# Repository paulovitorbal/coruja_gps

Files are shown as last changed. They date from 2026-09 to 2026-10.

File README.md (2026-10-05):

# coruja_gps — detector de radares embarcado

Projeto pessoal de estudo em sistemas embarcados: um alertador de radares e semáforos
sobre **Raspberry Pi Pico 2 W**, com firmware em **C++17 / Pico SDK**.

Lê telemetria de um GPS NEO-M8N por UART, confronta a posição com uma base local de
18.294 pontos e sinaliza em quatro zonas por display, LED RGB periférico e buzzer.

## Arquitetura

Subsistemas do Coruja GPS e o caminho do dado

Quatro subsistemas, e o dado atravessa todos eles. Um CSV vira `radares.bin` na
estação de trabalho; o binário é publicado por um servidor mínimo; a configuração vai
para o cartão à mão; e o aparelho, ao clique, lê o cartão, busca a base pela rede e
**a grava de volta no cartão**.

Essa última parte é o RF05: *"baixá-la e salvá-la no cartão"*, com a troca atômica do
RF05.2 — baixa para `radares.tmp`, valida, renomeia a atual para `radares.bak` e só
então promove a nova. Queda de energia no meio de uma atualização não pode deixar o
aparelho sem base, porque a tela voltaria ao velocímetro normalmente e nada indicaria
a perda.

A cópia do `radares.bin` para o cartão à mão é só a **carga inicial**, e é opcional:
sem base o aparelho sobe, avisa, e o primeiro clique busca tudo pela rede.

No boot a base é lida **em fluxo** do cartão, decodificando direto no vetor de pontos.
Não é preferência de estilo: o arquivo tem 214 KB e o vetor ocupa 281 KB, e não existe
instante em que os dois caibam nos 181 KiB livres. Se o `radares.bin` não validar, o
firmware cai para o `radares.bak` — e avisa que está operando pela reserva.

**De onde vem o CSV é problema de quem monta** — o projeto não presume fonte nenhuma,
e por isso ela aparece no diagrama como uma nuvem anônima.

O que ainda não existe está tracejado e em cinza: gravar no cartão o que foi baixado,
o GPS, o display e o buzzer.

### Dentro do firmware

Módulos do firmware e a fronteira do hardware

A divisão que mais importa é a **fronteira do hardware**. Em verde, o que compila e é
testado no host — validação de formato, decodificação de quadratura, verificação de
download, análise de URL. São 180 testes que rodam sem placa nenhuma, e é o que torna
possível trabalhar neste projeto enquanto um módulo não chegou pelo correio.

Em laranja, o que só existe no Pico. Esses módulos são finos de propósito: o
`ClienteHttp` entrega pedaços a quem chamou em vez de acumular, e quem verifica é o
`nucleo`.

### Como regerar os diagramas

As fontes são versionadas em `docs/*.puml`; os SVG são gerados.

```bash
plantuml -tsvg docs/arquitetura.puml docs/firmware.puml
```

## Base de pontos

O firmware carrega `radares.bin`, um binário compacto de 12 bytes por ponto,
ordenado por latitude. Ele é produzido por `converte.py` a partir de um CSV no
**padrão iGO8**:

```
X,Y,TYPE,SPEED,DirType,Direction
-44.021044,-19.799916,1,30,1,257
```

```bash
python3 converte.py base_igo8.txt radares.bin
```

**Outro formato de entrada?** Escreva seu próprio parser — e não reimplemente o
formato binário. `formato_radares.py` expõe as enumerações e o escritor:

```python
from formato_radares import Ponto, TipoPonto, Sentido, escreve

pontos = [Ponto(lat=-19.799916, lon=-44.021044, limite=30, rumo=257,
                tipo=TipoPonto.RADAR_FIXO, sentido=Sentido.UNIDIRECIONAL)]
escreve(pontos, "radares.bin")
```

O `escreve()` cuida de quantização, flags, **ordenação por latitude** e CRC-32 — as
quatro coisas que um parser erraria em silêncio. A ordenação é a pior: a busca
binária do firmware depende dela e erra *sem avisar* se faltar.

Para testar, `formato_radares.le()` relê com as mesmas validações do firmware: se
aceita, o firmware carrega. Use `converte.py` (padrão iGO8) como modelo.

Obter a base é problema de quem monta: o projeto não presume fonte nenhuma.

---

## Alimentação e instalação no veículo

Alimentado pelo **pós-chave**, derivado na caixa de fusíveis. **O que entra no aparelho
é 12 V** — o conversor CC ficou para dentro.

Essa topologia mudou em 2026-09-21, e o motivo foi o buzzer. Ver `docs/adr/0009`.

```
bateria ─ caixa de fusíveis ─ piggyback ─ fusível 2 A ─ 1,5 mm² trançado (12 V)
                                                               │
                                              ┌────────────────▼──────────────┐
                                              │  conector de entrada, 3 vias  │
                                              └────────────────┬──────────────┘
                                                               │  dentro do gabinete
                                     ┌─────────────────────────┼───────────────┐
                                     │                         │               │
                          ┌──────────▼──────────┐   ┌──────────▼─────────┐     │
                          │ TVS 24 V ┬ 470 µF   │   │ conversor 12 V→5 V │     │
                          │ (bidir.) │ 50 V     │   │ NÃO isolado, ≥40 V │     │
                          └──────────┴──────────┘   └──────────┬─────────┘     │
                                                               │ 5 V           │ 12 V
                                                    ┌──────────▼─────────┐  ┌──▼──────────┐
                                                    │ Schottky → VSYS 39 │  │ buzzer, 2 v.│
                                                    └────────────────────┘  └─────────────┘
```

Consumo: **~145 mA em 12 V** (≈1,6 W) em condução normal, com pico de ~200 mA quando a
tensão cai a 9 V durante a partida. No lado de 5 V são ~162 mA normais e ~310 mA no
pior caso sustentado.

### O buzzer é alimentado em 12 V

O **SFM-20B é especificado para 3–24 V**. Em 5 V ele opera perto do mínimo da faixa; em
12 V, perto do meio — e para um piezo ativo a pressão sonora sobe bastante com a
tensão. O **R-32** registra a audibilidade com janelas abertas a 80 km/h como a
incerteza que sobrou do projeto, e nenhuma mudança de firmware a resolve. Esta resolve,
ou pelo menos ataca a causa certa.

O circuito não muda: o `BC337` tem `Vceo` de 45 V, a corrente é a mesma, e o
acionamento pela base continua em 3,3 V através de 1 kΩ. Não há roda-livre a
acrescentar — o buzzer é piezoelétrico, carga capacitiva.

**O `D2` foi removido em 2026-09-25**, justamente por isso: em antiparalelo com carga
capacitiva ele fica reversamente polarizado nos dois estados e nunca conduz. Fecha o
R-16.

O retorno do buzzer não vai ao GND por fio — vai **pelo transistor**. É chaveamento
pelo lado baixo: `+12 V → buzzer → coletor`, `emissor → GND`. Com o `Q1` cortado o
coletor sobe a ~12 V pelo próprio buzzer, que é por que, lendo a netlist parada, as
duas pernas parecem estar no mesmo potencial.

### 🔴 O 12 V agora está dentro do gabinete

Essa é a contrapartida, e é séria.

Antes, com o conversor do lado de fora, nada acima de 5 V entrava na caixa. Agora
entram 12 V, e eles convivem a centímetros de um trilho cujo máximo absoluto é 5,5 V.
**12 V no nó `VSYS` destrói Pico, GPS, display e cartão juntos.**

Três consequências práticas:

* **O conector de entrada tem 3 vias e o do buzzer tem 2**, e isso voltou a ser medida
  de **segurança**, não de robustez. A revisão anterior deste documento dizia que
  trocá-los "deixou de ser destrutivo" — aquilo valia enquanto só havia 5 V; não vale
  mais.
* **O fio de 12 V não é vermelho.** A convenção antiga mandava vermelho para 5 V *e*
  12 V; duas tensões com a mesma cor a três centímetros uma da outra é convite a erro.
  No `.fzz` o 12 V é **amarelo**.
* **O fio do coletor também está em 12 V** sempre que o transistor está cortado, ou
  seja, na maior parte do tempo. Não é só o `+12 V` que precisa de cuidado.

### Proteção da entrada de 12 V

O fusível protege o **fio** contra curto; ele não reage a sobretensão. Daí o **TVS
bidirecional de 24 V** (`P6KE24CA` ou `1.5KE24CA`) e um **eletrolítico de 470 µF /
50 V** em paralelo na entrada. O clamp de 24 V cai numa janela estreita: tem de ficar
acima de 16 V, porque a rede é 13,8 a 14,4 V com o motor ligado, e abaixo de 40 V,
porque é o máximo do conversor. O `24CA` clampa em 33,2 V.

**O que isso não resolve:** um *load dump* real chega a 60–120 V por até 400 ms, o que
contra um clamp de 33 V significa mais de 1 kW sustentado — nenhum TVS axial pequeno
sobrevive. O que ele cobre são os transientes frequentes e de baixa energia, que são os
que matam módulo barato no uso diário. Para o load dump, o projeto se apoia em o
alternador de carro moderno já clampar internamente em ~35 V, e isso é **suposição, não
medição**.

Dois detalhes que estragam tudo se errados: o sufixo **`CA`** significa bidirecional, e
a versão `A` montada ao contrário fica em curto permanente; e o **fusível vai antes** da
proteção no percurso do cabo, porque o modo de falha desejável de um TVS é curto.

### Três decisões que não são óbvias

**Pós-chave em vez de bateria direta com relé.** O pós-chave permanece energizado
durante a partida, então não há reinício na ignição. O relé foi descartado porque a
bobina consome 80–150 mA contra ~180 mA do aparelho inteiro — gastaria quase tanto
quanto liga — e o benefício dele (consumo parasita zero) já vem da chave de ignição.

**Fusível de 2 A, não 10 A.** Fusível protege o fio, não a carga. Com 10 A, uma falta
intermediária de 6 A não abriria o fusível mas aqueceria o condutor. O cabo de 1,5 mm²
suporta ~15 A e está sobredimensionado de propósito — mas o fusível acompanha a carga.

**Conversor não isolado, com entrada ≥ 40 V.** As duas condições importam por motivos
diferentes. A entrada ampla é pelo *load dump*: 60–120 V por dezenas de milissegundos
quando a carga do alternador sai, e módulos comuns de 35 V podem não sobreviver. O
**não isolado** é pelo buzzer: sem continuidade entre o negativo de 12 V e o do
aparelho, a corrente do buzzer não fecha pelo emissor do `Q1` e ele simplesmente não
toca. Um conversor isolado — que parece melhor no anúncio — quebraria o circuito.

E há um mínimo tão importante quanto o máximo: **a entrada tem de aceitar ~9 V**,
porque é onde o trilho cai durante a partida. Módulo com mínimo de 12 V reinicia o
aparelho a cada vez que se dá a chave.

### Ajuste opcional da saída do conversor

O Schottky derruba 0,3–0,45 V, então 5,00 V na saída deixam o `VSYS` em ~4,6 V. Se o
módulo for ajustável, regule para **5,35–5,45 V** e o `VSYS` chega a ~5,0 V. **Nunca
acima de 5,8 V** — o `VSYS` aceita no máximo 5,5 V. Meça antes de conectar.

Com o buzzer em 12 V isso deixou de ser crítico: o que dependia de tensão nominal saiu
do trilho de 5 V.

### Conectores do aparelho

| Conector | Vias | Pino A | Pino B |
| :--- | :---: | :--- | :--- |
| Entrada (único) | **3** (central sem uso) | **+12 V** | GND |

Desde 2026-09-25 o **buzzer é soldado direto**, sem conector: os dois fios saem da
placa e vão ao SFM-27 no painel da caixa. Com isso o aparelho tem **um só conector
externo**, e o risco de trocar um pelo outro — que a contagem de vias apenas
administrava — deixa de existir. O preço é serviço: separar a tampa exige dessoldar.

## Documentos

Leia nesta ordem:

| Documento | O que é |
| :--- | :--- |
| **`requirements.md`** | Requisitos funcionais e não-funcionais, matriz de interação homem-máquina e fluxo de telas. É a especificação. |
| **`bom_schematic.md`** | Lista de materiais e roteamento pino a pino, com as pinagens físicas conferidas nas placas. |
| **`formato_dados.md`** | Formato binário `radares.bin`, estratégia de carga em RAM e busca geográfica em dois estágios. |
| **`revisao_tecnica.md`** | Revisão técnica com rastreabilidade: o que foi achado, decidido e o que segue aberto. |
| **`montagem.md`** | Montagem física na caixa Patola PB-111: chassi, fixação, prateleira do GPS, isolamento e passagem de cabos. |
| **`previa_host.md`** | O produto inteiro rodando no host contra o simulador: o que a primeira integração validou, o defeito que achou e o que ela ainda não exercita. |
| **`roteiro_bancada.html`** | Procedimento de medição para imprimir, com quadro de registro das leituras. |

## Estado

**Decidido:** C++17 com Pico SDK · GPS+GLONASS a 4 Hz (piso 3 Hz) · conector JST-XH ·
GPS alimentado em 5 V · Zona de Semáforo silenciosa · buzzer escalonado em 3 faixas ·
LED RGB exclusivo de estado de via.

**Pendente de bancada** — ver `roteiro_bancada.html`:

| Item | Medida |
| :--- | :--- |
| R-05 | Vf dos LEDs verde e azul, e calibração das razões R:G (amarelo) e R:B (rosa) |
| R-13 | Tensão do trilho 3V3 sob carga, com backlight em 100% |
| R-17 | Consumo do buzzer e pinagem do transistor |
| R-14 | Inspeção: regulador de 3 pinos na placa GPS — **sem ele, 5 V destroem o módulo** |

**Escopo futuro:** desenho de telas e interfaces visuais.

## Esquemático no Fritzing

`coruja_gps.fzz` foi **gerado** e depois **ajustado à mão** no Fritzing:

```bash
python3 gera_fritzing.py    # ⚠️ sobrescreve o .fzz e DESCARTA o ajuste manual
```

> ⚠️ **O `.fzz` versionado contém trabalho manual que o gerador não reproduz:**
> roteamento dos fios com pontos de dobra, orientação de 16 peças e 4 notas rotulando
> os módulos representados por headers genéricos. Regerar descarta tudo isso.
>
> O gerador é a fonte da **netlist**; o `.fzz` é a fonte do **layout**. Ao mudar a
> fiação, o caminho é editar `NETS`, regerar num arquivo temporário, comparar as redes
> e então aplicar a mudança à mão no Fritzing — não sobrescrever.
>
> **Sem divergências conhecidas** (2026-09-21). O `.fzz` foi regerado a partir da
> netlist atual e depois roteado à mão, fechando o **R-29**.
>
> O anterior tinha acumulado cinco atrasos, e o pior era silencioso: ele trazia o LED
> como **cátodo comum**, que se liga de forma oposta ao ânodo comum real (R-33). Quem
> montasse por ele teria um LED que não acende, sem pista do motivo. Os outros quatro
> eram os GPIO de vermelho e azul trocados (R-35), resistores de 68 Ω onde as medições
> pediam 470 e 150 (R-05), leitor SD com 8 pinos em vez de 9 (R-40) e o display como
> ST7789 240×240.
>
> A lição que fica: um `.fzz` editado à mão **não avisa quando envelhece**. A defesa
> aqui foi comparar netlists entre o gerado e o versionado — vale repetir isso antes de
> cada montagem, e não confiar na memória de quantas correções entraram desde a última
> vez. O documento de referência para montagem continua sendo o `bom_schematic.md`.

A netlist vive em `NETS`, dentro de `gera_fritzing.py`, transcrita do
`bom_schematic.md`. Mudou a fiação? Edite ali e regenere.

O `fritzing_geo.py` calcula a posição real de cada pino: lê o SVG de breadboard da
peça, resolve o mapeamento `connector → svgId` do `.fzp` e aplica os transforms de
grupo. Sem isso os fios sairiam desenhados fora dos pinos. A escala da cena
(90 unidades por polegada) foi medida empiricamente contra um sketch existente.

**Dependências do gerador:** Fritzing instalado (a biblioteca de peças é lida de
`/Applications/Fritzing.app`) e um sketch com a peça do Pico, de onde ela é
reaproveitada e embutida no `.fzz`.

Quatro módulos não têm peça na biblioteca — NEO-M8N, ST7789, leitor microSD e
KY-040 — e são representados por headers fêmea rotulados, com a contagem correta de
pinos. A peça de microSD que existe na biblioteca tem **zero conectores**, é
inutilizável.

Na vista protoboard há fios reais, coloridos por rede: **preto** = GND,
**vermelho** = 5 V, **azul** = 3V3, e cores distintas por grupo de sinal. Esquemático
e PCB usam conexões diretas, exibidas como ratsnest.

## Datasheets

| Arquivo | O que é |
| :--- | :--- |
| `NEO-M8_datasheet_UBX-15031086-R14.pdf` | Datasheet u-blox do módulo GPS, **revisão R14**. É a revisão citada em todas as análises deste projeto. |
| `NEO-M8_datasheet_UBX-15031086-R11.pdf` | Mesmo documento, **revisão R11** — anterior. Mantida para comparação; em caso de divergência, vale a R14. |
| `adafruit-microsd-spi-sdio.pdf` | Guia do breakout microSD. Fonte da polaridade do `DET` (cartão presente = ALTO, pull-up de 4,7 kΩ na placa) e da confirmação de que há pull-up em todos os pinos SPI. |

Valores extraídos do datasheet do GPS e usados no projeto: limites elétricos
(`VCC` 2,7–3,6 V, `VIN` 0–`VCC`, `IPIN` 10 mA), correntes (`ICCP` 67 mA, tracking
30 mA, `ICC_RF` até 50 mA), faixa térmica (−40 a +85 °C, **operação e
armazenamento**) e teto de taxa de navegação (**5 Hz** em GPS+GLONASS, 10 Hz em
GNSS único).

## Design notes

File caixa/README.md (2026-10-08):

# Caixa impressa do coruja_gps

Modelo **paramétrico em OpenSCAD**. Caixa com batente interno e tampa que desce
por cima, presa por atrito — sem parafuso.

> **O que está versionado aqui é a fonte `.scad`.** Os STLs são artefato: cada
> render muda o arquivo inteiro e o git guarda cada versão por completo. São
> ~2 MB por corpo — a mesma razão pela qual o `.uf2` do firmware fica em
> *release* e não no repositório.

---

## Gerar os STLs

```sh
./gera_stl.sh                    # gera neste diretório
./gera_stl.sh ~/Downloads        # ou onde você quiser
```

Se o OpenSCAD não estiver no caminho padrão do macOS:

```sh
OPENSCAD=/usr/bin/openscad ./gera_stl.sh
```

Leva alguns minutos por peça — a geometria usa muita operação booleana.

O script **verifica e recusa** o resultado se houver material dentro de um vão
da traseira. Ver *"A verificação, e por que ela existe"* abaixo.

---

## As três peças

| Arquivo gerado | O que é |
| :--- | :--- |
| `caixa.stl` | corpo, **modelo A** — encoder · display · buzzer |
| `caixa_destro.stl` | corpo, **modelo B** — buzzer · display · encoder |
| `tampa.stl` | tampa, **a mesma para os dois**. Imprima uma só |

Externo 130 × 130 × 67 mm, parede e piso de 3 mm.

### Qual dos dois corpos

A geometria é a mesma; muda de que lado fica o encoder. **Não existe modelo
"certo" em abstrato** — depende de onde a caixa é montada no painel e de qual
mão alcança o botão. Simule o gesto antes de imprimir.

O `coruja_caixa_destro.scad` não duplica nada: ele inclui o principal e
sobrepõe um parâmetro.

### Material é decisão térmica, não estética

O painel do carro mediu **92 °C**. Isso elimina quase tudo — ver `montagem.md`
§2 na raiz do repositório.

---

## O conector de alimentação

Furo de **⌀12,5 mm na traseira, centrado**, para um **GX12-2** ("conector
aviação"). É o único conector externo do aparelho e traz os 12 V do pós-chave;
o conversor fica dentro do gabinete.

**Por que GX12 e não jack P4.** O TVS da entrada é bidirecional: ele clampa
transiente mas **não bloqueia inversão de polaridade**, que chega direta ao
conversor. A propriedade que importa é o **chaveamento mecânico** — só entrar
de um jeito. Barril 5,5 × 2,1 falha nisso, porque centro-positivo é convenção e
não garantia, e ainda não retém contra vibração.

**Centrado** porque existem as versões canhota e destra: no meio, a traseira
fica igual nas duas e a aparência não depende do lado de montagem.

**Acima** do rasgo do cartão e da abertura do USB, e não ao lado: o rasgo
atravessa o centro da parede, e naquela altura não havia como centralizar.

**Montagem:** pinos **machos na caixa**, fêmea no cabo. O cabo do carro fica
energizado com a chave ligada; a caixa desligada está morta, e contato exposto
pertence ao lado morto.

### ⚠️ Duas medidas ainda não conferidas

| | valor | o que é |
| :--- | ---: | :--- |
| `GX12_FURO` | 12,5 mm | ⌀12 nominal + 0,5 de folga de impressão |
| `GX12_VAO_PORCA` | 18,0 mm | diâmetro que permanece com 3 mm de parede, para a porca assentar |

Generosos de propósito enquanto não houver paquímetro sobre o conector
comprado: errar para mais custa folga, errar para menos arruína a peça depois
de impressa.

🔴 **E há uma terceira cota, que não tem valor aqui e pode reprovar o
desenho: o comprimento da rosca.** A espessura máxima de painel é ele menos a
altura da porca. Se sobrar pouco, os 3 mm de parede não fecham — e aí as outras
duas medidas não importam.

As três estão registradas como pendência **M-14** no `montagem.md`.

O reforço em volta do furo é um **anel**, e não um disco, por causa do segundo
valor — engrossar a parede sob a porca consome o comprimento útil de rosca.
Quem limita a espessura aqui não é a impressão, é a peça comprada.

---

## A verificação, e por que ela existe

Em **08/10/2026** o furo do conector foi acrescentado e a peça saiu com o rasgo
do cartão **tapado**: o anel de reforço, somado depois do `difference`, descia
por trás do recorte e o preenchia.

O que falhou não foi o render. Ele deu `Simple: yes`. Uma conferência de malha
procurou o furo e **o encontrou**, no lugar certo, com o diâmetro certo. As
duas verificações respondiam *"o furo existe?"* quando a pergunta era **"alguma
coisa sólida está passando por onde devia haver vão?"**. O defeito apareceu
quando alguém abriu o modelo e olhou.

Daí as duas guardas, que cobrem portas diferentes:

| guarda | onde | pega |
| :--- | :--- | :--- |
| `assert()` | no `.scad` | parâmetro que põe o anel em cima de um recorte, ou contra o batente |
| `verifica_caixa.py` | sobre o STL | material dentro de um vão, qualquer que seja a causa |

```sh
python3 verifica_caixa.py caixa.stl
```

O `gera_stl.sh` roda a segunda automaticamente e falha se ela reprovar.

> ⚠️ O verificador repete, em Python, as coordenadas dos recortes que o `.scad`
> calcula. Se elas mudarem lá e não aqui, ele passa a medir outra coisa — é o
> preço de verificar a **malha** em vez do modelo, e vale porque a malha é o
> que vai para a impressora.

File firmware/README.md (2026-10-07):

# Firmware — instalação, build e testes

Regra 6 do `coding_rules.md`. Este documento cobre o firmware; a montagem do
hardware está no `bom_schematic.md` e os requisitos no `requirements.md`.

## Dependências

| Ferramenta | Para quê | Instalação no macOS |
| :--- | :--- | :--- |
| CMake ≥ 3.13 | build dos dois alvos | `brew install cmake` |
| Ninja | gerador | `brew install ninja` |
| GoogleTest | suíte de testes | `brew install googletest` |
| Arm GNU Toolchain | compilar para o RP2350 | ver o aviso abaixo |
| Pico SDK ≥ 2.0 | biblioteca do alvo | `git clone --depth 1 https://github.com/raspberrypi/pico-sdk` |

> ⚠️ **Não use a formula `brew install arm-none-eabi-gcc`.** Ela instala um
> toolchain **só de C**: não vem com a biblioteca padrão de C++, e qualquer
> `#include <cmath>` ou `<cstdio>` falha com *"No such file or directory"*.
> Verificado com a 16.2.0 — não há um único `cmath` no Cellar.

O que serve é o toolchain oficial da Arm. O cask `gcc-arm-embedded` instala via
`.pkg` e **pede senha de administrador**, o que não funciona em terminal não
interativo. Dá para contornar extraindo o `.pkg` sem `sudo` e sem tocar em `/`:

```sh
brew fetch --cask gcc-arm-embedded          # só baixa, não instala
PKG=$(find ~/Library/Caches/Homebrew/downloads -name '*arm-gnu-toolchain*.pkg' | head -1)
pkgutil --expand-full "$PKG" /tmp/armx
mkdir -p ~/arm-gnu-toolchain && cp -R /tmp/armx/Payload/. ~/arm-gnu-toolchain/
export PATH="$HOME/arm-gnu-toolchain/bin:$PATH"
```

Ocupa ~1,0 GB. É o que está em uso aqui: **Arm GNU Toolchain 14.2.Rel1**.

O Pico SDK precisa do submódulo `lib/tinyusb` inicializado:

```sh
git -C "$HOME/pico-sdk" submodule update --init --depth 1 lib/tinyusb
```

### Variáveis de ambiente

Duas variáveis, e vale deixá-las permanentes em vez de exportar a cada sessão.

**fish** — em `~/.config/fish/config.fish`:

```fish
set -gx PICO_SDK_PATH $HOME/pico-sdk
fish_add_path $HOME/arm-gnu-toolchain/bin
```

**bash ou zsh** — em `~/.bashrc` ou `~/.zshrc`:

```sh
export PICO_SDK_PATH="$HOME/pico-sdk"
export PATH="$HOME/arm-gnu-toolchain/bin:$PATH"
```

Só o alvo Pico precisa delas. Os testes no host rodam sem nenhuma.

## Testes no host

Não precisa de ARM nem de placa. Ver `docs/adr/0001`.

```sh
cmake -S firmware -B firmware/build-teste -G Ninja -DCORUJA_TESTES=ON
cmake --build firmware/build-teste
ctest --test-dir firmware/build-teste --output-on-failure
```

### Dados de teste

A suíte roda **completa** num clone limpo. Ela usa uma fixture de 100 pontos
sintéticos versionada em `firmware/test/dados/fixture_igo8.txt`, que o CMake
converte em tempo de build chamando o próprio `converte.py` — então os testes
exercitam a cadeia inteira, conversor em Python e carregador em C++. Por isso
`python3` é dependência de build dos testes.

As coordenadas da fixture são pontos no Atlântico Sul aberto: **nenhuma é um
local real de fiscalização**. Ver `firmware/test/dados/README.md`.

Um teste extra carrega uma base completa e **se pula** por padrão. Para
exercitá-lo:

```sh
python3 converte.py sua_base.txt radares.bin
cmake -S firmware -B firmware/build-teste -G Ninja -DCORUJA_TESTES=ON \
      -DCORUJA_BASE_REAL="$PWD/radares.bin"
```

### Rodar um teste só

```sh
./firmware/build-teste/test/testes --gtest_filter='Decodificador.*'
./firmware/build-teste/test/testes --gtest_filter='*Wraparound*'
./firmware/build-teste/test/testes --gtest_list_tests   # lista tudo
```

### Cobertura

O mínimo do projeto é 80%.

```sh
cmake -S firmware -B firmware/build-cov -G Ninja \
      -DCORUJA_TESTES=ON -DCORUJA_COBERTURA=ON
cmake --build firmware/build-cov && ./firmware/build-cov/test/testes
cd firmware/build-cov && xcrun gcov -b src/CMakeFiles/coruja_nucleo.dir/nucleo/*.gcda
```

## Firmware para o Pico 2 W

```sh
cmake -S firmware -B firmware/build-pico -G Ninja -DPICO_BOARD=pico2_w \
      -DPICO_TOOLCHAIN_PATH="$HOME/arm-gnu-toolchain"
cmake --build firmware/build-pico
```

Com as variáveis já no config do shell. Sem elas, prefixe a linha do `cmake`
com `PICO_SDK_PATH=$HOME/pico-sdk PATH=$HOME/arm-gnu-toolchain/bin:$PATH`, que
funciona igual em fish, bash e zsh.

Sai `firmware/build-pico/coruja_gps.uf2`.

### Conferir o orçamento de memória

```sh
arm-none-eabi-size firmware/build-pico/coruja_gps.elf
```

Medição de 2026-09-17, com núcleo, log, LED e encoder:

| | Uso | De |
| :--- | ---: | ---: |
| Flash | **66,6 KiB** | 4096 KiB |
| SRAM | **284,2 KiB** | 520 KiB |
| Livre | **235,8 KiB** | |

A base é reserva estática de 24.000 pontos, 281,2 KiB. Ver `docs/adr/0006`
para por que isso **não** é o teto de 40.000 do formato. Para gravar: segure `BOOTSEL`, conecte o
USB e copie o `.uf2` para o volume `RP2350` que aparece.

O `stdio` sai pelo **USB-CDC**, não pela UART — a UART0 fica para o GPS. Para
ler o log: `screen /dev/tty.usbmodem* 115200`.

## Configuração

```sh
python3 scripts/gera_config.py --destino /Volumes/NOME_DO_CARTAO
```

Gera o `coruja.cfg` no cartão — **sem comentários**. Eles ficam no
`coruja.cfg.exemplo`, versionado, que é onde se lê o que cada chave faz.

> ⚠️ O firmware carrega o arquivo INTEIRO para a RAM, e os comentários deste
> gerador são quatro quintos dele. O arquivo enxuto tem ~200 bytes; com
> comentários, passava de 5 KB — e o leitor reservava 2 KB. O sintoma foi
> `sem configuração utilizável` no OTA e o aparelho sem nome na tela, com um
> arquivo que lia perfeitamente em qualquer outra ferramenta. Hoje o leitor e
> o gravador usam a **mesma** constante, e há teste que falha se divergirem.

**Só entra nele o que varia por instalação:**

| Chave | |
| :--- | :--- |
| `wifi_ssid_N` / `wifi_senha_N` | até 5 redes, **em ordem de prioridade** |
| `url_versao` | devolve uma linha de texto qualquer, comparada como texto |
| `url_base` | entrega o `radares.bin`, em HTTPS |
| `url_envio` | para onde subir log, viagens e infrações — **vazio desliga** |
| `token_aparelho` | o segredo que identifica esta unidade no servidor |

Brilho, fuso, tolerâncias e calibração do LED ficam **no código**. O critério está no
`docs/adr/0002`: se mudar o valor muda o comportamento de segurança, é especificação e
não configuração.

> ⚠️ O `coruja.cfg` contém a senha do Wi-Fi e o **cartão é removível e legível
> por qualquer um**. Isso não é mitigável por software: use uma rede de
> convidados ou de IoT para o OTA, nunca a rede principal.

#### Enviar dados ao servidor

O item **enviar dados** do menu sobe `coruja.log`, `infracoes.log` e os
registros de viagem, e **apaga do cartão só o que o servidor confirmar ter
guardado** — manda, pergunta o CRC-32, compara, e só então apaga. Confirmar
antes de destruir dispensa manifesto no cartão e nunca perde dado por falha de
rede.

Precisa das **duas** chaves. Só a URL significaria mandar para um servidor que
aceita de qualquer um, e o firmware recusa a configuração pela metade.

O `token_aparelho` vai em **todas** as requisições, não só nos envios: é por
ele que o servidor sabe qual unidade está falando, e é o que faz os registros
de dois carros não se misturarem. Se o servidor tiver lista de aparelhos, ele
recusa até o download da base sem token.

Ele vai no cabeçalho `X-Coruja-Token`, em **todas** as rotas.

Houve uma versão em que ia como `?t=` na URL dos GET, porque o `http_client`
do lwIP montava o pedido internamente e não tinha onde encaixar cabeçalho
próprio. Com TLS o transporte foi reescrito sobre `altcp`, o gancho passou a
existir, e o segredo saiu da URL — onde entrava no log de acesso do servidor
e de qualquer proxy no caminho.

> ✅ **O envio fala TLS** desde 2026-10-06, pelo mesmo `ClienteTls` do
> download. O certificado é verificado contra três raízes embutidas no
> firmware, e `MBEDTLS_SSL_VERIFY_REQUIRED` faz o handshake abortar quando
> não bate — o padrão do lwIP é `OPTIONAL`, que verifica e deixa passar.
>
> ⚠️ Isso exige **o relógio acertado**: sem hora, todo certificado é recusado
> por "ainda não vale". Ver `servidor_ntp`.

Um arquivo que **cresceu durante o envio** fica no cartão, mesmo entregue: o
`coruja.log` e o registro da viagem em curso continuam sendo escritos enquanto
a remessa roda, e apagar depois de confirmar N bytes destruiria os que vieram
depois. Ver `servidor/README.md` para o outro lado.

### Testes do gerador

```sh
python3 -m unittest discover -s scripts/testes
```

Usa `unittest` e não pytest: todo o Python deste projeto é **stdlib-only** por escolha.

Dois testes amarram o gerador ao parser em C++, que estão em linguagens diferentes: o
C++ lê o `coruja.cfg.exemplo` versionado e falha se o formato divergir, e o Python
compara suas constantes de limite com as do `Configuracao.h`.

## Organização

```
firmware/src/
├── placa/           Pinos.h — mapa único de GPIO, com invariantes em static_assert
├── nucleo/          lógica pura — tipos, Geo, base de radares, config
├── log/             Logger (interface) + LoggerConsole
├── led/             Cor, LedRgb (interface), LedRgbAnodoComum (hardware)
├── encoder/         DecodificadorQuadratura e AntiRepique (puros),
│                    Encoder (interface), EncoderKy040 (hardware)
├── app/             ModoTesteEncoder e ModoCalibracao — lógica de bancada
├── buzzer/          a fazer
├── armazenamento/   a fazer — cartão SD
├── display/         a fazer — módulo ainda não chegou
└── gps/             a fazer — módulo ainda não chegou
firmware/test/
├── apoio/           mocks compartilhados
└── <espelha src/>
```

A regra de pertencimento está no `docs/adr/0001`: **se precisa de um cabeçalho
do Pico SDK, vai para `coruja_portes`; caso contrário, fica no alvo portável.**

### Mapa de pinos

`src/placa/Pinos.h` é a **fonte única** dos 18 GPIO que o firmware usa. Nenhuma classe
declara pino próprio: `LedRgbAnodoComum` e `EncoderKy040` consomem as constantes de lá.

Três invariantes são garantidas pelo **compilador**, não por revisão de código:

| Invariante | Mensagem se violada |
| :--- | :--- |
| Nenhum GPIO usado duas vezes | `dois periféricos foram atribuídos ao mesmo GPIO` |
| Todo GPIO existe no cabeçalho e não é do CYW43 (23, 24, 25, 29) | `algum GPIO não existe no cabeçalho do Pico...` |
| A contagem de 18 não mudou sem revisão | `a contagem de GPIO mudou: confira o bom_schematic.md...` |

As três foram **verificadas quebrando o arquivo de propósito** e conferindo que o build
para com a mensagem certa. Os testes de `placa/PinosTest.cpp` acrescentam o que o
`static_assert` não alcança: eles **fixam os valores** contra a fiação documentada, para
que trocar o GPIO 2 pelo 3 falhe dizendo qual periférico mudou de pino.

## Estado

| Componente | Peça em mãos | Interface | Implementação | Testes |
| :--- | :---: | :---: | :---: | :---: |
| `placa` — mapa de pinos | — | — | ✅ | ✅ |
| `nucleo` — tipos, Geo, LimiarInfracao, BaseRadares, LeitorConfig | — | — | ✅ | ✅ |
| `log` — Logger, console, mock | — | ✅ | ✅ | ✅ |
| `led` — LED RGB | ✅ | ✅ | ✅ | ✅ |
| `encoder` — KY-040 | ✅ | ✅ | ✅ | ✅ |
| `app` — modos de teste e de calibração | ✅ | — | ✅ | ✅ |
| `buzzer` — piezo ativo + BC337 | ✅ | ⬜ | ⬜ | ⬜ |
| `armazenamento` — microSD | ✅ | ⬜ | ⬜ | ⬜ |
| `display` — 2,4" 320×240 | ❌ Correios | ⬜ | ⬜ | ⬜ |
| `gps` — NEO-M8N | ❌ Correios | ⬜ | ⬜ | ⬜ |

O parsing de NMEA e a máquina de estados de zona são lógica pura e podem ser
escritos e testados **antes** dos módulos chegarem, contra mocks.

### O que está verificado e o que não está

* **Verificado:** a suíte de **143 casos** no host, com cobertura medida — 97,9%
  de linhas e **100% de ramos** no carregador, e **100% de linhas e ramos** em
  `Geo`, `LimiarInfracao`, `DecodificadorQuadratura`, `AntiRepique` e
  `ModoTesteEncoder`.
* **Verificado:** a compilação para ARM, com o toolchain oficial 14.2.Rel1 e o
  `pico-sdk` 2.3.1. Sai `coruja_gps.uf2` de 126 KB, e o orçamento de memória
  passou a ser medido no linker.
* **Não verificado:** nada rodou numa placa. O `src/main.cpp` compila e liga,
  mas o comportamento do modo de teste — inclusive se esquerda e direita saem
  na ordem certa — só se confirma na bancada.

## Modo de bancada de rede — o que o `main.cpp` roda hoje

Exercita o caminho de atualização OTA de ponta a ponta, com tudo saindo no
console USB.

| Gesto | O que acontece |
|---|---|
| girar à **direita** | agrava o estado de via: segura → âmbar → rosa → perigo |
| girar à **esquerda** | alivia, no sentido inverso |
| **clicar** | conecta no Wi-Fi, consulta a versão, baixa se mudou, verifica, desconecta |

As quatro cores são as medidas no R-05, não valores nominais. O ciclo **satura
nas pontas** em vez de dar a volta: numa tela de diagnóstico, voltar sozinho ao
verde depois do vermelho esconde justamente que se chegou ao fim.

### A configuração vem do cartão, lida no clique

Nada de credencial embutida no firmware — o RNF03 é explícito, e ler no clique
tem uma consequência prática boa: **trocar o cartão passa a valer sem
reiniciar** o aparelho, e a configuração nunca fica velha em RAM.

Ponha na raiz do cartão o `coruja.cfg` gerado por:

```bash
python3 scripts/gera_config.py --permitir-http --destino /Volumes/NOME_DO_CARTAO
```

No boot o cartão é só **inspecionado** pelo pino `DET` (GPIO 14), e o estado
sai no console — presente ou ausente. Era o que faltava: sem essa linha, os
dois casos davam exatamente o mesmo console, e a diferença só aparecia depois,
disfarçada de outro erro.

#### Qual partição

A que **contém o arquivo**, não a primeira que for FAT. Num cartão de duas
partições com a configuração na segunda, o padrão do FatFs diria "sem
configuração" com o arquivo no cartão. Ver ADR 0007 e R-38.

Partição lógica dentro de estendida continua fora do alcance, e o log diz
quantas partições FAT foram montadas — é essa a pista quando o arquivo está no
lugar errado.

### O que sai no console

Na varredura, cada rede vista com canal e RSSI, e quais são da lista. Depois o
IP obtido, o `GET`, e — no download — os seis campos do cabeçalho do
`radares.bin` ao lado do que de fato chegou:

```
[base] ---- cabecalho do radares.bin recebido ----
[base]   magic        : 'RDR1' (0x31524452)
[base]   versao       : 1
[base]   exp_escala   : 5  (coordenadas x10^5)
[base]   tam_registro : 12 B
[base]   n_pontos     : 18294  (declarados)
[base]   crc32        : 0xD290D536  (do cabecalho)
[base] ---- e o que de fato chegou ----
[base]   bytes        : 219544  (219528 de dados)
[base]   pontos       : 18294  (confere)
[base]   crc32        : 0xD290D536  (confere)
```

### O que ainda não acontece

**Nada é gravado.** O destino do `radares.bin` é o cartão, e o leitor não
existe — o arquivo é verificado *em fluxo* e descartado. A versão confirmada
vive em RAM, então reiniciar faz o próximo clique baixar de novo.

A verificação em fluxo é obrigatória, não uma escolha: o arquivo tem 214 KB e
a base já reserva 281 KB dos 520 KB da placa. Guardar o download inteiro para
só então validá-lo não cabe — e não vai caber nem com o cartão, porque aí o
destino é o cartão.

O `VerificadorDownload` confere cabeçalho, contagem e CRC-32, **na mesma ordem**
do `carrega_base`. Ordenação por latitude e domínio de cada registro exigem os
bytes na mão e continuam com a carga. Um arquivo aprovado no download ainda
pode ser recusado na carga, e isso é correto: são perguntas diferentes.

### Limites conhecidos

- **Sem TLS.** Uma URL `https` é recusada com mensagem própria, não baixada em
  claro: baixar em claro o que diz `https` seria mentir sobre o RF05.2 no ponto
  exato em que ele importa. Ver o README do `servidor/`.
- **Sem IPv6.** `http://[::1]:8080/x` é recusado com motivo próprio, em vez de
  ir falhar no DNS com uma mensagem que não explica nada.
- **Conexão episódica.** O rádio sobe no clique e cai ao fim, sempre — inclusive
  nos caminhos de erro.

## Modo de calibração

O firmware atual roda o **modo de calibração**, que fecha a metade pendente do
**R-05**: as razões de PWM do âmbar e do rosa. Não precisa de GPS, cartão nem
display.

| Ação | Efeito |
| :--- | :--- |
| **Girar** | ajusta o canal variável do item atual, 5 de duty por detente |
| **Clicar** | avança: vermelho → verde → azul → âmbar → rosa → volta |

Nas compostas o **vermelho fica fixo em 100%** e o encoder move o outro canal.
Não é simplificação: é a forma como `led/Calibracao.h` guarda as cores, com o
canal vermelho em 255 e só o secundário variando.

Ao dar a volta, o log imprime o bloco pronto para transcrever:

```
[INFO ] calib: ---- calibracao do R-05, para o gera_config.py ----
[INFO ] calib:   duty do verde no ambar : 0.45
[INFO ] calib:   duty do azul no rosa   : 0.60
[INFO ] calib:   (o vermelho das duas fica em 1,00 por construcao)
[INFO ] calib:   canais isolados: R=1.00  G=1.00  B=1.00
```

> ⚠️ **Julgue o rosa ao lado do vermelho, e sob sol direto.** É o item crítico:
> se os dois se confundirem, a faixa de margem parece Zona de Perigo ao
> motorista, que é o oposto da intenção do RF03.4.

De passagem ele valida a fiação inteira: os três canais acendem isolados —
inclusive o **verde**, que o modo de teste anterior nunca acendia — e o giro e
o clique exercitam o encoder. Se o giro à direita **diminuir** o brilho em vez
de aumentar, `CLK` e `DT` estão invertidos: construa com
`EncoderKy040(true, /*invertido=*/true)` em vez de mexer na fiação.

### O modo de teste anterior continua disponível

Esquerda vermelho, direita azul, clique apaga. Troque `ModoCalibracao` por
`ModoTesteEncoder` no `src/main.cpp` — a classe continua no projeto e testada.

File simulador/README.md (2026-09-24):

# Simulador de GPS

Faz o papel do NEO-M8N numa porta serial, para que o firmware possa ser
exercitado sem o módulo — e sem sair de casa.

```bash
python3 simula_gps.py
```

Ele cria um terminal virtual e imprime o caminho do dispositivo. Qualquer
programa abre esse caminho como abriria `/dev/cu.usbserial…`:

```
  rota  : rota_eixao.csv, 16.53 km por sentido
  volta : 33.05 km (ida e volta)
  serial: /dev/ttys012
  taxa  : 4 Hz
  teclas: a acelera · d desacelera · 0 para · q sai

  volta   1 |  12.4% | 60.0 km/h | norte | -15.82931,-47.92104
```

## A rota não foi inventada

Ela é a linha de centro do **Eixão (DF-002)**, derivada de 450 nós do
OpenStreetMap — `ref=DF-002` na caixa do Plano Piloto. O `gera_rota.py`
consulta a Overpass API e escreve o `rota_eixao.csv`, que é versionado para o
simulador rodar sem rede.

Coordenadas inventadas passariam por reais e ninguém saberia. Um simulador que
anda por uma via imaginária valida o firmware contra ficção — e o pior é que
ele *pareceria* funcionar.

**Por que isso importa na prática:** ao longo de uma volta o veículo passa a
menos de 300 m de **50 radares reais** da base, sendo 35 a menos de 100 m. A
maioria é de 60 km/h, com alguns de 80 — e há um de limite `0`, que é o caso
que o R-19 levantou. Dá para exercitar as quatro zonas só variando a
velocidade.

## Duas decisões que o simulador copia do módulo real

**Rumo em branco com o veículo parado.** O NEO-M8N não informa direção sem
deslocamento. Reproduzir isso é metade do valor do simulador: é o caso que
quebra parser desatento, que trataria o campo vazio como zero e apontaria o
veículo para o norte.

**4 Hz**, que é a taxa do RF01.4. Emitir mais rápido esconderia problemas de
acompanhamento que o aparelho teria no carro.

## Limitações honestas

**A linha de centro é média das duas pistas.** Elas ficam a ~40 m uma da
outra, e a suavização deixa uma irregularidade residual de ~5° por trecho. Para
alertas com raio de 300 m isso é ruído; para julgar filtro de rumo por sentido,
não confie.

**Não há ruído, nem perda de fix, nem cold start.** Todo fix é válido. Testar
o RF07 e o comportamento sem sinal exige acrescentar isso — hoje não está.

**A hora é a do computador**, em UTC, não a do relógio do satélite.

## Regerar a rota

```bash
python3 gera_rota.py                      # consulta a Overpass
python3 gera_rota.py --de-arquivo x.json  # de uma resposta ja baixada
```

O gerador tenta três espelhos: o principal devolve `504` sob carga com alguma
frequência, e isso não é motivo para desistir da rota.

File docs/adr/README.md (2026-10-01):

# Registros de Decisão Arquitetural

Formato Nygard: contexto, decisão, consequências. Um arquivo por decisão,
numerado e imutável — decisão revista ganha um ADR novo que **supera** o
anterior, e o antigo fica marcado como superado em vez de ser editado.

| # | Decisão | Data | Estado |
| :--- | :--- | :--- | :--- |
| [0001](0001-alvo-duplo-host-e-pico.md) | Um CMake com alvo duplo: testes no host, firmware no RP2350 | 2026-09-17 | aceita |
| [0002](0002-onde-vive-a-configuracao.md) | Credenciais no cartão, calibração compilada | 2026-09-17 | aceita |
| [0003](0003-idioma-dos-identificadores.md) | Domínio em português, infraestrutura em inglês | 2026-09-17 | aceita |
| [0004](0004-testes-contra-a-base-real.md) | Fixture sintética versionada, em vez de pular testes | 2026-09-17 | aceita |
| [0005](0005-taxa-de-amostragem-do-encoder.md) | Encoder amostrado a 1 ms, não no laço de 4 Hz | 2026-09-17 | aceita |
| [0006](0006-orcamento-de-memoria-verificado-pelo-compilador.md) | `Ponto` em 12 B e capacidade separada do teto de formato, com `static_assert` | 2026-09-17 | aceita |
| [0007](0007-fatfs-adotado-em-vez-de-escrito.md) | FAT32 por biblioteca adotada, e a partição escolhida pelo arquivo | 2026-09-20 | aceita |
| [0008](0008-formato-do-cartao.md) | Cartão em FAT32 com MBR, pela compatibilidade entre os três sistemas | 2026-09-20 | aceita |
| [0009](0009-doze-volts-dentro-do-gabinete.md) | 12 V entra no gabinete, e o buzzer é alimentado nele | 2026-09-21 | aceita |
| [0010](0010-sem-card-detect.md) | Sem card detect: cartão ausente e ilegível são o mesmo caso | 2026-09-22 | aceita |
| [0011](0011-medir-antes-de-mitigar.md) | Montar com o que está em mãos; mitigações térmicas contingentes à medição | 2026-10-01 | aceita |

## Decisões anteriores a este diretório

Três decisões de peso foram tomadas e justificadas antes de existir código, e
estão registradas nos documentos de especificação em vez de aqui. Não foram
duplicadas de propósito — o registro canônico é o documento:

| Decisão | Onde está | Achado |
| :--- | :--- | :--- |
| Carga integral em RAM, sem particionamento | `formato_dados.md` §1 | R-02 |
| Distância equirretangular em vez de Haversine | `formato_dados.md` §4.1 | R-03 |
| C++17 com Pico SDK em vez de MicroPython | `formato_dados.md` §9 | L-08 |

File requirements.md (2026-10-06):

# 📑 Documentação de Requisitos e Interações Homem-Máquina (IHM)

**Projeto:** Detector de Radares GPS Inteligente
**Plataforma:** Raspberry Pi Pico 2 W (RP2350) — **C++17 com Pico SDK**
**Revisão:** 2 — 2026-09-15
**Base de dados:** 18.294 pontos (`base_igo8.txt` → `radares.bin`)

> **Revisão 2:** incorpora as correções de `revisao_tecnica.md` e as decisões de
> `formato_dados.md`. Rastreabilidade ao final do documento. Itens marcados
> **[SUPOSIÇÃO]** são recomendações aplicadas na ausência de decisão explícita —
> revisar e confirmar ou reverter.

## 🎯 1. Escopo e Objetivos do Sistema

O objetivo do sistema é atuar como um assistente de condução inteligente embarcado. Ele
deve calcular a telemetria do veículo via satélite (coordenadas, velocidade e rumo) e
confrontar esses dados em tempo real com uma base local de radares e semáforos para
prever a aproximação dos pontos de interesse e emitir alertas visuais, periféricos e
sonoros de forma contextualizada.

A base de origem é distribuída no padrão iGO8 (`base_igo8.txt`) e é convertida em um
formato binário compacto (`radares.bin`) **fora do dispositivo**, conforme RF06.

---

## 📋 2. Requisitos Funcionais (RF)

### [RF01] Telemetria em Tempo Real

O sistema deve ler os dados brutos NMEA do módulo GPS NEO-M8N a uma taxa de amostragem
**nominal de 4 Hz, com piso aceitável de 3 Hz** *(ver RF01.4)*, extraindo:

* Latitude e Longitude em graus decimais.
* Velocidade atual convertida para km/h.
* Rumo (azimute) do veículo em graus (0,0° a 359,9°).

#### [RF01.1] Sentença e validação

* O parser deve aceitar **`$GNRMC` e `$GPRMC`**. O talker `GN` só aparece com
  multi-GNSS ativo; em modo GPS-only a sentença vira `GP` e um parser fixado em `GN`
  não casaria nada — falha silenciosa total.
* Toda sentença deve ter o **checksum NMEA validado** antes do uso. Sentença com
  checksum inválido é descartada silenciosamente e não atualiza a telemetria.
* O campo de status da RMC (`A` = válido / `V` = alerta) deve ser verificado; sem fix
  válido, aplica-se o RF07.

#### [RF01.2] Configuração obrigatória do módulo

Configuração de fábrica, conforme datasheet UBX-15031086 (Tabela 15): **UART a 9600 bps,
8 bits, sem paridade, 1 stop bit, autobauding desabilitado**, com **sete** sentenças NMEA
ativas — `GGA, GLL, GSA, GSV, RMC, VTG, TXT`. A GSV sozinha gera múltiplas sentenças
quando há muitos satélites visíveis, e o total por época passa facilmente de 500 bytes.
A 9600 bps (960 B/s), **nem 1 Hz cabe com folga** e 4 Hz é impossível.

O firmware deve enviar, e reenviar a cada boot:

| Comando UBX | Ação |
| :--- | :--- |
| `CFG-RATE` | período de medição = **250 ms (4 Hz)** — ver RF01.4 |
| `CFG-PRT` | baud rate da UART = **115200 bps** |
| `CFG-MSG` | desabilitar todas as sentenças **exceto RMC** |
| `CFG-CFG` | persistir configuração (BBR e EEPROM da placa, se presente) |

#### [RF01.4] Modo GNSS e taxa de navegação

O datasheet do NEO-M8N (UBX-15031086, Tabela 1) limita a taxa máxima de navegação
conforme o modo de GNSS:

| Modo GNSS | Taxa máx. | Precisão horiz. | Cold start | Talker NMEA |
| :--- | :---: | :--- | :---: | :---: |
| **GPS + GLONASS** *(padrão de fábrica)* | **5 Hz** | 2,5 m · 2,0 m c/ SBAS | 26 s | `$GNRMC` |
| GPS apenas | 10 Hz | 2,5 m · 2,0 m c/ SBAS | 29 s | `$GPRMC` |

Os 5 Hz da especificação original eram **exatamente o teto** do módulo no modo padrão,
sem nenhuma folga: qualquer degradação por temperatura ou sinal fraco derrubaria a taxa
efetiva abaixo do requisito, sem aviso.

##### ✅ Configuração adotada (confirmada em 2026-09-15)

| Parâmetro | Valor |
| :--- | :--- |
| Modo GNSS | **GPS + GLONASS concorrente** (mantém o padrão de fábrica) |
| Taxa nominal | **4 Hz** (`CFG-RATE` = 250 ms) — 20% de folga sob o teto |
| **Piso aceitável** | **3 Hz** — abaixo disso é falha (RF01.5) |

##### Justificativa geométrica da banda

Deslocamento do veículo por amostra, contra o raio de alerta de 300 m:

| Velocidade | 4 Hz | 3 Hz | Pior caso como % do raio |
| :--- | ---: | ---: | ---: |
| 100 km/h (27,8 m/s) | 6,9 m | 9,3 m | 3,1% |
| **120 km/h** (33,3 m/s — maior limite da base) | 8,3 m | **11,1 m** | **3,7%** |

O custo do piso de 3 Hz é **no máximo um período de amostragem de antecedência**, ou
seja 333 ms — que a 120 km/h são 11 m dos 300 m de raio. O alerta efetivo cairia de
300 m para ~289 m no pior caso, contra uma janela de aviso de 9,0 s a essa velocidade.
Irrelevante para a função.

Manter a recepção concorrente preserva a disponibilidade de satélites em cânion urbano,
que é onde está a maior parte dos pontos da base.

> *Alternativa registrada:* se em uso real houver perda de fix recorrente em cidade,
> GPS-apenas tem **precisão horizontal idêntica** (2,5 m) e teto de 10 Hz, ao custo de
> 3 s de cold start e 1 dBm de sensibilidade. Como o RF01.1 aceita os dois talkers, a
> troca não exige alteração no parser.

#### [RF01.5] Monitoramento da taxa de atualização

Definir um piso de 3 Hz só tem valor se o sistema souber quando o cruzou. O firmware
deve medir a taxa efetiva de fixes válidos em janela deslizante de 3 s e classificar:

| Faixa medida | Estado | Ação |
| :--- | :--- | :--- |
| ≥ 3,5 Hz | **nominal** | operação normal |
| 3,0 a 3,5 Hz | **degradado** | opera normalmente; registra o evento |
| **< 3,0 Hz** sustentado por 5 s | **falha** | ver RF07 e a tentativa de recuperação abaixo |

##### Por que este requisito existe

Taxa abaixo do nominal **quase nunca** significa que o receptor está com dificuldade — o
NEO-M8N entrega a taxa configurada enquanto tiver fix, ou perde o fix. As causas reais,
em ordem de probabilidade:

1. **`CFG-RATE` não foi aplicado** e o módulo continua no padrão de 1 Hz.
2. **UART saturada** — sentenças demais habilitadas ou baud rate baixo, com frames
   truncados (ver RF01.2).
3. Parser descartando sentenças por checksum inválido (ruído elétrico na linha).
4. Dificuldade genuína do receptor, em condições extremas.

Ou seja: **este monitor é primariamente uma verificação de que a configuração do RF01.2
pegou**, e só secundariamente um indicador de saúde. É a diferença entre descobrir um
erro de configuração na bancada e descobri-lo depois de meses rodando a 1 Hz sem notar.

##### Diagnóstico e recuperação

* Contar **separadamente** as sentenças recebidas com checksum inválido. Isso distingue
  "o GPS não está enviando" (causas 1, 2, 4) de "estamos falhando em interpretar"
  (causa 3) — dois problemas com correções opostas.
* Ao detectar estado de **falha**, reenviar a sequência de configuração UBX do RF01.2
  uma vez antes de escalar para o RF07. Cobre o caso de configuração perdida.
* A taxa medida e a contagem de checksums inválidos devem estar visíveis em algum ponto
  da interface (tela de diagnóstico ou tela de boot), não apenas em log.

#### [RF01.3] Conversão de velocidade

A sentença RMC entrega velocidade em **nós**. Conversão obrigatória:
`km/h = nós × 1,852`.

A velocidade usada na decisão de zona (RF03) deve passar por **média móvel de 3
amostras** para suprimir jitter. A latência resultante **varia com a taxa efetiva**:
750 ms a 4 Hz e 1000 ms no piso de 3 Hz.

Essa latência afeta apenas a comparação contra o limite da via (RF03). O **cálculo de
distância usa sempre o fix instantâneo**, nunca a média — a posição não deve ser
suavizada, ou o alerta atrasaria junto.

> *Referência de datasheet (Tabela 1):* precisão de velocidade de **0,05 m/s**
> (0,18 km/h) e de rumo de **0,3°**. A precisão de velocidade é excelente para a
> comparação contra o limite da via no RF03. A de rumo **não é qualificada por
> velocidade mínima** no datasheet, então o limiar de 5 km/h do RF02.3 permanece
> julgamento de engenharia, não especificação.

---

### [RF02] Processamento Geográfico Inteligente

O sistema deve calcular continuamente a distância entre o veículo e os pontos da base,
identificando o alvo válido mais próximo.

#### [RF02.1] Busca em dois estágios

Calcular a distância para todos os 18.294 pontos a cada ciclo não cabe no orçamento de CPU.
A base é mantida em RAM **ordenada por latitude crescente** (RF06) e a busca opera em
dois estágios:

1. **Busca binária** pela faixa de latitude `[lat − 300 m, lat + 300 m]` — a constante
   é 269 unidades de 10⁻⁵ grau. Custo: ~15 comparações de inteiros.
2. **Varredura da faixa** com descarte por longitude em **aritmética inteira**, sem
   trigonometria. O limiar de longitude depende de `cos(lat)` e deve ser calculado
   **uma vez por fix**, nunca por ponto.
3. **Cálculo de distância apenas nos sobreviventes.**

Custo medido sobre a base real, pior caso: 96 candidatos na faixa de latitude, dos quais
**24 chegam ao cálculo de distância**. Ver `formato_dados.md` §4.

> A ordenação por **latitude** e não longitude é deliberada: o grau de latitude mede
> 111,32 km em qualquer ponto do globo, então o limiar da busca binária é constante. Em
> longitude ele dependeria de cos(lat) e o índice ficaria distorcido de norte a sul.

#### [RF02.2] Cálculo de distância e precisão numérica

A FPU do RP2350 é de **precisão simples**. Um `float` tem ~7,2 dígitos significativos,
enquanto uma coordenada como `-23.537216` precisa de 8 — e a fórmula de Haversine
subtrai números próximos entre si, ampliando o erro justamente em distâncias curtas.

* **Obrigatório:** o cálculo deve operar sobre **diferenças** de coordenadas, não sobre
  valores absolutos em precisão simples.
* **Fórmula adotada — equirretangular:** erro inferior a 0,01% na faixa de 300 m, e
  custo de um `sqrtf` contra 2 sin + 2 cos + 1 asin + 1 sqrt da Haversine.

```
dy = Δlat × 111320
dx = Δlon × 111320 × cos(lat)
d  = √(dx² + dy²)
```

* Se a fórmula de Haversine for usada, deve ser em **`double`** (emulado em software,
  mas cabe no orçamento). Haversine em `float` sobre coordenadas absolutas é proibida.

#### [RF02.3] Filtro de Sentido (Rumo)

O sistema deve comparar o rumo do veículo com o rumo de captura do ponto, respeitando o
campo `DirType` da base (ver RF06):

| `DirType` | n na base | Regra |
| :---: | ---: | :--- |
| **0** — omnidirecional | 1.419 (7,8%) | **Nunca descartar** por rumo |
| **1** — unidirecional | 15.218 (83,2%) | Válido se a diferença circular ≤ **30°** |
| **2** — bidirecional | 1.657 (9,1%) | Válido no rumo indicado **e no oposto** |

* **Diferença circular obrigatória:** `min(|a−b|, 360−|a−b|)`. A diferença aritmética
  simples falha no wraparound — entre rumo 355° e ponto 5° ela dá 350° e descartaria um
  ponto válido.
* **Bidirecional** resolve-se dobrando a diferença para a faixa 0–90° em vez de 0–180°,
  sem caso especial no laço crítico.
* **Porta de velocidade:** abaixo de **5 km/h** o azimute do NEO-M8N é ruído aleatório.
  Nesse regime o filtro deve **abrir**, não fechar — descartar por um rumo que é ruído
  perderia pontos reais.

---

### [RF03] Alertas Contextuais (Zonamento)

O sistema deve alternar entre **4 zonas** de operação, com base no ponto alvo válido:

| Zona | Condição |
| :--- | :--- |
| **1. Zona Segura** | Nenhum ponto válido a ≤ 300 m |
| **2. Zona de Aproximação** | `limite > 0` **e** distância ≤ 300 m **e** `velocidade ≤ V_infra` — com dois sub-estados (RF03.9) |
| **3. Zona de Perigo** | `limite > 0` **e** distância ≤ 300 m **e** `velocidade > V_infra` |
| **4. Zona de Semáforo** | `limite == 0` **e** distância ≤ 300 m |

Onde **`V_infra`** é o limiar de infração definido no RF03.6 — **não** o limite da via.
A fronteira entre Aproximação e Perigo é o ponto em que a multa passa a existir, não o
ponto em que o limite é excedido.

#### [RF03.1] Condição de aproximação

Distância ≤ 300 m **não basta**. Após passar pelo ponto, a distância volta a crescer mas
permanece abaixo de 300 m por vários segundos — o alerta continuaria ativo e, na Zona de
Perigo, o buzzer seguiria tocando depois do radar. O alerta só é emitido se o ponto
estiver **à frente**:

* Comparar o azimute veículo→ponto com o rumo do veículo (diferença circular ≤ 90°), ou
* Exigir distância **decrescente** entre amostras consecutivas.
#### [RF03.2] Histerese

A troca de zona deve ter histerese para evitar disparos repetidos na fronteira:

* Entrada em zona de alerta: distância ≤ **300 m**.
* Saída para Zona Segura: distância > **340 m** ou ponto já ultrapassado.

Sem histerese, a zona alternaria em laço com a distância oscilando em torno do limiar.

Há uma **segunda histerese, independente desta**, nas fronteiras de velocidade: entre
Aproximação e Perigo, e entre as faixas sonoras do RF03.7. Ver RF03.7.
#### [RF03.3] Zona de Semáforo — `limite == 0`

**1.430 pontos da base (7,8%) têm limite 0** — são semáforos, que não têm limite de
velocidade aferível. A condição da Zona de Perigo (`velocidade > limite`) seria
satisfeita por **qualquer** velocidade acima de zero, fazendo cada semáforo disparar
fundo vermelho e buzzer em "metralhadora" até o carro parar.

Regras da Zona de Semáforo:

* O gatilho é **`limite == 0`**, e **não** `tipo == semáforo`. Os pontos de
  **Semáforo c/ Câmera** (`TYPE=3`) não aferem velocidade e portanto não têm limite —
  são estes os 1.430. Os 22 casos de `TYPE=3` com limite 50/60 são inconsistências da
  base e seguem pelo caminho normal de radar de velocidade.

> ⚠️ **Lacuna conhecida — `TYPE=2` é semáforo e não entra aqui.** Os **2.994 pontos
> de Semáforo c/ Radar** (`TYPE=2`) fiscalizam avanço de sinal **e** velocidade. Como
> têm limite, o gatilho por `limite == 0` não os pega, e o motorista não recebe
> nenhuma indicação de fiscalização de sinal em 2.994 cruzamentos urbanos. O
> zonamento pela velocidade está correto; o que falta é indicação visual combinada,
> usando o campo `TYPE` já preservado no registro. Ver **R-26** — decisão de forma
> deferida para a sessão de telas.
* **Nunca** entra em Zona de Perigo, em qualquer velocidade.
* **Buzzer permanentemente silencioso** nesta zona.
* Visor não exibe placa de limite — não há limite a exibir.
#### [RF03.4] Prioridade entre alertas simultâneos

Em área urbana densa, semáforo e radar de velocidade coexistem nos 300 m com frequência:
**29,2% dos semáforos da base têm radar de velocidade a menos de 300 m** (417 de 1.430).
A regra é exercitada com frequência, não é caso de borda.

##### Ordem de precedência (decisão do autor, 2026-09-15)

A precedência é **por categoria**, e só dentro de cada nível decide a distância:

| Nível | Estado | Ação do motorista | Por que nesta posição |
| :---: | :--- | :--- | :--- |
| **1** | 🔴 **Zona de Perigo** | **Frear, agora** | Única com ação certa e consequência financeira em curso. |
| **2** | 🩷 **Aproximação em margem** | **Não acelerar** | Há ação, e o aparelho sabe que ela é necessária. |
| **3** | 🟡🔴 **Zona de Semáforo** | Depende do sinal ao chegar | Há risco, mas o aparelho não vê o semáforo. |
| **4** | 🟡 **Aproximação conforme** | **Nenhuma** | Único estado sem ação associada. Cede a vez. |

##### Por que a margem fica acima do semáforo

A justificativa original da precedência por categoria era que *"a Aproximação é o único
estado em que a informação não tem ação associada"*. Com o RF03.9, isso passou a valer
**apenas para o sub-estado conforme**. O sub-estado de margem tem ação clara — não
acelerar — e o aparelho tem certeza de que ela se aplica, porque comparou a velocidade
medida com `V_infra`.

Sem esta distinção, um semáforo em qualquer ponto da janela de 300 m suprimiria o aviso
de rosa piscante, e o motorista a 1 km/h da multa não saberia. Como a coexistência
ocorre em 29% das aproximações de semáforo, o aviso de margem seria perdido justamente
nas vias urbanas onde ele mais importa.

##### Implementação

A varredura do RF02.1 deve rastrear **quatro candidatos**, o mais próximo de cada
categoria, em vez de um único alvo:

```
mais_proximo_perigo     — vel > V_infra
mais_proximo_margem     — limite < vel <= V_infra
mais_proximo_semaforo   — limite == 0
mais_proximo_conforme   — vel <= limite
```

O estado exibido é o de menor nível não vazio. Custo: quatro ponteiros em vez de um, sem
impacto de desempenho.

> ⚠️ **O estado é por ponto, não global.** Dois radares na janela podem ter limites
> diferentes: um de 60 km/h a 250 m e um de 80 km/h a 100 m, com o veículo a 70 km/h,
> produzem simultaneamente um candidato de Perigo (o de 60, mais distante) e um de
> conforme (o de 80, mais próximo). Avaliar o estado **do radar mais próximo** e usá-lo
> como estado do sistema seria errado — daí os quatro ponteiros.
#### [RF03.5] Radar Móvel

2.065 pontos da base (11,3%) são **Radar Móvel** (`TYPE=5`): locais onde a
fiscalização móvel é sabidamente operada, com limites de 60 a 120 km/h — faixa
rodoviária, sem nenhum valor urbano.

##### Tratamento

Zonamento **idêntico a radar de velocidade fixo**: `V_infra`, sub-estados, faixas
sonoras e LED conforme RF03.6 a RF03.9. Radar móvel afere velocidade instantânea como
qualquer radar pontual, então não há diferença de lógica.

##### Consideração para a sessão de telas

Um ponto de radar móvel é **probabilístico**: marca onde a fiscalização *costuma*
ocorrer, não onde ela está agora. Um radar fixo sempre está lá; um móvel pode não
estar. Isso é diferença de confiança, não de zonamento, e sugere distinguir os dois na
tela — o alerta é o mesmo, a certeza não.

> 🎨 Decisão de forma visual deferida para a sessão dedicada a telas e interfaces.

> ⚠️ **Histórico:** este requisito descrevia "trecho controlado" com aferição de
> velocidade média. A hipótese veio de inferência sobre o perfil de velocidade e foi
> **descartada** em 2026-09-16, quando o significado real dos códigos `TYPE`
> identificou `TYPE=5` como Radar Móvel. Ver `formato_dados.md` §0.2 e §7.2.

#### [RF03.6] Limiar de infração e margem de segurança

O sistema não alerta com base no limite da via, mas no **limiar em que a multa passa a
existir** — descontado de uma **margem de segurança deliberada**.

##### Valores legais (confirmados pelo autor na Resolução CONTRAN)

A velocidade considerada para fins de punição é a medida **menos** o desconto:

| Limite da via | Desconto legal |
| :--- | :--- |
| ≤ 100 km/h | **7 km/h** absolutos |
| > 100 km/h | **7%** do limite |

*Exemplo:* um veículo a 87 km/h numa via de 80 km/h tem velocidade considerada de
80 km/h — não é punido.

##### Valores de projeto (com margem)

O firmware usa valores **mais conservadores** que os legais, por decisão de projeto:

| Limite da via | Desconto adotado | `V_infra` |
| :--- | :--- | :--- |
| ≤ 100 km/h | **6 km/h** *(1 km/h de margem)* | `limite + 6` |
| > 100 km/h | **5%** *(2 pontos percentuais de margem)* | `limite × 1,05` |

> ⚠️ **Estes valores são intencionalmente diferentes dos legais. Não "corrigir".**
> A diferença é margem de segurança contra erro de medição do próprio GPS (precisão de
> velocidade de 0,05 m/s pelo datasheet, mas sem garantia sob multipath urbano) e contra
> variação de aferição do radar. Os quatro números — 7, 7%, 6 e 5% — devem ser constantes
> de configuração nomeadas, com o par legal e o par de projeto separados, para que a
> margem seja ajustável sem tocar na regra legal.

Limiares resultantes para os dez limites da base:

| Limite | `V_legal` | **`V_infra` (projeto)** | Margem |
| :--- | ---: | ---: | ---: |
| 30 | 37,0 | **36,0** | 1,0 |
| 40 | 47,0 | **46,0** | 1,0 |
| 50 | 57,0 | **56,0** | 1,0 |
| 60 | 67,0 | **66,0** | 1,0 |
| 70 | 77,0 | **76,0** | 1,0 |
| 80 | 87,0 | **86,0** | 1,0 |
| 90 | 97,0 | **96,0** | 1,0 |
| 100 | 107,0 | **106,0** | 1,0 |
| 110 | 117,7 | **115,5** | 2,2 |
| 120 | 128,4 | **126,0** | 2,4 |

##### Fronteira em 100 km/h

Com os valores **legais** a função é contínua em 100 km/h (7 km/h = 7% de 100). Com os
valores **de projeto** há uma pequena descontinuidade — 6 km/h em 100, contra 5,05 km/h
em 101 — sempre no sentido conservador. Não requer tratamento especial: a regra é
`limite ≤ 100 → +6`, senão `× 1,05`.
#### [RF03.7] Escalonamento sonoro da Zona de Perigo

A Zona de Perigo é a **única zona com sinalização sonora** (ver RF03.8). A frequência
dos bipes deve escalonar com a gravidade do excesso, em três faixas.

##### ⚠️ Ancoragem das faixas: `V_infra`, não o limite

A especificação original pedia faixas de "10% e 20% acima da velocidade da via". Medidas
a partir do **limite**, elas colidem com a tolerância do RF03.6, porque 7 km/h é um
percentual grande em via lenta: a 30 km/h equivale a 23%, já acima da própria faixa de
20%.

Resultado da ancoragem literal no limite:

| Limite | `V_infra` | `limite × 1,10` | Faixa 1 (lenta) |
| :--- | ---: | ---: | :--- |
| 30 | 36,0 | 33,0 | ❌ **vazia** |
| 40 | 46,0 | 44,0 | ❌ **vazia** |
| 50 | 56,0 | 55,0 | ❌ **vazia** |
| 60 | 66,0 | 66,0 | ❌ **vazia** |
| 70 | 76,0 | 77,0 | +1,0 km/h |
| 80 | 86,0 | 88,0 | +2,0 km/h |
| 120 | 126,0 | 132,0 | +6,0 km/h |

Em **~80% dos radares de velocidade da base** (13.429 de 16.864, os de limite
≤ 60 km/h), a faixa de bipes lentos seria vazia — e a 30 km/h até a faixa intermediária
seria vazia, fazendo o aparelho saltar direto para a faixa mais alta no instante em que
cruzasse o limiar. Exatamente o oposto do escalonamento pretendido, e nas vias onde o
aparelho mais será usado.

**Ancoragem adotada: os percentuais contam a partir de `V_infra`.**

| Faixa | Condição | Padrão sonoro |
| :---: | :--- | :--- |
| **1** | `V_infra` a `V_infra × 1,10` | bipe de 100 ms a cada **1000 ms** |
| **2** | `V_infra × 1,10` a `V_infra × 1,20` | bipe de 100 ms a cada **350 ms** |
| **3** | acima de `V_infra × 1,20` | bipe de 50 ms a cada **100 ms** — pulso rápido, **não contínuo** |

Faixas resultantes, em km/h (com os valores de projeto do RF03.6):

| Limite | Faixa 1 — lento | Faixa 2 — rápido | Faixa 3 — pulso rápido |
| :--- | :--- | :--- | :--- |
| 30 | 36,0 – 39,6 | 39,6 – 43,2 | > 43,2 |
| 40 | 46,0 – 50,6 | 50,6 – 55,2 | > 55,2 |
| 50 | 56,0 – 61,6 | 61,6 – 67,2 | > 67,2 |
| 60 | 66,0 – 72,6 | 72,6 – 79,2 | > 79,2 |
| 70 | 76,0 – 83,6 | 83,6 – 91,2 | > 91,2 |
| 80 | 86,0 – 94,6 | 94,6 – 103,2 | > 103,2 |
| 90 | 96,0 – 105,6 | 105,6 – 115,2 | > 115,2 |
| 100 | 106,0 – 116,6 | 116,6 – 127,2 | > 127,2 |
| 110 | 115,5 – 127,1 | 127,1 – 138,6 | > 138,6 |
| 120 | 126,0 – 138,6 | 138,6 – 151,2 | > 151,2 |

Todas as faixas são não vazias e monotônicas em todos os limites da base, e o
escalonamento **1 Hz → ~2,9 Hz → 10 Hz** é perceptivelmente distinguível.

##### ⚠️ Por que a faixa 3 não é contínua

A especificação anterior usava **bipe contínuo** na faixa 3. Alterado em 2026-09-18:
**tom contínuo é o padrão menos detectável contra ruído estável.** O sistema auditivo se
adapta a um tom constante em segundos, e ruído de vento faz exatamente isso com ele — o
alerta mais urgente teria a forma mais fácil de mascarar.

Um pulso rápido a 10 Hz mantém a mensagem de escalonamento pela cadência, resiste ao
mascaramento por ser transiente repetido, e ainda é inconfundível em relação aos ~2,9 Hz
da faixa 2. Ver **R-32** para a análise de audibilidade que motivou a mudança.

O buzzer é **piezo ativo** nos dois modelos aceitos (item 7 do BOM), então as três faixas
são geradas apenas ligando e desligando a alimentação — o tom é interno ao componente.
A 10 Hz o ciclo é de 100 ms, folgado para um timer de hardware.

##### Histerese de faixa

A troca de faixa exige **histerese de 2 km/h na descida**: sem ela, velocidade oscilando
sobre uma fronteira faria o padrão sonoro tremular. A faixa sobe imediatamente ao cruzar
o limiar e só desce 2 km/h abaixo dele.

##### Implementação

O padrão de bipes deve ser gerado por **timer de hardware**, conforme RNF04, nunca por
laço de espera — o laço crítico do GPS não pode ser bloqueado pelo buzzer.
#### [RF03.8] Sinalização sonora exclusiva da Zona de Perigo

**A Zona de Aproximação é silenciosa.** Os "2 bipes curtos na entrada da zona" da
especificação original foram removidos.

Consequência de projeto, e o principal ganho desta revisão: **o buzzer passa a ter um
único significado** — "você está sendo multado se não reduzir" — e sua frequência
codifica a gravidade. Nenhum outro estado do sistema emite som. Aproximação, Semáforo,
OTA, falha de dados e perda de fix são todos silenciosos.

Isso torna o alerta treinável: o motorista aprende **um** som e não precisa interpretar
qual dos estados o produziu. Um buzzer que também toca quando nada precisa ser feito
perde autoridade e passa a ser ruído.
#### [RF03.9] Sub-estados da Zona de Aproximação

A Zona de Aproximação cobre toda a faixa até `V_infra`, o que inclui velocidades **acima
do limite da via** mas ainda sem multa. Sem distinção interna, o motorista receberia
"tudo bem" a 1 km/h do limiar e a transição para o bipe seria um degrau sem aviso.

A zona é dividida em dois sub-estados, **ambos silenciosos**:

| Sub-estado | Condição | LED RGB | Significado |
| :--- | :--- | :--- | :--- |
| **Conforme** | `velocidade ≤ limite` | 🟡 **Amarelo fixo** | Dentro do limite. Nada a fazer. |
| **Margem** | `limite < velocidade ≤ V_infra` | 🩷 **Rosa piscante (1 Hz)** | Acima do limite, ainda sem multa. **Não acelere.** |

Largura da faixa de margem: **6,0 km/h** em todos os limites até 100 km/h, e 5,5 km/h em
110 (ver RF03.6).

##### Progressão de estados do LED

| Estado | Cor | Mistura RGB | Piscada |
| :--- | :--- | :--- | :--- |
| Zona Segura | 🟢 verde | G 100% | fixo |
| Aproximação conforme | 🟡 amarelo | R 100% + G ~70% | fixo |
| **Aproximação em margem** | 🩷 **rosa** | **R 100% + B ~40%** | **1 Hz** |
| Zona de Perigo | 🔴 vermelho | R 100% | 4 Hz |
| *(Zona de Semáforo)* | 🟡🔴 *alternado* | *amarelo ↔ vermelho* | *2 Hz* |
| **Sem proteção ativa** | 🔵 **azul** | **B 100%** | **fixo** |

> **Azul acrescentado em 2026-09-28, e o apagado saiu de cena.** O desenho original
> deixava o LED **apagado** sem fix, durante o OTA e sem base — e apagado significava
> duas coisas ao mesmo tempo: *"não estou protegendo"* e *"o aparelho morreu"*. O
> motorista não distingue as duas sem tirar os olhos da estrada.
>
> A regra passa a ser: **azul = vivo e sem proteção ativa; escuro = sem energia.** Um
> significado cada. Cobre os três casos de uma vez — sem fix, sem base e durante a
> atualização — porque para o motorista eles são o mesmo fato: não há alerta agora.
>
> Azul é **fixo e não pulsante**: sem fix não há ação a tomar, e piscar pediria uma
> atenção que não se deve pedir. O canal pulsante fica reservado ao que é urgente.
>
> Matiz 240°, a **96°** do vizinho mais próximo — o dobro largo dos 40° que esta mesma
> seção exige como mínimo discriminável. O canal azul do LED já tem o menor resistor
> da placa (150 Ω, item 11) justamente por ser o mais fraco, então está calibrado.

##### Por que rosa é mais robusto que laranja aqui

A escolha do rosa não é estética — é de **separação de canal**. Os estados adjacentes na
escala de gravidade são amarelo (R+G) e vermelho (R). Uma cor de aviso intermediária
precisa ser distinguível de ambos mesmo com o LED descalibrado:

| Candidata | Mistura | Falha se o canal secundário estiver fraco | Falha se estiver forte |
| :--- | :--- | :--- | :--- |
| Laranja | R + G ~40% | vira **vermelho** → confunde com Perigo | vira **amarelo** → confunde com conforme |
| **Rosa** | R + B ~40% | vira **vermelho** → confunde com Perigo | vira **magenta** → não colide com nada |

Laranja fica **no mesmo eixo de canal do amarelo**, diferindo apenas pela razão R:G — o
que a torna sensível nas duas direções. Rosa usa o canal **azul**, que nenhum estado de
condução utiliza, então difere do amarelo e do vermelho por *qual canal está aceso*, não
por uma proporção. Sobra apenas um modo de falha em vez de dois.

O canal azul é usado somente nos estados de boot, sem sinal e OTA — todos temporalmente
separados da condução, e o rosa é dominado pelo vermelho, sem risco de confusão com azul.

##### Contrapartida: o rosa não tem convenção de "atenção"

A rampa verde → amarelo → **laranja** → vermelho é convenção aprendida (trânsito, sinais
de risco). Verde → amarelo → **rosa** → vermelho não é. Para um aparelho de usuário único
isso se aprende em um dia de uso, e a robustez de leitura periférica vale mais que a
convenção. Registrado como escolha deliberada, não omissão.

> ⚠️ **Dependência do R-05.** Rosa exige o canal **azul** funcionando e calibrado. Com os
> 330 Ω da revisão 1 o azul fica abaixo de 1 mA e não acende, e o estado apareceria como
> **vermelho fixo piscando** — indistinguível do Perigo, o oposto da intenção. Os 68 Ω
> especificados no BOM cobrem verde e azul; a razão R:B deve ser calibrada por PWM com o
> LED real e as três cores verificadas lado a lado, em luz ambiente e sob sol direto.

##### Histerese

Mesma regra do RF03.7: **2 km/h na descida**. O sub-estado sobe imediatamente ao cruzar
o limite da via e só retorna a "conforme" 2 km/h abaixo dele.

##### O LED RGB sinaliza exclusivamente estado de via

Decisão do autor em 2026-09-15: os estados **de boot, sem sinal de GPS, OTA e falha de
dados** são exibidos **somente na tela**. O LED RGB fica apagado neles.

Isso reduz a paleta de nove estados para **cinco**, todos da mesma categoria semântica —
"qual é a sua situação em relação à via":

| Estado | LED RGB |
| :--- | :--- |
| Zona Segura | 🟢 verde fixo |
| Aproximação conforme | 🟡 amarelo fixo |
| Aproximação em margem | 🩷 rosa piscante (1 Hz) |
| Zona de Perigo | 🔴 vermelho piscante (4 Hz) |
| Zona de Semáforo | 🟡🔴 amarelo/vermelho alternados (2 Hz) |
| *(todos os demais)* | **apagado** |

**O LED apagado passa a ter significado próprio: nenhuma proteção ativa.** É
inequivocamente distinguível do verde fixo, então o motorista que olhe de relance sabe
que o sistema não está avaliando a via — durante o boot, sem fix, em OTA ou com a base
indisponível. Um LED colorido nesses estados diria "estou trabalhando" sem estar.

Consequência prática: o canal **azul** deixa de ser usado isoladamente e passa a servir
apenas à mistura do rosa (R+B).

> ✅ **O LED verde de status de Wi-Fi saiu do projeto** (decisão do autor, 2026-09-15).
> Com boot, sem sinal, OTA e falha de dados exibidos somente na tela, o indicador
> dedicado tornou-se redundante. Consequências:
>
> * O **LED RGB é o único indicador luminoso do projeto** e sinaliza exclusivamente
>   estado de via — cinco estados, uma categoria semântica, nenhuma exceção.
> * O **GPIO 14** fica livre, e a matriz IHM perdeu uma coluna inteira.
> * Todo estado de aparelho (por oposição a estado de via) vive na tela.

##### Histerese

Mesma regra do RF03.7: **2 km/h na descida**. O sub-estado sobe imediatamente ao cruzar
o limite da via e só retorna a "conforme" 2 km/h abaixo dele.

##### Nota de capacidade da paleta

O LED RGB acumula agora **nove estados** distintos (segura, conforme, margem, perigo,
semáforo, boot, sem sinal, OTA, falha de dados), distinguidos por hue e taxa de piscada.
Está próximo do limite do que um único LED difuso comunica de forma confiável na visão
periférica. Novos estados devem preferir a tela, não mais cores.
#### [RF03.10] Controle de velocidade média — ❌ **ANULADO**

> ❌ **Requisito anulado em 2026-09-16.** Não há dados sobre os quais operar.
>
> O requisito pressupunha que `TYPE=5` fosse trecho controlado, com pórticos de início
> e fim aferindo velocidade média. O significado real dos códigos `TYPE`
> (`formato_dados.md` §0.2) identificou `TYPE=5` como **Radar Móvel** — fiscalização
> pontual. **A base não contém nenhum trecho controlado**, e portanto não há par de
> pórticos a cronometrar.
>
> O desenho anterior (abrir o trecho no primeiro pórtico, fechar no seguinte; integrar
> a velocidade em vez das posições) fica registrado no histórico do arquivo, não aqui —
> não há razão para manter especificação de mecanismo que não tem entrada de dados.
>
> O número RF03.10 fica **retirado**, não reservado.

---

### [RF04] Ajuste de Luminosidade Dinâmico

O sistema deve ler o encoder rotativo KY-040 para ajustar o ciclo de trabalho
(*duty cycle*) do PWM do backlight em passos de aproximadamente **5% por clique**,
permitindo escurecer o visor para condução noturna.

* **A escala exposta vai de 0% a 100%, em 21 posições** *(revisado em 2026-09-29)*.
  **O 0% não apaga a tela:** ele é o mínimo que o painel consegue mostrar. Com o visor
  totalmente escuro o usuário perderia a referência visual para recuperá-lo.
* **O piso físico é 10% de luminância** *(era 5%; ver R-05)*. A bancada mostrou que
  "apagado na prática" começa **antes** do duty zero: a 5% a barra da faixa inferior
  não se enxerga no painel real, com a geometria de 28 px da `TelaPrincipal`.
* **Não é a cor que falha, é a área.** As três matizes continuam distinguíveis entre
  si a 5%; o que some é a barra inteira contra o fundo. Por isso subir o piso resolve,
  e mexer na paleta não resolveria.
* **O piso físico não aparece na interface, e isso é requisito.** Ele é propriedade do
  painel — já mudou uma vez e pode mudar com outro componente. Expondo-o, uma
  remedição obrigaria a reescrever o arquivo de configuração, o menu e a tela; contido
  na tabela da curva, não obriga nada.

#### ✅ Debounce: máquina de estados em software, filtro RC como contingência

*Revisado em 2026-09-19, sobre medição na placa. Ver **R-36**.*

A revisão 2 exigia **as duas coisas**: filtro RC de 100 nF em `CLK` e `DT` **mais**
decodificação por máquina de estados. Medido, o filtro de 100 nF **impedia qualquer
decodificação** — ele achatava fases de 45 a 128 ms em pulsos de 1 ms e apagava o estado
`(0,0)`, que é onde a quadratura codifica direção.

**O que o requisito exige agora:**

* **Decodificação por máquina de estados de quadratura, obrigatória.** Ela é o debounce.
  Repique de contato é oscilação entre dois estados adjacentes, e na tabela de transição
  isso soma `+1, −1, +1, −1` — **zero líquido**. Um passo só sai com **quatro transições
  válidas consecutivas na mesma direção**, o que ruído simétrico não produz.
* **Filtro RC: contingência, não requisito.** Se o brilho oscilar sozinho no veículo,
  solde **1 a 10 nF** em `CLK` e `DT`. Nunca 100 nF.

**Por que o filtro saiu do caminho crítico.** O filtro em software é **independente de
frequência**; o RC não é, e essa dependência foi exatamente o que quebrou. Medições que
sustentam a decisão:

| Evidência | Valor |
| :--- | :--- |
| Mudanças espúrias, parado, sem capacitor | **0 em 12 s** |
| Passos falsos na sessão de calibração | nenhum |
| Folga do `(0,0)` sobre a amostragem | **5,8×** |

**O que não foi testado:** o ambiente do veículo, com alternador e ignição. Dois fatos
reduzem o risco — o encoder é **interno ao gabinete**, com fios curtos, ao contrário do
buzzer, que é remoto; e o modo de falha é **benigno e óbvio**, o brilho saltando sozinho,
não uma falha silenciosa. **Manter o lugar dos capacitores na placa** é o que torna a
contingência barata.

#### Leitura por polling, não por interrupção

*Revisado em 2026-09-19. A revisão 2 exigia interrupção de hardware.*

A implementação usa **polling a 1 ms**, e a medição justifica: o estado `(0,0)` dura
**5,75 ms no pior caso**, já incluindo giro rápido — **5,8× de folga**. Nenhum detente se
perde.

A interrupção de borda continua sendo a saída caso o laço principal passe a bloquear por
mais de ~5 ms, e o desenho está pronto para ela: o `DecodificadorQuadratura` é função
pura que não sabe de onde vem a amostra. Ver `docs/adr/0005`.

---

### [RF05] Atualização Sem Fio (Over-The-Air)

Ao detectar o clique no eixo do encoder, o sistema deve ativar a interface de rede do
Pico 2 W, **varrer as redes disponíveis**, conectar à primeira rede configurada que
estiver visível, consultar se há versão nova e, havendo, baixá-la e salvá-la no cartão.

#### 🆕 [RF05.0] Origem e redes vêm da configuração

*Acrescentado em 2026-09-20. Ver **R-37** e `docs/adr/0002`.*

Até esta revisão o requisito mandava "baixar a versão atualizada" e **não dizia de
onde**. Não havia URL em nenhum arquivo do projeto — e num repositório público não
poderia haver: a origem dos dados é de quem monta o aparelho.

**No `coruja.cfg`, na raiz do cartão:**

| Chave | Papel |
| :--- | :--- |
| `wifi_ssid_N` / `wifi_senha_N` | até **5** redes, `N` de 1 a 5 |
| `url_versao` | devolve **uma linha de texto qualquer** — data, número, hash |
| `url_base` | entrega o `radares.bin`; HTTPS obrigatório (RF05.2) |
| `url_envio` | para onde subir log, viagens e infrações. **Vazia desliga o recurso** |
| `token_aparelho` | identifica a unidade no servidor, em **todas** as requisições |
| `servidor_ntp` | de onde vem a hora que julga o prazo do certificado. Vazio: `pool.ntp.br` |
| `log_to_sd` | grava o log em `coruja.log` no cartão. `true`/`false` ou `1`/`0`. **Padrão: desligado** |
| `log_level` | `debug`, `info`, `warning` (ou `warn`), `error`. **Padrão: `info`** |

`url_envio` e `token_aparelho` são **opcionais e desligadas por padrão**: o
aparelho não manda nada para lugar nenhum enquanto alguém não disser para onde,
e exigir as duas impede configurar por descuido um envio para um servidor que
aceita de qualquer um. O `token_aparelho` acompanha também as rotas da base,
porque é por ele que o servidor sabe qual unidade está falando — e um servidor
com lista de aparelhos recusa até o download sem ele.

As duas últimas são **diagnóstico**, não operação, e entram na configuração
pelo mesmo critério das demais: variam por situação e não alteram
comportamento de segurança. `log_to_sd` fica desligado por padrão porque
escrita de cartão consome ciclos finitos — liga-se para caçar um defeito e
desliga-se depois. Valor não reconhecido **mantém o padrão** e é contabilizado
no diagnóstico do leitor; um `log_level` digitado errado não impede o aparelho
de operar.

**Escolha da rede:** varrer, e conectar na primeira da lista **em ordem do arquivo** que
estiver visível. A ordem é a prioridade — não o sinal mais forte. Explícita, previsível,
e o log consegue dizer por que escolheu.

**Decisão de baixar ou não:** o aparelho guarda no cartão a linha devolvida pelo
`url_versao` da última atualização bem-sucedida e **compara como texto**. Diferente,
baixa; igual, não. O firmware não interpreta o conteúdo, o que deixa o formato inteiramente
a cargo de quem serve os dados.

**Sem rede configurada, sem URL, ou cartão ilegível:** o aparelho **opera normalmente** e
apenas não atualiza. O ADR 0002 é explícito, e o RF07 trata o estado de base ausente.

> ⚠️ **A senha fica no cartão, que é removível e legível.** Não é mitigável por software.
> Use uma rede de convidados ou de IoT, nunca a principal.

#### [RF05.1] Pré-condição de segurança

O eixo do encoder é fácil de pressionar sem intenção. Como o modo OTA suspende a leitura
do GPS, entrar nele em movimento deixaria o motorista sem alerta sem saber por quanto
tempo.

* O modo OTA só pode ser iniciado com o veículo **parado**: velocidade < 3 km/h por
  **3 segundos consecutivos**.
* Clique recebido fora dessa condição exibe aviso e é ignorado.
* **Timeout global de 120 s** para o modo OTA, com retorno automático ao velocímetro.

#### [RF05.2] Escrita atômica e validação

Queda de energia (motorista desliga o carro), timeout ou arquivo remoto corrompido não
podem deixar o dispositivo sem base — falha perigosa, porque a tela volta ao velocímetro
normalmente e nada indica a perda.

1. Baixar para `radares.tmp`.
2. **Validar** conforme RF06.3.
3. Renomear a base atual para `radares.bak`.
4. Renomear `radares.tmp` para `radares.bin`.
5. Em caso de falha em qualquer etapa: descartar o `.tmp` e manter a base vigente.
6. Se a base vigente falhar na validação no boot, carregar `radares.bak`.

* **Tentativas:** 3, com intervalo de 5 s.
* Resposta HTTP diferente de 200, `Content-Length` ausente ou arquivo vazio abortam a
  operação sem tocar na base vigente.

#### [RF05.3] Credenciais e integridade

* As credenciais de Wi-Fi **não podem estar embutidas no firmware**. Devem ser lidas em
  tempo de execução de arquivo de configuração no cartão SD (`wifi.cfg`).
* O cartão SD circula fora do ambiente de desenvolvimento — não usar rede corporativa
  nem credenciais reutilizadas para o AP de atualização.
* O download deve usar **HTTPS** ou verificação de assinatura na origem.

---

### [RF06] Base de Dados de Radares

#### [RF06.1] Conversão fora do dispositivo

A base de pontos é um CSV no **padrão iGO8**, com cabeçalho explícito:

```
X,Y,TYPE,SPEED,DirType,Direction
```

> ⚠️ **A ordem `X,Y` tem longitude primeiro.** Trocar as duas não gera erro algum: as
> coordenadas caem no oceano Índico e o sistema simplesmente nunca detecta nada. É a
> armadilha clássica deste formato.

A conversão para o formato binário é feita por **`converte.py`, fora do dispositivo**.
Parsear 612 KB de texto e ordenar 18 mil registros no RP2350 levaria minutos e
desgastaria o cartão, sem ganho algum — o arquivo é idêntico para todos os
dispositivos.

**Entrada em outro formato?** Escreva seu próprio parser. O requisito é apenas produzir
`radares.bin` conforme RF06.2 e RF06.3. Obter a base está fora do escopo deste
documento: o projeto não presume fonte nenhuma.

A base de referência usada no desenvolvimento tem **18.294 pontos** — radares fixos,
radares móveis e semáforos com e sem aferição de velocidade. Ver `formato_dados.md`
§0.2 para o significado de cada `TYPE`.

#### [RF06.2] Formato e carga

* Arquivo `radares.bin`: cabeçalho de 16 B + `n` registros de 12 B, **ordenados por
  latitude crescente**. Tamanho atual: 214,4 KB.
* A base é carregada **integralmente em RAM no boot** e não há acesso ao cartão SD
  durante a condução.
* Registro: `lat` e `lon` em `int32` (graus × 10⁵), `limite` em km/h (`uint8`, 0 = sem
  limite aferível), `rumo` em passos de 2° (`uint8`), e `flags` com `DirType` e tipo.
* Especificação completa em `formato_dados.md` §2 e §3.

#### [RF06.3] Validação obrigatória na carga

Nesta ordem, abortando na primeira falha:

1. Magic `"RDR1"`, versão e escala esperadas.
2. `tam_registro == 12`.
3. `n_pontos` entre 1 e **40.000** (teto de RAM — acima disso a carga integral estoura a
   memória e o arquivo deve ser recusado).
4. `16 + n_pontos × 12 == tamanho do arquivo`.
5. **CRC-32** do bloco de dados.
6. **Invariante de ordenação por latitude.**

> O item 6 não é opcional. A busca binária do RF02.1 retorna resultados silenciosamente
> errados se a base vier desordenada — falha sem sintoma.

---

### [RF07] Degradação Segura

Comportamento obrigatório nas condições de falha:

| Condição | Comportamento |
| :--- | :--- |
| **Sem fix de GPS** (túnel, garagem, cold start) | Visor indica "sem sinal" com contagem do tempo decorrido. Alertas suspensos. Último alvo é descartado após **10 s** sem fix — nunca manter alerta com posição obsoleta. |
| **Cartão SD ausente** (`DET` indica soquete vazio) | Visor indica **"insira o cartão"** — falha acionável pelo motorista. Opera como velocímetro simples. |
| **Cartão presente mas ilegível** | Visor indica **"cartão ilegível"** — falha que o motorista não resolve dirigindo. Opera como velocímetro simples. Não travar nem reiniciar em laço. |
| **`radares.bin` inválido** | Tentar `radares.bak`. Se ambos falharem, tratar como cartão ilegível. |
| **Travamento do firmware** | **Watchdog de hardware** com janela de 2 s. O motorista não pode reiniciar o dispositivo dirigindo. |
| **Cold start do GPS** | TTFF de **26 s** em GPS+GLONASS (datasheet, Tabela 1); hot start 1 s, aided 2 s. A tela de boot deve deixar explícito que ainda não há proteção ativa. |
| **Taxa abaixo de 3 Hz** sustentada (RF01.5) | Reenviar a configuração UBX uma vez. Se persistir, exibir aviso de degradação e **manter os alertas ativos** — 1 Hz ainda protege melhor que nada, mas o motorista precisa saber que a precisão caiu. |

---

## ⚙️ 3. Requisitos Não-Funcionais (RNF)

* **[RNF01] Robustez Elétrica:** a entrada de 5 V, proveniente do **conversor CC
  12 V → 5 V externo ao gabinete**, deve ser aplicada em **`VSYS` (pino 39)** através de
  **diodo Schottky em série**, e **não** em
  `VBUS` (pino 40). `VBUS` é ligado diretamente ao conector USB do Pico, e injetar 5 V
  externo nesse nó cria conflito de fontes quando o USB é usado para gravação ou debug.
  O circuito deve possuir filtragem capacitiva dupla (eletrolítico de 470 µF a 1000 µF
  **de 105 °C** + cerâmico de 100 nF) acoplada nesse nó, o mais próximo fisicamente
  possível dos pinos 39 e 38, tolerando transientes de ignição e ruído do alternador.

* **[RNF02] Isolamento de Portas:** o pino GPIO de sinal do buzzer não deve fornecer
  corrente direta ao componente; o acionamento deve ser feito através de um transistor
  NPN **atuando** como chave, com margem de corrente de pelo menos 5× o consumo do
  buzzer.

* **[RNF03] Armazenamento:** o sistema deve suportar cartões formatados estritamente em
  **FAT32**, e a comunicação SPI com o leitor deve operar em lógica nativa de **3,3 V**.
  Cartão com formatação diferente, ausente ou ilegível cai no RF07.

  **Sem detecção de presença.** O pino `DET` foi removido em 2026-09-22 (ADR 0010):
  cartão ausente e cartão ilegível são tratados como **o mesmo caso**, porque a reação
  do aparelho é a mesma. A presença é inferida da montagem — se monta, existe.

  | Estado | Nível em GPIO 14 |
  | :--- | :--- |
  | Cartão inserido | **ALTO** (pull-up de 4,7 kΩ da própria placa) |
  | Sem cartão | **BAIXO** (ligado ao GND internamente) |

  * **Configurar o GPIO 14 como entrada sem pull.** A placa já fornece o pull-up de
    4,7 kΩ; o interno do Pico seria redundante e mais fraco.
  * O `DET` é **indício, não autoridade**. A tentativa de leitura continua sendo o
    veredito: se `DET` diz "presente" e a leitura falha, o estado é "ilegível". O `DET`
    só melhora a mensagem, nunca substitui a verificação.

* **[RNF04] Concorrência de Software:** a leitura do encoder (giro e clique) e o piscar
  dos LEDs devem ser tratados via **interrupções (IRQs)** e **timers de hardware**,
  garantindo que processos de interface não atrasem o laço crítico do GPS.

  Divisão obrigatória entre os núcleos do RP2350:

  | Núcleo | Responsabilidade |
  | :--- | :--- |
  | **Core 0** | UART do GPS, parsing NMEA, busca geográfica, máquina de estados de zona |
  | **Core 1** | Renderização e transferência SPI do display, LEDs, encoder |

  O barramento SPI0 é compartilhado entre display e cartão SD e exige **mutex**: nenhum
  acesso pode se intercalar com o outro. O cartão exige clock ≤ 400 kHz **na
  inicialização**, enquanto o display opera em dezenas de MHz — a velocidade deve ser
  reconfigurada por dispositivo antes de cada transação.

* **[RNF05] Modularidade Mecânica:** o buzzer deve ser montado **externamente ao
  gabinete**, conectando-se a ele por **JST-XH de 2 vias** — polarizado, de liberação
  rápida e sem contato deslizante. Conectores de áudio do tipo P2 estão **proibidos**
  neste circuito: a inserção faz o sleeve varrer o tip, curto-circuitando 5 V ao coletor
  do transistor sem o buzzer limitando a corrente. *(Decisão confirmada em 2026-09-15.)*

  ⚠️ **A posição não é detalhe de acabamento — é requisito acústico (R-32).** O caso de
  projeto é **janela aberta a 80 km/h**, com ruído interno da ordem de 87 dB(A), e nessa
  condição reposicionar e reorientar o buzzer valem **mais decibel do que trocar de
  modelo**. Portanto: **apontado para o motorista**, não para dentro do painel, e o mais
  próximo possível dele — coluna de direção ou base do para-brisa, não enterrado no
  console. "Escondido sob o painel", como dizia a revisão 2, era o oposto do que a
  acústica pede.

  O JST-XH torna o buzzer **trocável com o projeto fechado**, então o modelo é decisão
  reversível; a posição, uma vez fixada, não é.

* **[RNF06] Plataforma de Software:** o firmware deve ser implementado em **C++17 com o
  Raspberry Pi Pico SDK**. A escolha é condicionada por dois fatores:
  1. **Paralelismo real entre núcleos.** O RNF04 exige divisão de trabalho entre core 0
     e core 1; `multicore_launch_core1()` do SDK entrega isso. O `_thread` do
     MicroPython no port RP2 tem GIL e não executaria bytecode em paralelo.
  2. **Orçamento de memória.** A base de 214 KB mais o framebuffer de 150 KB não
     conviveriam com o interpretador e a heap do MicroPython em 520 KB de SRAM.

  Comparação completa em `formato_dados.md` §9.

* **[RNF07] Orçamento de Memória:** consumo alvo em 520 KB de SRAM:

  | Consumidor | Limite |
  | :--- | ---: |
  | Base de radares (estática em `.bss`) | 214 KB — teto de 40.000 registros |
  | Framebuffer 320×240 RGB565 | 150,0 KB |
  | Pilha lwIP + driver CYW43 | ~48 KB *(medir)* |
  | Stacks dos dois núcleos | ~8 KB |
  | Buffers de SD e UART | ~4 KB |
  | `.data` / `.bss` restante | ~20 KB |
  | **Reserva livre mínima** | **≥ 60 KB** |

  Alavanca de alívio prevista, se o limite for excedido: **renderização em bandas** de
  40 linhas (25,0 KB em vez de 150,0 KB), liberando **125 KB**. Com o display de 2,4" a
  reserva livre sem bandas cai a ~76 KB, abaixo do mínimo de 60 KB apenas por margem de
  estimativa — **as bandas deixaram de ser alavanca opcional e passaram a ser o desenho
  esperado**. O consumo real deve ser medido com `arm-none-eabi-size` e marca d'água de
  stack, não estimado.

* **[RNF08] Precisão Numérica:** a FPU do RP2350 é de **precisão simples**. Os cálculos
  geográficos devem seguir o RF02.2 — operar sobre diferenças de coordenadas, nunca
  sobre valores absolutos em `float`.

* **[RNF09] Faixa Térmica:** a superfície do painel de um veículo exposto ao sol
  atinge **92 °C** — medição com termômetro infravermelho em São Paulo, após 5 h, pelo
  canal Manual do Mundo. A revisão anterior dizia "ultrapassa 60 °C", o que subestimava
  em mais de 30 °C. Todos os componentes devem ser especificados para operação até
  **85 °C**, e o capacitor eletrolítico para **105 °C**.

  ⚠️ **O módulo GPS é o componente térmico limitante do projeto.** O datasheet
  UBX-15031086 (Tabelas 9 e 10) especifica para o NEO-M8N temperatura de operação de
  −40 a **+85 °C** e de **armazenamento igualmente limitada a +85 °C** — diferente do
  NEO-M8M, que vai a 105 °C de armazenamento. **A 92 °C o módulo está 7 °C FORA da
  faixa de armazenamento**, e não há margem nem com o aparelho desligado. Registrado
  como **R-65**.

  📐 **A assimetria que decide o projeto da montagem:** o aparelho **opera** com o
  veículo ligado — ar-condicionado funcionando, cabine refrigerada — e **armazena**
  desligado, parado ao sol. O limite que aperta é portanto o de **armazenamento**, não
  o de operação. Isso inverte a prioridade: proteger o módulo do sol **parado** importa
  mais que dissipar calor em funcionamento.

  ⚠️ **A remoção do aparelho ao estacionar NÃO é mitigação admissível.** Contraria a
  premissa do produto — estar sempre pronto para uso. Exigir conexão ao entrar no
  veículo elimina a razão de o aparelho existir, porque o celular com Waze já cumpre o
  papel sem esse atrito. Decisão do autor em 2026-10-01.

  📋 **O requisito é aceito em aberto, não pendente — ver
  [ADR 0011](docs/adr/0011-medir-antes-de-mitigar.md).** A montagem a executar usa a caixa e o
  módulo já comprados, e as mitigações são **contingentes a medição**: o gatilho é
  observar problema, não concluir que seriam boa ideia. O aparelho opera fora da
  especificação do módulo durante o teste, e esse é o custo aceito.

  Mitigações, em ordem de grandeza — e a primeira é de outra ordem que as demais:

  1. **Antena de cabo longo com bulkhead SMA** (`montagem.md` §4.8). Com os **8 cm** do
     rabicho U.FL em mãos, a exigência de vista de céu prega a caixa no ponto mais
     ensolarado do veículo. Soltar essa amarra vale dezenas de graus.
  2. Montagem: prateleira no chassi e não na tampa, folga de ar contra o painel, face
     solar clara, ventilação por convecção (`montagem.md` §4). Vale graus.

  As campanhas que fecham o requisito são **M-08** (temperatura interna real) e **M-06**
  (C/N0 por posição).

* **[RNF10] Verificação:** antes de considerar uma funcionalidade concluída:
  * **Testes unitários** do parser NMEA (incluindo checksum inválido, campos vazios,
    sentença sem fix, talker `GN` e `GP`).
  * **Testes unitários** do cálculo de distância e do filtro de rumo com vetores
    conhecidos — **obrigatoriamente incluindo o caso de wraparound 355°/5°** e os três
    valores de `DirType`.
  * **Replay de logs NMEA** gravados em estrada, validando as transições de zona sem
    necessidade de dirigir.
  * **Teste de interrupção de energia** durante o OTA, validando o RF05.2.
  * O `radares.bin` gerado serve de *fixture* para os testes de busca.

---

## 👤 4. Matriz de Interação Homem-Máquina (IHM)

Esta tabela define como as ações do usuário (motorista) ou do ambiente geram respostas
nos atuadores visuais e sonoros do dispositivo.

| Evento / Ação do Usuário | Estado do Sistema | Visor IPS 2,4" 320×240 (ver §4.1) | LED RGB Periférico | Buzzer SFM-27 (Painel) |
| :--- | :--- | :--- | :--- | :--- |
| **Girar chave do carro (Boot)** | Inicialização | Exibe logo e contagem de pontos carregados. Indica que a proteção ainda não está ativa. | **Azul fixo** | Silencioso |
| **Aguardando primeiro fix** | Sem Sinal | "Buscando satélites" com tempo decorrido. | **Azul fixo** | Silencioso |
| **Dirigindo sem pontos próximos** | Zona Segura | Velocidade em branco, **sem denominador** — fora do raio de um ponto o aparelho não sabe o limite da via. Sem ícone e sem barra: a faixa inferior fica vazia. | **Verde Fixo** | Silencioso |
| **Entrou no raio de 300m, dentro do limite** (`vel ≤ limite`) | Aproximação — conforme | `velocidade/limite` em branco; ícone do tipo de ponto e barra de proximidade em **âmbar**. | **Amarelo Fixo** | **Silencioso** |
| **Acima do limite, ainda sem multa** (`limite < vel ≤ V_infra`) | Aproximação — **margem** | Idem, com a barra de proximidade em **rosa**. | 🩷 **Rosa Piscante (1 Hz)** | **Silencioso** |
| **Acima do limiar de infração** — faixa 1 (`V_infra` a +10%) | Zona de Perigo | Barra de proximidade em **vermelho**. Layout inalterado, **nada pisca na tela** (§4.1). | **Vermelho Piscante (4 Hz)** | Bipe de 100 ms a cada **1000 ms** |
| **Acima do limiar de infração** — faixa 2 (+10% a +20%) | Zona de Perigo | Idem. | **Vermelho Piscante (4 Hz)** | Bipe de 100 ms a cada **350 ms** |
| **Acima do limiar de infração** — faixa 3 (acima de +20%) | Zona de Perigo | Idem. | **Vermelho Piscante (4 Hz)** | Bipe de 50 ms a cada **100 ms** — pulso rápido, não contínuo (R-32) |
| **Entrou no raio de 300m de semáforo** | Zona de Semáforo | Ícone 🚦 e barra em **âmbar**. **Sem denominador** — não há limite a comparar. Para `TYPE=2` (semáforo *com* radar) o ícone é 🚦+🏎 e **há** denominador: resolve o **R-26**. | **Amarelo/Vermelho alternados (2 Hz)** | **Silencioso — sem exceção.** |
| **Entrou no raio de 300m de radar móvel** | Idêntico a radar fixo | Ícone 🏎 **vazado** em vez de preenchido: confiança expressa como preenchimento, não como símbolo novo — a fiscalização pode não estar ativa. Zonamento e LED idênticos a radar fixo. | conforme o estado da via | conforme o estado da via |
| **Perda de sinal em movimento** | Sem Sinal | Numerador vira **`- -`** — o GPS é a única fonte de velocidade. Faixa inferior: `SEM SINAL — alertas suspensos` com tempo decorrido, em **cinza**. Layout preservado. | **Azul fixo** | Silencioso |
| **Girar o botão do Encoder** | Ajuste de Brilho | Barra de brilho por ~1,5 s **na faixa superior**, deslocando o relógio. Curva perceptual, não linear (§4.1). | Mantém estado atual | Silencioso |
| **Clique do Encoder com carro em movimento** | Recusa | `PARE O VEÍCULO PARA ATUALIZAR` por 2 s **na faixa inferior**, não em tela cheia — os alertas continuam visíveis. | Mantém estado atual | Silencioso |
| **Clique do Encoder com carro parado** | Sincronismo OTA | Altera tela para "Atualizando base de dados...". | **Azul fixo** | Silencioso |
| **Wi-Fi autenticado e baixando arquivo** | Transferência | Barra de progresso ou animação de download. | **Azul fixo** | Silencioso |
| **Fim do download / Falha no Timeout** | Conclusão | Exibe "Sucesso!" ou "Falha na conexão — base anterior mantida". Retorna ao velocímetro após 2s. | Restaura estado da via | Silencioso |
| **Taxa de GPS abaixo de 3 Hz** | Degradação | Indicador discreto de taxa reduzida, sem ocultar o velocímetro. Alertas seguem ativos. | Mantém estado da via | Silencioso |
| **Cartão SD ausente ou base inválida** | Falha de Dados | `⚠ BASE INDISPONÍVEL — sem alertas` **permanente** na faixa inferior, em **cinza**, não 3 s. Sem base não há ponto, logo a barra de proximidade nunca teria o que mostrar: a faixa fica livre. Corrige o **R-30**. | **Azul fixo** | Silencioso |

---

### 4.1 Desenho de tela — geometria, canais e paleta

> Definido em 2026-09-17, na sessão dedicada a telas. Fecha o **R-26** e a distinção
> visual do radar móvel (RF03.5), ambos deferidos, e origina o **R-30**.

#### Módulo e geometria

| Grandeza | Valor |
| :--- | :--- |
| Painel | 2,4", **320×240**, paisagem, montado à esquerda do painel do veículo |
| Área ativa | 48,8 × 36,6 mm → **6,56 px/mm** |
| Dígito no pior caso (`120/110`) | 79 px = **12,0 mm** = 59 arcmin a 70 cm |

Referência de legibilidade: ~25 arcmin é o mínimo de placa de trânsito, 45+ é
confortável. O painel de 2,4" tem **pixels maiores** que um 1,3" de 240×240 (6,56 contra
10,28 px/mm), e é isso que torna o formato `velocidade/limite` legível de viés.

#### Divisão vertical (240 px)

| Região | Altura | Conteúdo |
| :--- | ---: | :--- |
| Fio de moldura | 2 px | decorativo, cor fixa |
| **Faixa superior** | 26 px | status do aparelho (ver inquilinato) |
| **Área do número** | 166 px | `velocidade/limite` |
| **Faixa inferior** | 44 px | ícone + barra, ou a razão de não haver alerta |
| Fio de moldura | 2 px | |

#### Quatro canais ortogonais

A informação se divide em quatro canais que **não se duplicam**. Cada um responde uma
pergunta diferente, e é isso que permite quatro estados de via, quatro tipos de ponto e
três estados degradados sem ambiguidade:

| Canal | Responde | Valores |
| :--- | :--- | :--- |
| **Número** | a que velocidade eu vou | `75` · `75/110` · `- -` |
| **Denominador** | há limite a comparar | presente / ausente |
| **Ícone** | que tipo de ponto vem | 🏎 · 🚦 · 🚦+🏎 |
| **Barra** | quão perto, e quão grave | preenchimento + cor |

A **moldura não é canal**: cor fixa, decorativa. O LED RGB periférico continua sendo o
canal de estado de via, e **nada na tela pisca** — a tela é o canal estável, o LED é o
canal pulsante. Trocar o layout no instante de maior estresse obrigaria o motorista a
reaprender a tela com 9 segundos de aviso a 120 km/h.

#### Número e denominador

Fora do raio de um ponto, **o aparelho não conhece o limite da via**: a base é um
conjunto de pontos, não uma malha viária, e `limite` é o limite *daquele radar*. O
denominador portanto só existe perto de um ponto que afira velocidade:

| Situação | Número | Ícone | Barra |
| :--- | :--- | :--- | :--- |
| Zona Segura | `75` | — | — |
| Radar fixo (`TYPE=1`) | `75/110` | 🏎 cheio | ✓ |
| Radar móvel (`TYPE=5`) | `75/110` | 🏎 | ✓ |
| Semáforo c/ radar (`TYPE=2`) | `75/60` | 🚦 **+** 🏎 | ✓ |
| Semáforo c/ câmera (`TYPE=3`) | `75` | 🚦 | ✓ |
| Sem sinal de GPS | `- -` | — | — |

A presença do ícone e da barra **é** o aviso de ponto à frente: o motorista percebe que
algo apareceu na faixa inferior antes de ler qualquer dígito. Em Zona Segura a faixa
fica vazia de propósito — o vazio é a mensagem, e é ele que dá contraste ao alerta.

#### Inquilinato das faixas — um ocupante por vez

**Faixa inferior (44 px)** — "há alerta, ou por que não há":

| Prioridade | Ocupante | Duração |
| :---: | :--- | :--- |
| 1 | `PARE O VEÍCULO PARA ATUALIZAR` | transitório, 2 s |
| 2 | `⚠ BASE INDISPONÍVEL — sem alertas` | **persistente** |
| 3 | `⚠ SEM SINAL — alertas suspensos 0:14` | **persistente** |
| 4 | Ícone(s) + barra de proximidade | enquanto houver ponto em alcance |
| 5 | Vazia | Zona Segura |

**Faixa superior (26 px)** — status do aparelho:

| Prioridade | Ocupante | Duração |
| :---: | :--- | :--- |
| 1 | Taxa de GPS reduzida (RF07) | persistente |
| 2 | Barra de ajuste de brilho | transitório, ~1,5 s |
| 3 | Relógio `dd/mm/aa hh:mm` | padrão |

O relógio vem do GPS. **Não há RTC com bateria no BOM**, então ele mostra
`--/--/-- --:--` até o primeiro fix — até **26 s** em cold start (RNF datasheet). Fuso
fixo em **UTC−3**, sem lógica de horário de verão: o Brasil o extinguiu em 2019.

O tempo decorrido em "sem sinal" não é enfeite: `0:14` é um viaduto e `3:20` é problema
real, e a ação do motorista difere nos dois casos.

#### Paleta

Três regras, todas consequência do **brilho ser controlado por PWM do backlight**, que
multiplica a luminância de tudo na tela pelo mesmo fator:

1. **Distinguir por matiz, nunca por luminância.** Diferenças de valor são justamente o
   que o PWM destrói: a 5% de brilho, um vermelho escuro desaparece e um vermelho claro
   sobrevive. Todas as cores de estado ficam em valor alto e diferem em *hue*.
2. **Nunca por saturação apenas.** Um "rosa claro" `#FF8080` tem **matiz 0 — o mesmo do
   vermelho**, diferindo só em saturação, que é a primeira coisa a colapsar no escuro.
   O rosa precisa de azul de verdade.
3. **O número fica sempre branco.** Ele é o que precisa ser lido; branco dá 21:1 de
   contraste sobre preto, contra 5,3:1 do vermelho — quatro vezes mais. A cor do risco
   vai para a barra, que não é texto e não perde nada ao ser colorida.

| Uso | Hex | RGB565 | Matiz |
| :--- | :--- | :--- | ---: |
| Fundo | `#000000` | `0x0000` | — |
| **Número, denominador, texto** | `#FFFFFF` | `0xFFFF` | — |
| Estado degradado (sem base, sem sinal, `- -`) | `#C0C0C0` | `0xC618` | neutro |
| Fio de moldura e trilho vazio da barra | `#404040` | `0x4208` | neutro |
| **Barra — aproximação conforme e semáforo** | `#FFB000` | `0xFD80` | 42° |
| **Barra — margem** | `#FF40C0` | `0xFA18` | 318° |
| **Barra — perigo** | `#FF0000` | `0xF800` | 0° |

Separação de matiz entre as cores de barra: âmbar↔vermelho 42°, vermelho↔rosa 40°,
âmbar↔rosa 84°. O mínimo de 40° é discriminável em área grande.

**Âmbar `#FFB000` em vez de amarelo puro `#FFFF00`:** o amarelo puro dessatura na direção
do branco a baixo brilho e passa a competir com o número. O âmbar mantém identidade.

**Verde não aparece na tela.** Zona Segura não tem barra, e barra só existe perto de
ponto — então as cores necessárias são três, não quatro. O verde vive no LED.

✅ **Medido na bancada em 2026-09-29 (R-05): o piso sobe para 10%.**

A contingência prevista aqui se concretizou, mas por uma razão diferente da esperada.
O texto previa que as três matizes se confundissem entre si; **não é o que acontece**.
Elas continuam distinguíveis a 5% — o que desaparece é a barra inteira contra o fundo,
porque a área acesa fica pequena demais para o olho registrar de relance.

A consequência prática é a mesma (piso de 10%), mas a causa importa: fosse confusão de
matiz, a correção seria na paleta; sendo área, a correção é no brilho, e a paleta
permanece válida como está.

✅ **Reverificado no painel depois da correção** (2026-09-29): no 0% da escala nova —
que é o piso físico de 10% — o texto continua legível no escuro e a barra é fácil de
ver. O layout do §4.1 foi dado por fechado na mesma sessão.

#### Controle de brilho pelo encoder

* **Faixa de 0% a 100%**, 21 posições, com o 0% mapeado no piso físico do painel.
* **Curva perceptual, não linear.** A percepção humana de brilho é aproximadamente
  logarítmica: passos lineares de *duty cycle* fazem toda a mudança acontecer no fundo
  da escala. Use `duty = (passo / N) ^ 2,2` ou uma tabela logarítmica.
* **PWM em ≥ 20 kHz.** Abaixo de ~1 kHz o painel cintila de forma perceptível na visão
  periférica e pode produzir efeito estroboscópico com feições da estrada; entre 1 e
  20 kHz alguns módulos assobiam.
* Fundo preto permanente não é estética: com o brilho ajustado a 5% à noite, quanto menor
  a área acesa, menor o ofuscamento. Não há sensor de luz ambiente — o ajuste é manual, e
  o desenho precisa cooperar com isso.

#### Assets

Tudo em **flash** (4 MB), zero impacto no orçamento de RAM da §1 do `formato_dados.md`:

| Asset | Custo |
| :--- | ---: |
| Fonte numérica 56×94, **1 bpp** (11 glifos: `0-9` e `/`) | 7,1 KiB |
| Fonte de texto 12×20, 1 bpp, ASCII | 2,9 KiB |
| 2 sprites 40×40 RGB565 (🏎, 🚦) | 6,3 KiB |
| **Total** | **~16 KiB** |

**1 bpp com a cor aplicada no blit** é o que faz uma única fonte servir todos os estados;
em RGB565 gastaria 16× mais e exigiria uma cópia por cor. Os sprites são **dois** porque
o `TYPE=2` **compõe** 🚦 com 🏎 em vez de ser um desenho próprio.

> **Revisão de 2026-09-28 — o radar móvel deixou de ter ícone próprio.** O desenho
> original usava um carro **vazado** para dizer "este ponto pode não estar aqui hoje".
> A distinção foi removida: o RF03.5 já manda zonear o móvel exatamente como o fixo, a
> ação do motorista é a mesma nos dois casos, e **distinção que não muda decisão é
> ruído** no instante em que menos se pode gastar atenção. O `TYPE` continua distinto
> no dado e na base; o que se decidiu foi não gastar um canal visual com ele. Custo
> economizado: um sprite, 3,1 KiB de flash.

Os "emoji" são **sprites próprios, não caracteres**: não há sistema operacional nem pilha
de fontes no Pico, e o emoji colorido do desktop vem de uma fonte de vários megabytes.
O caminho reproduzível é um script que renderize o desenho de origem uma vez e converta
para array C, versionado junto ao código.

#### Custo de redesenho por região (SPI a 32 MHz)

| Região | Bytes | Tempo |
| :--- | ---: | ---: |
| Tela inteira | 150,0 KiB | 38,4 ms |
| Faixa inferior 320×44 | 27,5 KiB | 7,0 ms |
| Barra ~240×28 | 13,1 KiB | 3,4 ms |
| Fio de moldura 2 px | 4,3 KiB | 1,1 ms |

O ciclo nominal é de 4 Hz, ou 250 ms. Como **o layout não muda entre estados** e nada
pisca, o redesenho típico é parcial: número, barra e faixas, não a tela toda.

---

## 🔄 5. Fluxo Lógico de Navegação de Telas

```text
       [ TELA DE BOOT ]
       (Lê o SD, valida radares.bin, carrega 214 KB na RAM)
              │
              ├── Falha de SD / base inválida ──> [ TELA DE FALHA DE DADOS ]
              │                                    (modo velocímetro simples)
              ▼
       [ TELA SEM SINAL ] (aguardando primeiro fix)
              │
              ▼
    ┌───> [ TELA VELOCÍMETRO (Pista Livre) ] <────────────────────────┐
    │     (Vel. atual, fundo preto, LED RGB verde fixo)               │
    │         │                                                       │
    │         │ Ponto válido ≤ 300m e à frente                        │ Afastou-se
    │         │                                                       │ (histerese 340m)
    │         ├── limite == 0 ──> [ TELA DE SEMÁFORO ]────────────────┤
    │         │                   (Amarelo/Vermelho 2Hz, SILENCIOSO) │
    │         │                                                       │
    │         └── limite > 0 ───> [ TELA DE APROXIMAÇÃO ]             │
    │                              (Distância + placa de limite)      │
    │                                  │                              │
    │                                  ├─ Vel. ≤ limite ──> LED amarelo fixo   │
    │                                  │                    (conforme)         │
    │                                  │                                       │
    │                                  ├─ Vel. ≤ V_infra ─> LED ROSA 1Hz       │
    │                                  │                    (margem, silente)  │
    │                                  │                                       │
    │                                  └─ Vel. > V_infra ─> [ TELA DE PERIGO ]─┤
    │                                                       (Fundo vermelho,   │
    │                                                        LED 4Hz, buzzer   │
    │                                                        em 3 faixas)      │
    │                                                                          │
    │   PRECEDÊNCIA (RF03.4):  Perigo > Margem > Semáforo > Conforme           │
    │                                                                 │
    │  Perda de fix > 10s ──> [ TELA SEM SINAL ] ─────────────────────┤
    │                                                                 │
    └─ Fim do Download <─── [ TELA ATUALIZAÇÃO WI-FI ] <─── Clique SW ─┘
                                                           (só se parado)
```

---

## 🔗 6. Rastreabilidade da Revisão 2

| Item de `revisao_tecnica.md` | Onde foi aplicado |
| :--- | :--- |
| R-01 — `VBUS` é o pino 40, usar `VSYS` | RNF01 |
| R-03 — Cálculo de distância sobre a base inteira | RF02.1 |
| R-04 — Wraparound e `DirType` | RF02.3 |
| R-06 — Conector P2 do buzzer | RNF05 — ✅ **confirmado: JST-XH** |
| R-07 — Configuração UBX | RF01.2 |
| R-08 — `$GNRMC` / `$GPRMC` + checksum | RF01.1 |
| R-09 — Condição de aproximação e histerese | RF03.1, RF03.2 |
| R-10 — OTA atômico e validação | RF05.2, RF06.3 |
| R-11 — Credenciais fora do firmware | RF05.3 |
| R-12 — OTA com veículo parado | RF05.1 |
| R-15 — Mutex SPI0 e divisão entre núcleos | RNF04 |
| R-16 / R-17 — Buzzer: diodo e transistor | RNF02 e `bom_schematic.md` |
| R-19 — `limite == 0` e Zona de Semáforo | RF03, RF03.3 |
| R-20 — Significado de `TYPE=5` | RF03.5 — reescrito de trecho controlado para **Radar Móvel** |
| L-01 — Perda de fix | RF07 |
| L-02 — Orçamento de memória | RNF07 |
| L-03 — Falha de cartão SD | RF07, RNF03 — refinado com `DET` em 2026-09-17 |
| L-04 — Watchdog | RF07 |
| L-05 — Faixa térmica | RNF09 |
| L-06 — Conversão de velocidade | RF01.3 |
| L-07 — Estratégia de testes | RNF10 |
| L-08 — Linguagem e runtime | RNF06 |
| L-09 — Precisão numérica | RF02.2, RNF08 |
| R-21 — 5 Hz é o teto do módulo em GPS+GLONASS | RF01, RF01.2, RF01.4 — ✅ **4 Hz nominal / 3 Hz de piso, confirmado**; monitoramento no RF01.5 |
| R-22 — GPIO de 3,3 V excede `VIN` do GPS | `bom_schematic.md` §3 — resistor de 1 kΩ em série |
| R-23 — Faixas de 10%/20% vazias na maioria dos radares | RF03.7 — faixas reancoradas em `V_infra` |
| R-24 — Margem suprimida pelo semáforo na precedência por categoria | RF03.4 — margem elevada acima do semáforo |
| R-20 — `TYPE=5` afere velocidade média | **Hipótese descartada.** RF03.5 reescrito para Radar Móvel; RF03.10 anulado |
| R-26 — `TYPE=2` é semáforo e não recebe aviso | RF03.3 — lacuna registrada; forma deferida para a sessão de telas |
| E-02 / E-03 / E-04 — Correções de texto | RNF05, RNF02, matriz IHM |

**Confirmado pelo autor (2026-09-15):** RNF05 (conector JST-XH), RF01.4 (GPS+GLONASS a
4 Hz nominal, piso de 3 Hz), RF03.4 (precedência por categoria), RF03.6 (margem de
segurança de 6 km/h e 5%), RF03.7 (buzzer em 3 faixas), RF03.8 (Aproximação silenciosa)
e RF03.9 (rosa piscante na margem).

**Removido do projeto (2026-09-15):** LED verde de status de Wi-Fi. O LED RGB é o único
indicador luminoso.

Nenhuma suposição pendente neste documento.

❌ **Anulado:** RF03.10 (velocidade média) — sem dados sobre os quais operar.
🎨 **Sessão dedicada:** desenho de telas e interfaces visuais — inclui **R-26**
(indicação combinada de semáforo + radar) e a distinção visual de Radar Móvel (RF03.5).

Itens em aberto que não afetam este documento: R-05, R-13, R-14 (ver `bom_schematic.md`).

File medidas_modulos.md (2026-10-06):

# 📏 Medidas dos módulos — para os footprints próprios

**Instrumento:** paquímetro.
**Objetivo:** substituir a barra de pinos genérica por footprint com o
**contorno** de cada módulo, para que o posicionamento na placa acuse
sobreposição. Ver `pcb.md` §7.

> 📦 **Os números não moram mais aqui.** Desde 2026-10-05 as medidas vivem num
> arquivo legível por programa, junto da cadeia de geração, que não é
> distribuída com este repositório. O que ficou aqui é o que tem valor
> independente da ferramenta: **o protocolo de medição e as lições**.
>
> As tabelas da seção 4 continuam como formulário — servem para medir um módulo
> novo antes de os números irem para lá.

> 📌 Enquanto uma linha estiver vazia, ela é **desconhecida** — não presumida.
> Nada aqui deve ser preenchido por datasheet ou por foto. O que não foi medido
> fica em branco, e o footprint correspondente não é gerado.

---

## 1. Como medir

### Origem: o centro do pino 1

Todas as distâncias saem do **centro do pino 1**. É o único ponto que a placa e
o módulo têm em comum. Medir cada borda de forma independente faz os erros
somarem, e o furo sai fora.

### Passo: medir o vão inteiro, nunca entre vizinhos

Entre dois pinos adjacentes, ±0,1 mm de leitura vira ±4 % de erro. Meça do
**centro do pino 1 ao centro do último** e divida pelo número de intervalos:

```
8 pinos  →  7 intervalos  →  17,78 mm / 7 = 2,54 mm   ✅ confirmado
```

Isso divide o erro de leitura pelo número de intervalos.
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

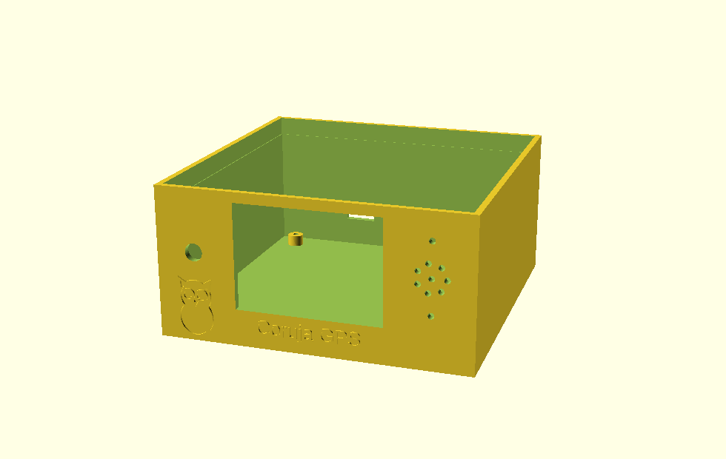
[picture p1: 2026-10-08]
caixa/previa_frente.png

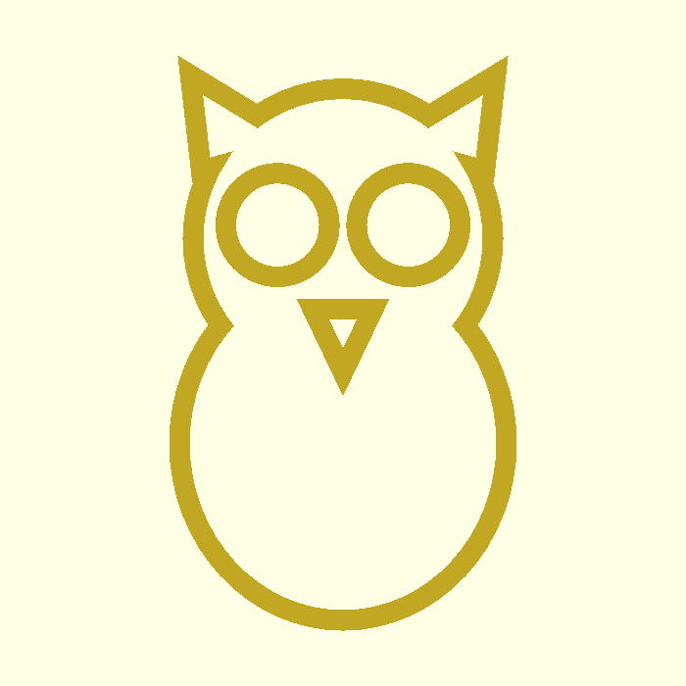
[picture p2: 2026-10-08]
caixa/previa_coruja.png

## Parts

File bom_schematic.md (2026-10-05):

# 🗺️ Projeto: Detector de Radares GPS Inteligente (Pico 2 W)

**Plataforma:** Raspberry Pi Pico 2 W (RP2350) — firmware em **C++17 / Pico SDK**
**Revisão:** 2 — 2026-09-15

> **Revisão 2:** incorpora as correções de `revisao_tecnica.md`. Alterações em relação à
> revisão 1 destacadas com ⚠️ e rastreadas ao final. Não há suposições pendentes neste
> documento; restam **3 medições de bancada** e **1 inspeção** (regulador da placa GPS),
> listadas ao final.

---

## 📦 Bill of Materials (BOM) — Lista Completa de Componentes

| Item | Componente | Especificação Técnica / Detalhes | Função no Projeto | Status |
| :---: | :--- | :--- | :--- | :---: |
| 1 | **Raspberry Pi Pico 2 W** | Microcontrolador Dual-Core RP2350 com Wi-Fi (pinos macho pré-soldados) | Cérebro do sistema, processamento NMEA e conectividade sem fio. | 🟢 entregue |
| 2 | **Módulo GPS u-blox NEO-M8N** em placa **GY-GPS6MV2** — ℹ️ **não é erro:** essa placa é vendida com vários chips u-blox (do 6M ao M8N) e a versão **M8N** foi a escolhida na compra. O nome da placa é da família, não do chip; não "corrigir" para NEO-6M. | ⚠️ **CORRIGIDO 2026-10-01:** UART, e antena ativa em **patch cerâmico com rabicho de 8 cm e conector U.FL / IPEX MHF1** — a fêmea da placa mede ~2 mm a paquímetro. **Não é SMA**, e não há cabo roteável: 8 cm não saem de dentro do gabinete. **30 ciclos de encaixe** (datasheet Hirose) — conector de montagem, não de manutenção. Ver `montagem.md` §4.8 | Rastrear velocidade, coordenadas e rumo em tempo real. | 🔵 comprado |
| 3 | **Leitor Micro SD Adafruit 4682** | Breakout board nativo para nível lógico de 3,3 V (*3V ONLY!*) | Interface física para o cartão de memória. | 🟢 entregue |
| 4 | **Cartão Micro SD** | 8 GB ou 16 GB, formatado em **FAT32** | Armazenar `radares.bin` (214 KB) e `wifi.cfg`. | 🟢 entregue |
| 5 | **Display IPS TFT 2,4"** | `GMT024-08-SPI8P ver. 1.3`, controlador **ST7789V**, **240×320** nativo (usado deitado, 320×240), SPI de **8 pinos — sem MISO** | Exibir velocidade, limites e alertas visuais. | 🟢 recebido, controlador confirmado |
| 6 | **Encoder Rotativo KY-040** | Módulo incremental com chave/botão de pressão no eixo | Girar: ajuste PWM do brilho.<br>Clicar: comando de atualização Wi-Fi. | 🟢 entregue |
| 7 | **Buzzer Piezo Ativo** | **SFM-20B** (95 dB, 10 mA, 3,9 kHz, 3–24 V, 22 mm) **ou SFM-27** (até 105 dB, ~50 mA). **Ativo** é obrigatório — ver nota | Bipes audíveis no painel. **Soldado direto** desde 2026-09-25 — trocá-lo exige dessoldar. | 🔵 comprado |
| 8 | ⚠️ **LED RGB 10 mm Difuso** | **Ânodo comum** (terminal mais longo vai ao **3V3**) — **lógica invertida**, ver nota | **Único indicador luminoso do projeto.** Estado de via: verde / amarelo / rosa / vermelho. | ⚪ disponível |
| 9 | ⚠️ **Transistor NPN BC337** | TO-92 — ou **2N2222**. **Não usar BC547** | Chave eletrônica para acionar o buzzer de **12 V** com margem de corrente. `Vceo` de 45 V no BC337 e 30 V no 2N2222 — ambos com folga. | ⚪ disponível |
| 10 | **Resistor de 330 Ω** | ✅ **Medido na bancada** (2026-09-19) — canal **vermelho** do LED | Limita a corrente do canal vermelho. | ⚪ disponível |
| 11 | ✅ **Resistores de 150 Ω e 470 Ω** | **Medidos na bancada** (2026-09-19): **150 Ω no azul**, **470 Ω no verde**, um de cada. Os 68 Ω especificados antes **não são usados** | Limitam a corrente dos canais azul e verde. | ⚪ disponível |
| 12 | ⚠️ **Resistores de 1 kΩ** | **2 unidades** — filme de carbono ou metálico | Base do transistor do buzzer **+ série no `GPIO 0 → GPS RX`** (R-22). | ⚪ disponível |
| 13 | ⚠️ **Diodo Schottky** | Ou SS34 / 1N5817 — queda direta ≤ 0,45 V | **Novo na rev. 2.** Proteção da entrada de 5 V em `VSYS`. | ⚪ disponível |
| 14 | ~~**Diodo 1N4148**~~ | **Removido do projeto** (2026-09-25) | Era roda-livre para carga indutiva; o buzzer é piezo, capacitivo. Nunca conduziria. Ver nota. | ⛔ dispensado |
| 15 | ⚠️ **Capacitor Eletrolítico** | ✅ **470 µF / 16 V / 105 °C** confirmado em mãos. Em `VSYS` (~4,7 V) opera a **29% do nominal** — atenção à polaridade | Filtrar quedas de tensão e ruído de baixa frequência do alternador. | ⚪ disponível |
| 16 | **Capacitor Cerâmico** | **100 nF (0,1 µF)** — código impresso: 104 | Suprimir ruído de alta frequência da ignição. | ⚪ disponível |
| 17 | **Capacitores Cerâmicos 1 a 10 nF** | 2 unidades. **OPCIONAL** — contingência, não requisito. **Nunca 100 nF** | Filtro RC do encoder, só se o brilho oscilar no veículo. | ⚪ dispensável |
| 18 | ~~**Conector do buzzer**~~ | **Não é mais usado** (2026-09-25) | Os dois fios do buzzer saem da placa **soldados direto**. Ver seção 5. | ⛔ dispensado |
| 19 | ⚠️ **Conector de entrada, 3 vias** | Par macho + fêmea. **Pino central sem uso**. Família a confirmar — ver nota | 🔌 **ÚNICO conector externo do aparelho.** Traz os **12 V do pós-chave** (não 5 V: o conversor está dentro do gabinete desde o ADR 0009). | ⚪ disponível |
| 20 | **Placa Perfurada (Perfboard)** | Fenolite ou fibra com furos metalizados (pitch 2,54 mm) | Base de montagem do circuito. | ⚪ disponível |
| 21 | **Barras de Pinos Fêmea 1x20** | Duas fileiras, espaçamento 2,54 mm | Soquete para encaixar e remover o Pico 2 W sem soldá-lo direto. | 🔵 comprado |
| 22 | 🆕 **Conversor CC 12 V → 5 V** | Buck. **Entrada ≥ 40 V** (*load dump*). Saída ≥ 1 A, preferir **ajustável** | Alimenta o aparelho. Montado **dentro** do gabinete desde o ADR 0009. Proteger com termorretrátil. | 🔵 comprado |
| 23 | 🆕 **Adaptador de fusível piggyback** | *"add-a-circuit"*, do tipo de fusível da caixa do seu carro (mini, padrão ou micro2) | Deriva um circuito pós-chave na caixa de fusíveis **sem emenda no chicote**. Reversível. | ⚪ disponível |
| 24 | 🆕 **Fusível de 2 A** | Do mesmo tipo do adaptador. **Fica dentro do gabinete** (2026-09-28) | Protege o **aparelho**; o cabo até ele é protegido pelo fusível do carro, já que a derivação é no pós-chave. **Não use 10 A** — ver nota de dimensionamento. | 🔵 comprado |
| 25 | **Cabo 1,5 mm²** | ✅ Em mãos: **1 via, flexível**. Usar **dois trechos trançados** entre si — ver nota | Do pós-chave ao conversor (trecho de 12 V). Sobredimensionado para a carga (~180 mA), o que é seguro. | ⚪ disponível |
| 26 | 🆕 **Fio 22 AWG, cobre estanhado** | 0,35 mm². Cores variadas — ver convenção abaixo | Fiação **interna** do gabinete, cabo do **conversor ao gabinete** (5 V) e cabo até o buzzer. | ⚪ disponível |
| 27 | 🆕 ⚠️ **Diodo TVS bidirecional 24 V** | **P6KE24CA** (600 W) ou **1.5KE24CA** (1500 W). Axial, **bidirecional** — sufixo `CA` | **Na entrada de 12 V do conversor.** Clampa transientes da rede do carro. Ver nota de dimensionamento. | 🔵 comprado |
| 28 | 🆕 ⚠️ **Capacitor Eletrolítico 470 µF / 50 V** | **50 V é exigência, não preferência** — ver nota. 105 °C, atenção à polaridade | **Na entrada de 12 V**, em paralelo com o TVS. Segura o que o TVS não pega e amortece a queda na partida. | 🔵 comprado |### Situação em 2026-09-19

Levantado item a item com o autor. Os 7 itens que faltavam foram comprados em 18/09 e
devem chegar na semana de 22/09, junto com o GPS e o display.

| | Qtd | Itens |
| :--- | ---: | :--- |
| 🟢 **entregue** | 4 | 1, 3, 4, 6 |
| 🔵 **comprado** | 8 | 2, 5, 7, 21, 22, 24, 27, 28 |
| ⚪ **disponível** | 15 | 8, 9, 10, 11, 12, 13, 14, 15, 16, 18, 19, 20, 23, 25, 26 |
| ⚪ **dispensável** | 1 | **17** — capacitores de debounce, ver abaixo |
| 🔴 **faltante** | **0** | — |

#### Nada faltante: o item 17 saiu do caminho crítico

O item 17 eram **100 nF**, e com eles **o encoder não decodifica giro nenhum** (R-36).
Em vez de trocar por 1 a 10 nF, o RF04 foi revisado: a **máquina de estados de
quadratura passou a ser o debounce**, e o filtro RC virou contingência documentada.

A montagem vai **sem capacitor** em `CLK` e `DT`. O lugar deles fica na placa — se o
brilho oscilar sozinho no veículo, soldar 1 a 10 nF resolve. Os 100 nF comprados ficam
de sobra e servem de filtro em outros pontos.

#### O que já foi validado na placa em 19/09

| Item | Resultado |
| :--- | :--- |
| **R-05 — LED RGB** | ✅ **concluído**: 330/470/150 Ω e PWM âmbar 19,6%, rosa 15,7%. Os quatro estados de via são distinguíveis |
| Encoder — clique | ✅ 18 cliques sem evento duplicado |
| Encoder — giro | ✅ 160 eventos, quadratura íntegra nos dois sentidos, **sem** os 100 nF |
| Mapa de pinos do LED | ✅ corrigido: vermelho no GPIO 8, azul no 6 (R-35) |
| Inversão de PWM do ânodo comum | ✅ correta |

#### O que ainda espera entrega

| Seção da bancada | Aguarda |
| :--- | :--- |
| §02 — R-17, buzzer e pinagem do 2N2222 | buzzer (item 7) |
| §03 — R-13, trilho de 3V3 | display (item 5) |
| Inspeção do display e serigrafia do GPS | itens 5 e 2 |
| R-32 — audibilidade a 80 km/h | buzzer + instalação |

### Legenda de status

| Status | Significa |
| :--- | :--- |
| 🟢 **entregue** | comprado e já em mãos |
| 🔵 **comprado** | pago, em trânsito |
| ⚪ **disponível** | já tinha em casa; não foi comprado para este projeto |
| 🔴 **faltante** | ainda não comprado |
| ⚪ **dispensável** | previsto, mas a montagem decidiu não usar |
| ❓ | a confirmar |

### ⚠️ Nota — fiação interna em 22 AWG (item 26)

O 22 AWG (0,35 mm²) suporta ~3 A contínuo, contra um máximo de **310 mA** em qualquer
ramo interno — margem de 10× no pior caso. A queda de tensão é desprezível em todos:

| Ramo | Corrente | Compr. | Queda (ida e volta) |
| :--- | ---: | ---: | ---: |
| 12 V da entrada ao conversor | 200 mA | 15 cm | 3,2 mV |
| 5 V do conversor ao `VSYS` | 310 mA | 10 cm | 3,3 mV |
| GND geral | 310 mA | 15 cm | 4,9 mV |
| 3V3 ao display e cartão | 220 mA | 12 cm | 2,8 mV |
| **Conversor ao gabinete (5 V)** | **310 mA** | **1,5 m** | **49 mV** |
| Buzzer, cabo até o painel | 50 mA | 2 m | 10,6 mV |

**Cobre estanhado é a escolha certa aqui**, e não só pela solda: o estanho protege
contra oxidação, o que importa num ambiente com variação térmica e umidade como o
interior de um painel.

> 💡 **Convenção de cor**, espelhando as cores dos fios no Fritzing: preto para GND,
> vermelho para 5 V, **amarelo para 12 V**, azul para 3V3 — e **verde para todo
> sinal**, sem distinguir grupos.
>
> **As cinco cores são exatamente as da caixa de fios do autor** — 10 m de cada.
> Isso não é detalhe: uma convenção que exige comprar fio avulso é abandonada no
> meio da montagem, e uma que sai da caixa que já está na bancada é a que de fato
> se segue. A restrição veio do estoque e melhorou o esquema.
>
> O esquema anterior dava cor própria a cada grupo de sinal (SPI0, SPI1, display,
> GPS, encoder, LED, buzzer): onze cores — seis a mais do que existem à mão. Foi trocado por quatro tensões mais
> verde em 2026-09-29, porque na perfboard o erro que custa caro é de **tensão**,
> não de sinal — trocar um fio de sinal dá um periférico que não responde, trocar
> 12 V por 3,3 V destrói Pico, GPS, display e cartão juntos. O que se perde é
> rastrear grupo de sinal pela cor; com tudo verde, distinguir o `SCL` do cartão
> do `SCL` do display exige seguir o fio ou consultar a netlist.
>
> ⚠️ A revisão anterior mandava vermelho para 5 V **e** 12 V. Não serve mais: desde que
> o conversor veio para dentro do gabinete, as duas tensões convivem a centímetros uma
> da outra, e 12 V no trilho de 5 V destrói Pico, GPS, display e cartão juntos. Cor
> igual para tensões incompatíveis é um erro esperando acontecer.
>
> Nos sinais, qualquer cor — mas manter a
> mesma do esquemático poupa conferência durante a montagem.

### ✅ Nota — o conector externo do aparelho

Desde 2026-09-25 o gabinete tem **um único conector externo**, e ele é de **12 V**:

| Conector | Vias | Pino A | Pino B |
| :--- | :---: | :--- | :--- |
| **Entrada** (item 19) | **3** (central sem uso) | **+12 V** do pós-chave | GND |

O buzzer saía por um segundo conector e agora é **soldado direto** (seção 5). Isso
**apaga** um risco em vez de administrá-lo — não existe par para trocar.

#### Como se chegou aqui, e por que os passos anteriores não bastavam

| Quando | Saída do buzzer | O que o passo resolvia |
| :--- | :--- | :--- |
| rev. 1 | Jack P2 3,5 mm | — |
| 2026-09-15 (R-06) | JST-XH 2 vias | tira o curto do sleeve varrendo o tip na inserção |
| ADR 0009 | header genérico 2 vias | padronização visual; **perdeu a polarização** |
| 2026-09-25 (R-49) | **soldado, sem conector** | remove o risco em vez de administrá-lo |

Cada passo intermediário administrou melhor a **mesma** falha — plugar a coisa errada
no soquete errado — e o header genérico até piorou, por não ser polarizado. A
contagem diferente de vias (3 contra 2) era a última proteção que restava, e era
fraca: protege contra encaixe, não contra teimosia.

#### O que passou a importar

Sem um segundo conector, a troca entre conectores deixou de ser um modo de falha. O
que sobra na entrada é a **inversão de polaridade**: com o TVS bidirecional, uma
inversão chega direta ao conversor, e não há proteção nesse trecho — ver
*"Polaridade reversa"* na análise de falhas. A propriedade que importa no conector de
entrada, portanto, **deixou de ser a contagem de vias e passou a ser o chaveamento
mecânico** (o encaixe só entrar de um jeito).

As 3 vias com o pino central sem uso são **herança**: existiam para não encaixar no
conector de 2 vias do buzzer. Sem o buzzer, não fazem mal e não fazem falta — mantê-las
ou passar a 2 vias é indiferente do ponto de vista elétrico.

> 🔴 **O dano real continua sendo qualquer caminho que leve os 12 V ao trilho de 5 V**,
> cujo máximo absoluto é 5,5 V. Daí a cor distinta do fio: amarelo, não vermelho.

### ✅ Nota — resistores do LED RGB, **medidos** (itens 10 e 11)

**Valores finais, escolhidos na bancada em 2026-09-19** com fonte de 3,3 V, julgados
**sob luz solar direta**, que é o pior caso de visibilidade:

| Canal | Resistor | GPIO |
| :--- | ---: | :--- |
| Vermelho | **330 Ω** | 6 |
| Verde | **470 Ω** | 7 |
| Azul | **150 Ω** | 8 |

#### A previsão anterior deste documento estava errada

A revisão 2 afirmava que **330 Ω deixaria verde e azul praticamente invisíveis**, e
mandava trocá-los por 68 Ω. O raciocínio olhava só o lado **elétrico**: `Vf` de 3,0 a
3,2 V contra um trilho de 3,3 V deixaria ~0,1 V no resistor, logo menos de 1 mA.

A medição mostrou o contrário. O verde precisou do **maior** resistor dos três, não do
menor. O que faltava no raciocínio era o lado **fotométrico**:

| Canal | Resistor medido | Sensibilidade do olho |
| :--- | ---: | ---: |
| Verde ~555 nm | **470 Ω** | **1,00** — pico da visão |
| Vermelho ~630 nm | 330 Ω | 0,27 |
| Azul ~470 nm | **150 Ω** | **0,09** |

A ordem dos resistores é **exatamente o inverso** da ordem de sensibilidade, o que é
coerente: a 1 mA o verde parece cerca de 11× mais brilhante que o azul de mesma
corrente. Dimensionar canal de LED colorido só pela corrente ignora que o olho não é
plano em frequência.

#### O que isso fecha

* **Nenhum componente novo.** A saída de contingência — trocar o LED, ou acionar verde
  e azul pelos 5 V com um transistor por canal — **não é necessária**. O BOM não cresce.
* **R-19 e RF03.9 destravados.** Havia dúvida se existiria verde suficiente para compor
  o amarelo da Zona de Semáforo, e azul para o rosa da faixa de margem. Existe.
* **Os 68 Ω do item 11 não serão usados.** Foram comprados antes da medição; ficam de
  sobra. Os 150 Ω e 470 Ω saem do estoque em casa.
* **Alívio para o R-13.** Somando os três canais no pior caso, o LED contribui com
  poucos miliampères para o trilho de 3V3 — desprezível perto do display e do cartão.

#### Duas ressalvas

1. **O teste foi com fonte de bancada ligada direto ao LED**, a 3,30 V. No circuito
   final o ânodo comum fica no `3V3_OUT` e o **GPIO drena**, com `Vol` de ~0,2 V:
   sobram ~3,10 V, cerca de **7% menos corrente**. Diferença imperceptível, mas os
   valores não são idênticos.
2. **`Vf` não foi anotado**, então a corrente de cada canal é estimativa e não medida.
   Para o R-13 isso basta; se um dia o orçamento do trilho apertar, vale medir.

### ⚠️ Nota — transistor do buzzer (item 10)

O BC547 tem corrente de coletor máxima de 100 mA. Um piezo de 95–105 dB pode consumir
30–50 mA, mais a capacitância do cabo até o painel — margem insuficiente. O BC337
(500 mA) e o 2N2222 (800 mA) têm o mesmo custo e encapsulamento. Medir o consumo real
do buzzer adquirido.

#### 🆕 🔴 "2N2222" não define uma pinagem só

A peça em mãos é um **2N2222** (item 9). Não basta dizer "confirmar no datasheet": o
**mesmo nome** é vendido em variantes com pinagens **espelhadas entre si**.

| Marcação | Encapsulamento | |
| :--- | :--- | :--- |
| `P2N2222A` | TO-92 plástico | uma ordem |
| `PN2222A` | TO-92 plástico | **ordem espelhada** da anterior |
| `2N2222A` | TO-18 metálico | terceira disposição, com aba de referência |

**Leia a marcação impressa no corpo** e puxe o datasheet daquela variante. Não vale
analogia com o BC337 nem com o que "costuma ser".

**O que é seguro em qualquer caso:** em TO-92, a **base é o pino central** nas duas
famílias. O resistor de 1 kΩ vai no meio sem precisar medir. O que pode estar trocado
são **coletor e emissor**, nos dois pinos das pontas.

**Inverter C e E não queima nada** — o transistor opera em modo reverso, com ganho de 2
a 5 em vez de ~200:

```
base:  (3,3 − 0,7) / 1 kΩ   ≈  2,6 mA
modo reverso, ganho ~3      ≈  7,8 mA de coletor
SFM-20B precisa de          ≈  10 mA
```

> ✅ **O sintoma real a 12 V, OBSERVADO em 2026-10-03: o buzzer fica LIGADO DIRETO,
> ignorando o firmware.** Não é "mais fraco", que era a previsão anterior desta nota.
>
> A previsão de som fraco vale a **5 V**, onde C e E trocados colocam o transistor em
> modo reverso com ganho de 2 a 5 — ele quase dá conta dos 10 mA do SFM-20B. A **12 V**
> o que domina é outra coisa: a junção **base-emissor entra em ruptura** (medida em
> 9,13 V nesta peça) e abre um caminho de corrente que **o GPIO não interrompe**. O
> buzzer toca desde que o aparelho liga, e nada no software o cala.
>
> 🟢 **Isso é uma boa notícia de diagnóstico.** Os 12 V transformaram uma falha sutil
> numa falha óbvia: a 5 V o erro passaria despercebido como "buzzer meio fraco", e a
> 12 V é impossível não notar. O que torna o erro perigoso para a peça é o que o torna
> visível.
>
> 🔴 Mesmo assim, **não** tente as duas orientações no circuito do buzzer para
> descobrir qual é — determine a pinagem **antes** de montar, pela ruptura reversa
> descrita adiante. A orientação errada degrada o hFE permanentemente (R-67).

#### 🔴 Inverter C e E DESTRÓI a peça — o buzzer está em 12 V

> ⚠️ **Corrigido em 2026-10-03 (R-67).** A redação anterior dizia que não havia risco em
> tentar as duas orientações, e que o trilho era de 5 V. **O trilho é de 12 V desde o
> ADR 0009** — é a razão de os 12 V entrarem no gabinete.

Em modo reverso quem bloqueia a alimentação é a junção **base-emissor**, e ela é frágil:

| Peça | `V_EBO` | Aplicado a 12 V | |
| :--- | ---: | ---: | :--- |
| 2N2222 | 6 V | ~12 V | **2× o limite** |
| BC337 | 5 V | ~12 V | **2,4× o limite** |

E nos **dois** estados do GPIO: com o pino baixo o emissor fica em ~12 V contra base em
0 V; com o pino alto, ~12 V contra 3,3 V. Não há estado seguro.

A corrente fica limitada pelo buzzer, então **degrada em vez de destruir** — ruptura
reversa de base-emissor derruba o hFE permanentemente. O que é pior para diagnosticar:
um transistor com hFE degradado ainda satura numa chave, então **o dano também não
aparece**. Soma-se ao sintoma sutil descrito acima.

#### ✅ Pinagem MEDIDA desta peça — 2026-10-03

A peça em mãos traz `2N2222` na primeira linha e `A331` na segunda — **sem prefixo de
fabricante**, logo é o número JEDEC genérico e **o método "leia a marcação e puxe o
datasheet daquela variante" NÃO funcionou**: `2N2222A` puro não identifica a disposição.

Determinada por medição:

| | Resultado |
| :--- | :--- |
| Tipo | **NPN** — conduz com a ponta vermelha no central para os dois outros |
| Base | **pino central**, ~0,44 V nas duas junções |
| Ponta a ponta | aberto nos dois sentidos — sem curto |
| **Face chata para o observador, pernas para baixo** | **E – B – C** (esquerda → direita) |

#### Como determinar na bancada — teste de ruptura reversa

**Substitui o teste funcional**, que não depende mais de ganho, saturação nem modo
reverso. As duas junções da base rompem em tensões muito diferentes: **base-emissor em
~6 V, base-coletor em 60 a 75 V.**

1. **Ache a base.** Teste de diodo: o pino que dá ~0,7 V para os **dois** outros com a
   ponta **vermelha** nele. Deve ser o central. (Se conduzir com a **preta** no central,
   a peça é **PNP** e não é o que está escrito nela.)
2. **12 V através de ≥ 47 kΩ** num pino de ponta, **base no GND**, o outro pino de
   ponta **solto**. Meça o pino sob teste contra o GND.

| Leitura | Pino |
| ---: | :--- |
| ~6 a 9 V | **EMISSOR** — grampeou |
| ~12 V | **COLETOR** — não rompe |

3. Repita no outro pino. Os dois têm de dar resultados **opostos**.

> ⚠️ **O resistor é a proteção, não o limite de corrente da fonte.** Com 47 kΩ a
> corrente na ruptura fica em ~130 µA, a ordem em que o datasheet especifica o
> parâmetro — não destrutiva. Com 1 kΩ seriam 6 mA e a junção degrada. Conferir com os
> olhos que o resistor está em série antes de energizar.

**Medição real desta peça (2026-10-03):** esquerda 9,13 V, direita 11,47 V. Diferença de
2,3 V, inequívoca. Os 11,47 V em vez de 12 V se explicam pela impedância de entrada do
multímetro (~1 MΩ carregando os 47 kΩ), não por condução da junção.

> 📋 **O teste de saturação foi tentado antes e NÃO discriminou:** as duas orientações
> deram ~35 mA. A causa não foi apurada — provavelmente a base não estava sendo
> acionada, ou duas pernas caíram no mesmo trilho da protoboard. Fica o registro de que
> o teste de ruptura é mais robusto justamente por não depender de ganho.

### ⛔ Nota — o diodo do buzzer foi REMOVIDO (item 14)

**Removido em 2026-09-25.** Fecha o **R-16**, aberto desde a revisão 1.

A revisão 1 justificava o diodo como *"roda livre para absorver o pico de retorno
magnético do buzzer"*. A justificativa estava incorreta: o SFM-27 é **piezo ativo**,
carga capacitiva com oscilador interno, sem indutância significativa. Não há pico
magnético a absorver. O R-16 registrou isso, mas o componente ficou como "opcional" e
sobreviveu no esquema por mais de uma revisão.

**Por que ele não fazia nada.** Em antiparalelo com o buzzer, ficava reversamente
polarizado nos dois estados estáticos:

| Estado | Coletor | Sobre o diodo | Conduz? |
| :--- | :--- | :--- | :---: |
| `Q1` cortado | ≈ +12 V (sobe pelo buzzer) | ≈ 0 V | não |
| `Q1` saturado | ≈ 0,2 V | 12 V reverso | não |

Só conduziria no **transitório de desligamento de uma bobina**, quando a indutância
empurra o coletor acima do +12 V; aí ele grampearia em ~12,7 V em vez de deixar o pico
passar dos 45 V de `Vceo` do `BC337`. Carga capacitiva não produz esse transitório.

**O que derrubou o último argumento.** Mantê-lo se justificava como seguro contra uma
troca futura por buzzer eletromagnético. Com o buzzer **soldado** (R-49), essa troca
passou a exigir dessoldar — e nesse momento se solda o diodo junto. O seguro deixou de
ter quando ser útil.

> **Se um dia entrar um buzzer eletromagnético:** `1N4148` em antiparalelo com ele,
> **catodo no +12 V protegido**, anodo no coletor. Não no 5 V — a roda-livre
> referencia a alimentação do buzzer, e ela é 12 V desde o ADR 0009.

---

### 🆕 Nota — cabo de 12 V com dois trechos de 1 via (item 25)

O cabo em mãos é de **1,5 mm², 1 via, flexível**. Serve: use **dois trechos**, um para
`+12 V` e outro para `GND`, e **trance-os entre si** ao longo do percurso.

Eletricamente é idêntico a um cabo de 2 vias. O trançado não é estética: ele reduz a
**área de laço** do par, e com isso a captação e a irradiação de ruído — o que importa
porque esse cabo corre sob o painel perto da antena do GPS, e o conversor chaveia a
150 kHz.

> ⚠️ **Flexível é requisito, não preferência.** Cobre maciço encrua com vibração e
> fratura por fadiga, tipicamente junto ao ponto de fixação. A falha é intermitente e
> difícil de localizar. O cabo em mãos é flexível — confirmado.

### 🆕 ⚠️ Nota — proteção da entrada de 12 V (itens 27 e 28)

**O que estava desprotegido.** O fusível de 2 A protege o **fio** contra curto, não o
conversor contra sobretensão: fusível não reage a um transiente de dezenas de volts por
milissegundos. E o `C1`/`C2` da seção 1 ficam em `VSYS`, ou seja **depois** do
conversor — protegem o Pico, não a fonte dele. O conversor era o único componente
exposto à rede do carro, e o desenho contava com ele aguentar sozinho. Registrado como
**R-31**.

**Por que 24 V de standoff.** O clamp precisa ficar numa janela estreita:

| Limite | Valor | Por quê |
| :--- | ---: | :--- |
| Piso | **> 16 V** | a rede é 13,8 a 14,4 V com o motor ligado; clampar abaixo disso conduziria em operação normal e queimaria o diodo |
| Teto | **< 40 V** | máximo absoluto do LM2596 é 45 V; o clamp tem de proteger antes disso |

O **24CA** clampa em **33,2 V** — no meio da janela. Para comparação, um `1.5KE30CA`
clampa em 41,4 V, colado no limite do chip, e um `47CA` clampa em 65 V, que não protege
nada. **O sufixo `CA` é obrigatório**: significa bidirecional. A versão `A` é
unidirecional e, montada ao contrário, fica em curto permanente.

**Honestidade sobre o que isso resolve.** Um *load dump* real — bateria se desconectando
com o alternador carregando — chega a 60 a 120 V com impedância de fonte de ordem de
ohms, por até 400 ms. Contra um clamp de 33 V isso dá dezenas de ampères e **mais de
1 kW sustentado**; nem 600 W nem 1500 W de rating de pulso (10/1000 µs) sobrevivem a
isso. Alternador de carro moderno já clampa o load dump internamente em ~35 V, e é nisso
que o projeto se apoia.

O que o TVS **de fato** resolve são os transientes frequentes e de baixa energia:
chaveamento de cargas indutivas, ruído de ignição, os pulsos da ISO 7637-2. São esses
que matam módulo barato no uso diário, e para esses 600 W bastam. É proteção bem
investida, não blindagem contra tudo.

**Por que 50 V na entrada é exigência, e não folga por precaução.** O motivo não é a
tensão normal da rede — é **o próprio TVS**. Durante um transiente o TVS segura o nó em
até **33,2 V**, e o capacitor está **em paralelo com ele**: vê os mesmos 33,2 V. Um
eletrolítico de 25 V nessa condição é sobretensão direta, e eletrolítico sobretensionado
não degrada devagar, ele **abre a válvula**.

Só pela tensão da rede um 25 V passaria — a 14,4 V ele opera a 57,6%, dentro da regra de
≤ 80%. É a interação com o clamp que o desqualifica, e é o tipo de coisa que se perde ao
dimensionar cada componente isoladamente.

| Nominal | A 14,4 V (rede) | A 33,2 V (clamp do TVS) |
| ---: | ---: | :--- |
| 16 V | 90% — **inadequado** | destruído |
| 25 V | 58% — ok | **sobretensão** |
| **50 V** | 29% — ok | **66% — ok** |

**E o da saída, em `VSYS`?** Papel diferente: a ~4,7 V, um **16 V** opera a 29% do
nominal, o que é confortável, e é exatamente o que o BOM sempre pediu para o item 15. Ali
o que importa não é tensão, é capacitância e o rating de **105 °C** — o painel passa de
60 °C e a vida de um eletrolítico cai pela metade a cada 10 °C.

---

## 🔌 Esquema de Conexões e Roteamento (Fritzing)

Mapeamento de nós para interligar os componentes na aba "Esquemático" ou "Protoboard".

### 🆕 0. Instalação no veículo

A alimentação vem do **pós-chave**, derivada na caixa de fusíveis. Desde 2026-09-21 o
conversor CC fica **dentro do gabinete**, e o que entra é **12 V** — o buzzer passou a
ser alimentado em 12 V e isso exige o 12 V lá dentro de qualquer forma. Ver ADR 0009.

```
bateria ─ caixa de fusíveis ─┬─ [circuito original do carro]
                             └─ piggyback ─ fusível 2 A
                                    │
                                    │  1,5 mm², 12 V
                                    ▼
                          conector de entrada, 3 vias      ← ÚNICO conector
                                    │                          externo (item 19)
          ═══════════════ fronteira do gabinete ═══════════════
                                    │
                          ┌─── proteção da entrada ───┐
                          │  TVS P6KE24CA   ┬  470 µF │  itens 27 e 28
                          │  (bidirecional) │   50 V  │  em paralelo, junto
                          └────────┬────────┴─────────┘  ao conversor
                                    │
                                    ├───────────────► buzzer, 12 V
                                    │                 (soldado, sem conector)
                                    ▼
                          ┌──────────────────────┐
                          │ conversor 12 V → 5 V │   DENTRO do gabinete
                          │  (ajustável)         │   (ADR 0009)
                          └──────────┬───────────┘
                                     │  5 V
                                     ▼
                          Schottky ─ VSYS (pino 39)      ← seção 1
```

> ✅ **O fusível de 2 A fica DENTRO do gabinete** — decidido pelo autor em 2026-09-28,
> e é o que a netlist já dizia. A derivação é no **pós-chave**, que sai da caixa de
> fusíveis **já protegido**: o fusível do carro cuida do cabo, e o de 2 A cuida do
> aparelho. Dois fusíveis em série no mesmo ramo seriam redundância sem função.
>
> A consequência a ter em mente: o cabo entre a caixa de fusíveis e o gabinete fica
> protegido pelo fusível **do carro**, na amperagem dele, e não em 2 A. Com 1,5 mm² e
> uma via de acessórios típica isso é folgado — a bitola aguenta bem mais do que o
> fusível do circuito deixa passar.
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

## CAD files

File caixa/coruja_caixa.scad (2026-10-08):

// =============================================================================
//  coruja_gps — caixa impressa em 3D
//
//  Caixa com batente interno e tampa que desce por cima, presa por atrito.
//  Sem parafuso, por decisão do autor em 2026-10-05.
//
//  Exportar:
//    OpenSCAD -o caixa.scad.stl -D 'PECA="caixa"' coruja_caixa.scad
//    OpenSCAD -o tampa.scad.stl -D 'PECA="tampa"' coruja_caixa.scad
//
//  ## O que é MEDIDO e o que é SUPOSTO
//
//  O bloco de parâmetros está dividido em dois. O primeiro saiu da peça
//  física, a paquímetro, e está no `medidas.py` do projeto. O segundo são
//  escolhas e estimativas minhas — cada uma marcada, porque caixa impressa
//  com cota suposta errada é peça para o lixo.
//
//  ## ⚠️ A tampa fica virada para o CÉU
//
//  Não é detalhe estético: a antena GPS é um patch colado na placa e enxerga o
//  céu através dela. Por isso a tampa é lisa e fina, sem reforço sobre a área
//  da antena, e o plástico precisa ser transparente a 1,5 GHz — qualquer
//  filamento com carga de fibra de carbono está fora.
//
//  Efeito colateral bom: a gravidade ajuda a tampa a ficar no lugar, então o
//  encaixe pode ser folgado em vez de apertado. Num encaixe que ninguém pode
//  testar antes de imprimir, folgado é o erro mais barato.
// =============================================================================

PECA = "ambas";      // "caixa", "tampa", "ambas", "teste" ou "cupom"

// =============================================================================
//  DE QUE LADO FICA O ENCODER
// =============================================================================
//
// "esquerda"  →  encoder | display | buzzer     (modelo A)
// "direita"   →  buzzer  | display | encoder    (modelo B)
//
// ⚠️ **Não há escolha certa em abstrato.** Depende de onde a caixa é montada no
// painel e de qual mão alcança o botão — e as duas coisas mudam por pessoa e
// por veículo.
//
// O achado que criou este parâmetro, em 2026-10-06: com o protótipo montado no
// carro e o encoder à esquerda, a mão do autor — destro — **cobria o display
// inteiro** ao girar o botão. Não apareceu em desenho nenhum; apareceu dirigindo.
//
// Quem for montar: **simule o gesto antes de imprimir.** Ponha a mão na posição
// onde o botão vai ficar, no lugar onde a caixa vai ficar, e veja o que o braço
// esconde. Cinco segundos de mímica contra horas de impressão.
LADO_ENCODER = "esquerda";

// Altura da fatia de teste: os N mm superiores da caixa, com o batente
// inteiro. Serve para validar encaixe, parede e material sem imprimir a peça
// cheia — e, no tamanho real de 130 mm, revela empenamento, que uma amostra
// pequena esconderia.
ALTURA_TESTE   =  20.0;

// Cupom de encaixe: só uma quina da caixa e a quina correspondente da tampa,
// lado a lado. Perde o teste de empenamento — que precisa do tamanho real —
// mas responde a pergunta mais cara, que é a folga do encaixe, por uma fração
// do material.
CUPOM_LADO     =  45.0;
$fn = 64;

// ----------------------------------------------------------------- MEDIDO --
// Tudo abaixo saiu da peça, a paquímetro. Ver `medidas.py`.

PCB_X          = 120.0;   // placa, largura
PCB_Y          = 120.0;   // placa, profundidade
PCB_ESP        =   1.6;   // espessura da placa

DISPLAY_X      =  70.0;   // módulo do display, placa inteira
DISPLAY_Y      =  46.7;
DISPLAY_VIS_X  =  60.8;   // área visível (vidro + moldura preta) — é o recorte
DISPLAY_VIS_Y  =  44.0;

ENCODER_X      =  19.3;   // corpo do encoder
ENCODER_Y      =  26.5;
ENCODER_EIXO   =  20.0;   // comprimento livre do eixo

BUZZER_D       =  22.4;   // corpo do buzzer
BUZZER_FUROS   =  29.6;   // entre centros das orelhas
BUZZER_FURO_D  =   2.6;

// Furos de fixação da placa, em coordenada da planta (origem na quina
// frontal esquerda, y crescendo para a traseira).
FUROS_PCB      = [[8, 112], [112, 112], [8, 8], [112, 8]];
FURO_PCB_D     =   3.2;

// ---------------------------------------------------------------- SUPOSTO --
// ⚠️ Cada um destes é escolha ou estimativa. Os marcados com (MEDIR) mudam a
// peça se estiverem errados.

PAREDE         =   3.0;   // espessura de parede e de piso
FOLGA_PCB      =   2.0;   // entre a placa e a parede, por lado
ESPACADOR      =   5.0;   // altura do pilar que levanta a placa do piso
BORDA_DISPLAY  =  14.0;   // material abaixo do display, na face frontal
                          // (era 10; subiu para 14 para dar folga sobre a PCB)

// ✅ MEDIDO em 2026-10-06: diâmetro externo do canhão roscado, com garras
// externas. 6,7 mm — compatível com rosca M7x0,75, cujo diâmetro menor fica
// perto de 6,1, o que explica os 6,0 lidos antes por dentro da porca.
//
// O furo sai em 6,7 + 0,4 de folga = 7,1 mm.
ENCODER_BUCHA  =   6.7;
LED_FURO       =  10.4;   // (MEDIR) furo do LED de 10 mm na tampa
// ⚠️ (MEDIR) — mas deliberadamente GENEROSAS enquanto não houver medida.
//
// Nestas duas, errar para mais não custa nada: a abertura fica um pouco maior
// que o necessário e ninguém nota. Errar para menos arruína a peça — cartão
// que não sai e cabo que não entra não têm conserto depois de impressa.
//
// Assimetria de custo assim pede folga, não precisão. As medidas nominais
// seriam ~14 x 3 e ~11 x 7,5.
SD_ABERTURA    = [18.0, 5.0];   // rasgo do cartão: largura x altura
USB_ABERTURA   = [14.0, 9.0];   // abertura do cabo do Pico
// ✅ MEDIDO: corpo preto do soquete, que é o que levanta o módulo acima da
// placa. O pino inteiro tem 11 mm; o que interessa aqui é o corpo.
ALTURA_MODULO  =   8.1;

// ⚠️ (MEDIR) Altura do CENTRO de cada abertura acima da base do módulo.
// Não é metade de nada: é onde fica a boca do cartão no leitor, e onde fica o
// conector no Pico. A primeira versão usava ALTURA_MODULO/2, o que punha o
// rasgo no meio do soquete, 6 mm abaixo do cartão — furo na parede errada.
SD_SLOT_Z      =   2.0;   // boca do cartao, acima da base do modulo
USB_Z          =   2.2;   // conector do Pico, acima da base dele

// --------------------------------------------------- conector de alimentacao
//
// GX12-2 ("aviacao"), na traseira. UNICO conector externo do aparelho: traz os
// 12 V do pos-chave, e o conversor fica dentro do gabinete (ADR 0009).
//
// ⚠️ **Por que GX12 e nao jack P4.** O TVS da entrada e BIDIRECIONAL: ele
// clampa transiente mas NAO bloqueia inversao de polaridade, que chega direta
// ao conversor. A propriedade que importa neste conector e o CHAVEAMENTO
// MECANICO -- so entrar de um jeito. Barril 5,5x2,1 falha nisso: centro
// positivo e convencao, nao garantia, e qualquer fonte com plugue igual entra
// invertida. O anel roscado ainda resolve vibracao, que jack nenhum resolve.
//
// ⚠️ **Centrado em X, e e por isso que ele sobe em Z.** O rasgo do cartao vai
// de x=57,7 a 75,7 e ATRAVESSA o centro da parede (x=62). Na altura dele nao
// ha como centralizar. Acima das duas aberturas sobram 39,3 mm livres, e o
// furo cabe ali inteiro com folga.
//
// Centrado porque a caixa tem versao canhota e destra: o conector no meio faz
// a traseira ficar igual nas duas, e a aparencia nao depender do lado em que
// o aparelho foi montado no painel.
GX12_FURO      =  12.5;   // (MEDIR) ⌀12 nominal + 0,5 de folga de impressao
// ⚠️ (MEDIR) Diametro que tem de PERMANECER com a espessura de parede nominal,
// para a porca do GX12 assentar e alcancar a rosca.
//
// E a razao de o reforco ser um ANEL e nao um disco: engrossar a parede sob a
// porca some com o comprimento util de rosca, e aí ela nao fecha. Quem limita
// a espessura aqui nao e a impressao -- e o comprimento roscado da peca
// comprada. Com 3 mm de parede qualquer GX12 fecha; com 4,5 mm, talvez nao.
//
// 18 mm e generoso de proposito enquanto nao houver paquímetro: errar para
// mais custa um anel um pouco menos eficaz, errar para menos arruina a peca.
GX12_VAO_PORCA =  18.0;
GX12_REFORCO_D =  28.0;   // diametro externo do anel de reforco
GX12_REFORCO   =   1.5;   // material extra, por dentro, FORA do vao da porca
// Folga entre o topo das aberturas existentes e o centro do furo novo.
GX12_FOLGA_Z   =   1.5;

// Coruja em relevo na face frontal, abaixo do encoder. Pura decoração — é o
// nome do projeto, desenhado como traço fechado.
// 19 mm cabe nos ~21 mm livres entre o piso da face e a base do encoder,
// com 1,5 mm de folga de cada lado.
CORUJA_ALT     =  19.0;   // altura total da figura
CORUJA_TRACO   =   0.9;   // espessura da linha
CORUJA_RELEVO  =   0.8;   // quanto sobressai da parede

// Nome do aparelho, em relevo abaixo do display.
TEXTO          = "Coruja GPS";
TEXTO_ALT      =   6.0;

BUZZER_SOM_D   =   2.5;   // furos de passagem de som
BUZZER_SOM_N   =     7;   // quantos
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

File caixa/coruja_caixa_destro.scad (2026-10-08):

// =============================================================================
//  coruja_gps — caixa, MODELO B: encoder à DIREITA
//
//      buzzer  |  display  |  encoder
//
//  Mesma geometria do `coruja_caixa.scad`; só as duas colunas laterais trocam
//  de lado. Este arquivo não duplica nada — ele inclui o modelo e sobrepõe um
//  parâmetro.
//
//  Exportar:
//    OpenSCAD -o caixa_destro.stl -D 'PECA="caixa"' coruja_caixa_destro.scad
//    OpenSCAD -o tampa.stl        -D 'PECA="tampa"' coruja_caixa_destro.scad
//
//  A TAMPA É A MESMA nos dois modelos — ela não tem nada lateral, só o furo do
//  LED no centro. Imprima uma só.
//
//  ## Qual modelo escolher
//
//  Ver o cabeçalho de `coruja_caixa.scad` e o README. Em resumo: **simule o
//  gesto antes de imprimir**, no lugar onde a caixa vai ficar. O modelo A
//  (encoder à esquerda) escondeu o display do autor, que é destro — mas isso
//  depende de onde a caixa foi montada, e pode se inverter em outro painel.
// =============================================================================

include <coruja_caixa.scad>

LADO_ENCODER = "direita";

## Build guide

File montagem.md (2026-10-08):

# 🔧 Montagem Física — **v2**

**Projeto:** Detector de Radares GPS Inteligente (Raspberry Pi Pico 2 W)
**Caixa:** impressa em 3D, ASA — 130 × 130 × 67 mm externos
**Placa:** PCB fabricada, 120 × 120 mm, 2 camadas
**Complementa:** `bom_schematic.md` (circuito) e `pcb.md` (placa)
**Data:** 2026-10-05

---

## 0. O que mudou da v1, e por quê

A v1, de 2026-10-01, descrevia uma montagem **artesanal dentro de uma caixa
comprada**: Patola PB-111, chassi de placa perfurada colado com VHB, e o módulo
GPS numa prateleira de fibra presa à tampa com espaçadores.

Em 2026-10-05 três decisões do autor derrubaram essa arquitetura inteira.

| # | Mudança | O que motivou |
| :-- | :--- | :--- |
| 1 | **Placa fabricada** no lugar de placa perfurada | o projeto foi para o KiCad e a PCB foi roteada e verificada |
| 2 | **Caixa impressa** no lugar da Patola | a caixa passa a seguir a placa, e não o contrário |
| 3 | **Antena na PCB** no lugar da prateleira | *"a montagem em prateleira ficou muito bagunçada e ruim de fechar"* |

### A terceira é a mais consequente, e resolve o problema mais duro do projeto

O **R-67** era a restrição mais dura que havia: o rabicho da antena tem **8 cm**,
e o U.FL aguenta **30 ciclos de encaixe**. Na v1, módulo e antena ficavam em
planos diferentes — módulo no chassi, antena na prateleira da tampa —, e os 8 cm
precisavam vencer essa distância toda, atravessando a abertura da caixa, a cada
abertura e fechamento.

Com os dois **vizinhos na mesma placa**, sobra cabo. O U.FL deixa de ser tocado
na manutenção rotineira.

Ganham-se ainda duas coisas que a prateleira de fibra não dava:

- **plano de terra sob a antena** — que é o que um patch cerâmico quer;
- **distância do conversor chaveado**, que fica na extremidade oposta da placa.
  O ruído vem do chaveamento e do indutor do LM2596, não dos capacitores.

> 📌 **O que a v1 ainda vale.** As medições e a química continuam de pé: os
> **92 °C medidos no painel** (R-65), o manuseio do U.FL, a análise de adesivos
> e o método de medir EMI. Tudo isso foi trazido para cá. O que ficou para trás
> foi a geometria.

---

## 1. A arquitetura, em uma página

```
                      ┌──────────────────────────────┐
   TAMPA  ──────────► │  lisa · furo do LED no centro│  ◄── voltada ao CÉU
   encaixe por atrito └──────────────────────────────┘
                       ╔══════════════════════════════╗
                       ║  antena 25×25 colada na PCB  ║ ◄── vista de céu
                       ║                              ║     pela tampa
   FACE FRONTAL ─────► ║ [enc] [ display ] [buzzer]   ║ ◄── voltada ao motorista
   com os recortes     ║                              ║
                       ║  PCB 120×120 em 4 pilares    ║
                       ╚══════════════════════════════╝
                          ▲                        ▲
                     ímã no fundo            TRASEIRA: cartão e USB
```

| Face | O que leva |
| :--- | :--- |
| **Frontal** | encoder · display · buzzer. Recorte do display pela **área visível** |
| **Superior** | tampa lisa, furo único do LED no centro. É por onde a antena vê o céu |
| **Traseira** | rasgo do cartão microSD e abertura do cabo do Pico |
| **Inferior** | adesivo magnético para o painel |

---

## 2. A caixa

Impressa, paramétrica em OpenSCAD. **A fonte e as decisões de geometria estão
fora deste repositório**, com a cadeia de geração; os **STLs prontos** estão em
[`caixa/`](caixa/), com o que é preciso saber para imprimir.

| | |
| :--- | :--- |
| Externo | 130 × 130 × 67 mm |
| Parede e piso | 3 mm |
| Fechamento | batente interno, tampa desce por cima, **atrito — sem parafuso** |
| Folga do encaixe | 0,4 mm por lado |

### 🔴 O material é decisão térmica, não estética

O painel mediu **92 °C**. Isso elimina quase tudo:

| Material | Amolece a | No seu painel |
| :--- | :--- | :--- |
| PLA | ~60 °C | ❌ deforma, não é "talvez" |
| PETG | ~80 °C | ❌ escorre sob peso próprio |
| ABS | ~105 °C | 🟡 serve, mas amarela e fragiliza com UV |
| **ASA** | ~105 °C | ✅ mesma temperatura, com a química de UV resolvida |

⚠️ **Nada com carga de fibra de carbono.** É condutivo o bastante para atrapalhar
a antena, e a tampa é justamente por onde o patch enxerga o céu.

⚠️ **ASA exige câmara fechada.** Empena sem ela e libera estireno. Numa
impressora aberta o material disponível cai para PETG, que os 92 °C reprovam.

### A margem do ASA é apertada, e isso é consciente

105 °C de Tg contra 92 °C medidos são **13 °C**. Num dia pior a margem some.
A alternativa com folga de verdade seria nylon PA12 por MJF, com deflexão perto
de 175 °C — descartada por custo, mas é para onde ir se o ASA ceder.

**Pendência M-08** decide: um dia de registro térmico no painel, com o sensor
que já existe dentro do RP2350.

---

## 3. A placa

PCB fabricada de **120 × 120 mm**, apoiada em **quatro pilares de 5 mm** que
nascem do piso da caixa, nos furos de M3 das quinas.

Isso substitui todo o capítulo de chassi de placa perfurada da v1 — e com ele
somem os problemas que aquele capítulo existia para resolver: pernas cortadas
no lado de baixo, ilhas de cobre soltas, colagem com VHB sobre pontos de solda.

> ✅ **O ganho que não é óbvio:** com placa fabricada, a fiação deixou de ser
> transcrita à mão. Ela sai do `netlist.py`, e o `pcb.md` registra a verificação
> que compara a netlist do KiCad com a fonte, nó a nó.

### Os módulos sobem em barra de pinos

Decisão da placa, registrada no `pcb.md`: a PCB é uma **carrier board**, e Pico,
GPS, display, leitor e conversor plugam nela. O soquete levanta cada módulo
**8,1 mm** acima da placa.

Módulo com defeito troca puxando. E o U.FL do GPS nunca precisa ser tocado.

---

## 4. O GPS e a antena

Os dois na placa, vizinhos, na extremidade oposta ao conversor.

### 4.1 A antena é colada, e a área é proibida

Patch cerâmico de **25 × 25 mm**, colado com **fita espuma dupla face**.

A área sob ela é zona de exclusão no projeto da placa: **plano de terra sólido,
sem trilha atravessando**. E **nada por cima** — o patch enxerga o céu pela
tampa, que é plástica e portanto transparente a 1,5 GHz.

O retângulo tracejado na serigrafia marca o lugar, com os dizeres `ANTENA GPS` e
`colar aqui - nao usar`. A zona existe para a verificação de projeto; a
serigrafia existe para quem monta.

⚠️ **A fita precisa ser acrílica estruturada (tipo VHB), especificada para
90–120 °C.** Fita espuma comum não descola — ela **escorre devagar**, e a peça
desce ao longo de semanas.

⚠️ A espuma afasta a antena do plano de terra em 1 a 2 mm, o que altera o
diagrama de radiação. Não é fatal; é coisa a observar na primeira volta real,
comparando o número de satélites com o de hoje.

### 4.2 Manuseio do U.FL — continua valendo

O conector aguenta cerca de **30 ciclos** de encaixe (datasheet Hirose). A fêmea
no módulo mede ~2 mm.

- **Encaixar uma vez, na montagem.** Com módulo e antena na mesma placa, não há
  motivo para desconectar na manutenção.
- Para desencaixar, **puxar reto para cima**, nunca de lado nem pelo cabo.
  Ferramenta de extração, se houver, ou unha sob a saia do conector.
- Ao encaixar, **alinhar e pressionar reto**, com o estalo. Encaixe torto
  deforma a saia e mata o conector de uma vez.

---

## 5. A face frontal

Da esquerda para a direita: **encoder · display · buzzer**.

| Peça | Medida | Recorte na caixa |
| :--- | :--- | :--- |
| Display 2,4" | módulo 70 × 46,7 × 5,7 | **área visível 60,8 × 44** |
| Encoder KY-040 | corpo 19,3 × 26,5 × 9,6 | furo da bucha roscada |
| Buzzer SFM-27 | ⌀22,4, orelhas a 29,6 | 2 furos de ⌀2,6 + leque de furos de som |

**O recorte do display é a área visível, não a placa do módulo.** A moldura
preta sobra por trás e é ela que encosta na parede — é o que esconde a
tolerância do recorte.

Abaixo do display há **14 mm** de material, com o nome `Coruja GPS` em relevo, e
a silhueta da coruja na coluna do encoder.

### ⚠️ O display avança para dentro

São 70 × 46,7 mm pendurados atrás da parede frontal, invadindo cerca de 6 mm.
A borda frontal da placa, nessa profundidade, tem de ficar livre de peça alta —
e está: nos 10 mm frontais só há os dois furos de fixação.

A folga entre o topo da placa e a base do display é de **0,4 mm**. Foi para
ganhar margem real que a borda subiu de 10 para 14 mm.

### O eixo do encoder

20 mm livres acima do corpo. Descontando 3 mm de parede e ~2 mm de arruela e
porca, restam **15 mm** para o knob — folga confortável.

⚠️ O **diâmetro do canhão roscado** ainda não foi medido. Os 6,0 mm lidos por
dentro da porca **não decidem**: garra interna em porca dá o diâmetro menor da
rosca. Numa M7×0,75, típica do KY-040, o menor fica perto de 6,1 — ou seja, 6,0
medidos são compatíveis com bucha de 7. Ver **M-12**.

---

## 6. A traseira, e o LED

**Cartão e USB faceados**, cada um com seu vão. Isso fixa a orientação de dois
módulos na placa: a boca do cartão e o conector USB apontam para fora.

O **LED** sai pela face de cima, furo único e centralizado.

> 📌 Escolheu-se a traseira para os dois vãos porque a caixa é presa ao painel
> por **ímã** e sai inteira quando preciso atualizar o firmware. O acesso ao
> cabo deixou de ser operação frequente.

---

## 7. Fixação ao painel

**Adesivo magnético** no fundo. Para atualizar o firmware, desliga-se a
alimentação e leva-se o conjunto.

### ⚠️ Duas perdas que se somam a 92 °C

- **A retenção magnética cai com a temperatura.** Ferrite flexível perde fluxo
  de forma sensível entre 80 e 100 °C — não some, enfraquece.
- **O adesivo escorre**, pelo mesmo mecanismo da fita espuma.

Um aparelho que se solta do painel em movimento é **problema de segurança**, não
de acabamento.

> **Conferir com a caixa quente.** Deixar o conjunto montado num dia de sol e
> tentar deslocá-lo. Todo adesivo parece bom frio.

---

## 8. Isolamento elétrico

| Onde | Como | Por quê |
| :--- | :--- | :--- |
| Sob o módulo GPS | **Kapton** na face de baixo do módulo | isola o módulo do que passa na placa |
| Entre a antena e a PCB | a própria fita espuma | ela já é dielétrica |
| Fios do Q1 e do chicote | **Kapton**, e ancorados contra vibração | o transistor fica preso aos fios, não soldado em pilar |

> ❌ **Nunca colar placa direto com VHB.** A fita tem 1 a 2 mm e as pernas de
> solda são mais altas: a placa ficaria apoiada nas pontas de solda, que é o
> pior apoio possível. Com a PCB fabricada em pilares, o problema não se
> apresenta — mas a regra fica, porque o reflexo de colar volta sempre.

---

## 9. Adesivos: o que usar e o que não usar

Esta seção veio inteira da v1. A química não mudou com a arquitetura.

### 9.1 ❌ Silicone RTV automotivo

**Não usar em contato com a eletrônica.** A maioria dos RTV baratos, inclusive
os automotivos de vedação, é de **cura acetoxi**: libera **ácido acético** ao
curar. O vapor condensa nos terminais e nas juntas de solda e corrói cobre,
estanho e latão — chega a descolar a solda do fio. É falha retardada: funciona
bem, e meses depois aparece verdete nas ilhas e um intermitente que se caça no
software.

Agrava-se porque silicone cura **por umidade do ar, de fora para dentro**: um
cordão grosso sob um módulo fica muito tempo sem curar no meio, mantendo o ácido
preso encostado na placa.

**Teste:** apertar um pouco num papel e cheirar. **Cheiro forte de vinagre =
acetoxi.** Cura neutra (alcoxi ou oxima) solta álcool e tem cheiro fraco. Na
embalagem, procurar "cura neutra", "não corrosivo" ou "para eletrônica" — *não*
"automotivo" nem "alta temperatura", que nada dizem sobre a cura.

"Alta temperatura" é, aliás, a especificação errada: Pico, display, GPS e cartão
somam cerca de 2 W. Pagar por 300 °C não compra nada e costuma vir justo com a
química corrosiva, porque é silicone de junta de motor.

Uso aceitável: **na caixa, não na eletrônica** — vedar a tampa contra pó, ou
fazer o passa-cabo. E curar com a caixa vazia antes de pôr a placa.

### 9.2 ❌ Cola quente

O reflexo natural, e errado aqui. EVA amolece entre 60 e 80 °C, e painel ao sol
passa bem disso. A montagem desaba num estacionamento à tarde.

Quem esquenta não é o circuito — é o **carro**. Essa é a temperatura que
seleciona o adesivo.

### 9.3 ⚠️ Se um dia houver blindagem, não usar alumínio

- A maioria das fitas de alumínio tem **adesivo acrílico isolante**. Tiras
  sobrepostas **não** se conectam, e o resultado são ilhas isoladas em vez de um
  plano. É o erro prático mais comum do assunto.
- **Alumínio não solda** com estanho e fluxo comuns — o óxido não deixa.
  "Aterrada" exigiria conexão mecânica, parafuso com arruela mordendo a folha.

**Usar fita de cobre com adesivo condutivo:** solda normalmente, as sobreposições
conduzem, e o fio de terra se prende com um ponto de solda.

E dois cuidados que valem para qualquer folha:

- **Aterrar curto e em vários pontos**, no terra do **próprio módulo GPS**.
  Blindagem aterrada por um ponto só e com fio longo pode ser **pior que
  blindagem nenhuma**: a indutância do fio faz com que aquilo não seja terra na
  frequência do ruído, e a folha passa a ser antena ressonante que acopla ruído
  para dentro. Se o fio não puder ser curto, é melhor deixar a folha flutuando.
- **Isolar a face externa da folha.** Um plano de terra nu virado para as placas
  e a fiação é curto esperando a hora. A ordem é folha, depois isolante, e o
  isolante é que olha para o circuito.

> 📌 Com a PCB fabricada, a blindagem ficou **menos provável de ser necessária**:
> a antena ganhou plano de terra contínuo embaixo e está na extremidade oposta ao
> conversor chaveado. Continua contingente à medição — ver **M-06**.

### 9.4 ✅ Resumo

| Uso | Escolha |
| :--- | :--- |
| Antena na PCB | **fita acrílica estruturada**, 90–120 °C |
| Caixa no painel | **adesivo magnético**, conferido quente |
| Isolamento sob o módulo GPS | **Kapton** |
| Vedação da tampa / passa-cabo | silicone de **cura neutra**, curado com a caixa vazia |
| Blindagem, se necessária | **fita de cobre** com adesivo condutivo |

---

## 10. O que não pode ser coberto, em nenhuma hipótese

| Peça | Consequência de cobrir |
| :--- | :--- |
| **Furos de som do buzzer** | Abafa o volume. Levaria a procurar erro no PWM onde não há. |
| **Flex e vidro do display** | Ponto de fadiga no flex. Silicone na borda do bezel é aceitável; no flex, não. |
| **A área da tampa acima do patch** | Bloqueia o céu e inutiliza o GPS. |
| **A zona proibida da antena, na placa** | Trilha ou cobre ali degrada a recepção, e o sintoma — fix demorado ou instável — ninguém atribui ao desenho da placa. |
| Rasgo do cartão, abertura do USB, eixo do encoder | Por motivo óbvio. |

---

## 11. Pendências

Numeração própria (**M-NN**), para não colidir com os **R-NN** de
`revisao_tecnica.md`.

> 📌 **M-01 a M-05 da v1 foram encerradas sem resposta.** Todas mediam a Patola
> — área entre torres, altura das torres, parafuso que acompanha a caixa,
> orientação dos eixos. A caixa saiu do projeto e as perguntas com ela.

| Item | O que falta | Trava o quê |
| :--- | :--- | :--- |
| **M-06** | A/B de C/N0 pela GSV, USB × step-down | Decide se há blindagem. Menos provável que na v1, mas não descartada. |
| **M-07** | Para-brisa do veículo é atérmico? | Se for, muda o regime térmico inteiro. |
| **M-08** | **Campanha térmica:** um dia parado ao sol, na posição real, registrando a cada minuto | Fecha o **R-65** e decide se o ASA aguenta. O RP2350 tem sensor **no próprio die**, no canal 4 do ADC, e o firmware não usa o ADC para nada — há um termômetro ocioso dentro do aparelho e um `LoggerCartao` que já grava no cartão. ⚠️ O sensor lê a pastilha, que corre acima do ambiente por autoaquecimento: caracterizar o desvio uma vez em ambiente conhecido. |
| **M-09** | 🆕 **Folga do encaixe da tampa** | Imprimir só a tampa com 0,3 / 0,4 / 0,5 e escolher pelo tato. Meia hora cada. |
| **M-10** | 🆕 **Empenamento do ASA** numa peça de 130 mm | Apoiar numa superfície plana e ver se balança nos cantos. Não aparece em amostra pequena. |
| **M-11** | 🆕 **Retenção do ímã com a caixa quente** | Segurança. Testar num dia de sol, não frio. |
| **M-12** | 🆕 **Diâmetro do canhão roscado do encoder** | Única cota da caixa sem margem para menos. A porca não responde — ver §5. |
| **M-13** | 🆕 Furo do LED, rasgo do cartão, abertura do USB | Estimativas no modelo. As duas últimas foram alargadas de propósito; a do LED não. |
| **M-14** | 🆕 **Conector GX12-2: três cotas**, com o conector em mãos | Trava a impressão do corpo. Conectores comprados em 08/10/2026, previstos para sábado. Ver abaixo. |
| **R-13** | Corrente agregada e temperatura do LDO do display | Aberto em `revisao_tecnica.md`; a caixa fechada torna a medição mais relevante, não menos. |

> ⚠️ **M-09, M-10, M-12, M-13 e M-14** são impressora e paquímetro, e saem rápido
> assim que a impressora chegar. **M-06, M-07, M-08 e M-11** exigem o veículo — e
> o M-08 exige um dia de sol, então vale deixar o registro pronto antes do
> próximo verão.

### M-14 — as três cotas do GX12-2

As duas primeiras já têm valor no modelo, **generoso de propósito**: errar para
mais custa folga, errar para menos arruína uma peça de 130 × 130 × 67 mm depois
de impressa.

| Medir | Define | Valor atual |
| :--- | :--- | ---: |
| ⌀ do corpo roscado | `GX12_FURO` | 12,5 mm |
| ⌀ da porca, de ponta a ponta | `GX12_VAO_PORCA` — a zona que **permanece** com 3 mm de parede, para a porca assentar | 18,0 mm |
| **comprimento da rosca** | **se 3 mm de parede fecham** | — |

🔴 **A terceira não tem valor no modelo, e é a que pode reprovar o desenho.** A
espessura máxima de painel é o comprimento roscado menos a altura da porca. Se
sobrar pouco, os 3 mm não fecham — e aí não adianta medir as outras duas.

É por isso que o reforço do furo é um **anel** e não um disco: ele deixa a
parede com a espessura nominal sob a porca, e engrossa só o material em volta.
Quem limita a espessura aqui não é a impressão, é a peça comprada.

> As cotas moram em `caixa/coruja_caixa.scad`, marcadas `(MEDIR)`. Depois de
> medir, regerar com `caixa/gera_stl.sh` — ele verifica a malha e recusa a peça
> se algum vão da traseira ficar obstruído.

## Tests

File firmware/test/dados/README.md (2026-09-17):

# Dados de teste

## `fixture_igo8.txt` — 100 pontos sintéticos

Arquivo iGO8 puro, sem comentário — o `converte.py` rejeita comentário de
propósito, porque o formato não tem, e não se dobra um parser de formato para
conveniência de teste. Daí esta explicação viver aqui e não dentro do arquivo.

### Como foi feito

As combinações de `TYPE`, `SPEED`, `DirType` e `Direction` foram **amostradas
de uma base iGO8 real**, com semente fixa, para que os testes exercitem as
combinações que de fato ocorrem em vez de um produto cartesiano inventado.

As **coordenadas foram substituídas** por pontos no Atlântico Sul aberto:

```
latitude  -32,0 a -22,0
longitude -40,0 a -35,0
```

Essa caixa é ao sul da cadeia Vitória-Trindade, a leste da bacia de Campos, e
longe de Abrolhos, Rocas e Fernando de Noronha — não há terra emersa nela. E
fica **dentro** da caixa que o `converte.py` valida (`lat -34 a 6`,
`lon -75 a -33`), o que é obrigatório: a primeira tentativa usou longitude
`-25 a -18` e o conversor rejeitou os 100 pontos, corretamente.

**Nenhum ponto deste arquivo é um local real de fiscalização.** Ele não serve
para navegar, e não revela nada sobre a origem dos dados.

### O que ele exercita de propósito

| Caso | Presente |
| :--- | :--- |
| As 11 combinações `(TYPE, DirType)` que existem na origem | ✅ |
| Os quatro `TYPE` | 43 · 20 · 17 · 20 |
| Os três `DirType` | 19 · 62 · 19 |
| Todos os limites da base | `0 30 40 50 60 70 80 90 100 110 120` |
| Limite acima de 100 km/h — outro ramo do `V_infra` | 7 pontos |
| Limite zero em câmera de semáforo | 14 pontos |
| Câmera de semáforo **com** limite — a inconsistência dos 22 | 3 pontos |
| Rumos cruzando 0/360 — o wraparound do R-04 | `359 1 358 2` |
| Pares de latitude idêntica — desempate da busca binária | 3 pares |
| Par a ~40 m de distância — vizinhança apertada | 1 par |

### Como os testes a usam

O CMake roda o `converte.py` sobre ela em tempo de build e gera o
`fixture.bin`, que os testes carregam. Isso faz a suíte exercitar **a cadeia
inteira** — conversor em Python e carregador em C++ — e é exatamente a classe
de divergência que apareceu na primeira execução, quando o carregador havia
assumido um layout de cabeçalho diferente do que o conversor escreve.

O binário **não** é versionado: é derivado.

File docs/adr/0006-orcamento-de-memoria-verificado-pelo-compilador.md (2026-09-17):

# 0006 — O orçamento de memória é verificado pelo compilador e pelo linker

*Data: 2026-09-17 · Estado: aceita*

## Contexto

O orçamento de memória do `formato_dados.md` §1 é a restrição central do
projeto: 520 KiB de SRAM, com a base de radares e o framebuffer disputando a
maior parte. Até aqui ele era **estimado no papel**, e a primeira compilação
para ARM mostrou que duas coisas estavam erradas — nenhuma delas visível nos 92
testes de host, porque nenhuma é um erro de lógica.

**Primeiro: `sizeof(Ponto)` era 16 bytes, não 12.** O registro em arquivo tem
12 bytes, e eu havia expandido o rumo para `uint16_t` em graus por conveniência
de leitura. O padding de alinhamento empurrou a struct para 16. Consequência: a
base real passaria de 214,4 para **285,8 KiB**, e o teto de 40.000 pontos daria
625 KiB — **mais que a SRAM inteira**. O "teto de proteção de memória" não
protegia nada.

**Segundo: o array estático estava dimensionado pelo teto do formato.** Reservar
40.000 pontos custa 468,75 KiB e deixa **48,3 KiB livres** de 520 — medido no
linker, não estimado. Não sobra para lwIP, stacks e as bandas do display.

## Decisão

**Fechar o `Ponto` em 12 bytes**, mantendo o rumo quantizado como no arquivo,
com um acessor `rumo_graus()` que multiplica por 2. A quantização é irrelevante
para o RF02.3, cujo filtro de sentido tem tolerância de dezenas de graus.

**Separar duas constantes que eram uma:**

| Constante | Valor | Significa |
| :--- | ---: | :--- |
| `kTetoPontos` | 40.000 | teto do **formato**: acima disso o arquivo é absurdo |
| `kCapacidadeFirmware` | 24.000 | o que **esta placa** reserva em `.bss` |

**E deixar o compilador guardar os invariantes**, em vez da disciplina de quem
lê o código:

```cpp
static_assert(sizeof(Ponto) == kTamRegistro, ...);
static_assert(kCapacidadeFirmware * sizeof(Ponto) < 355u * 1024u, ...);
```

## Consequências

* Medido no linker depois da correção: **284,2 KiB de SRAM, 235,8 KiB livres**,
  e 66,6 KiB de flash de 4096. O orçamento do §1 deixa 355 KiB para a base;
  24.000 pontos ocupam 281,2 KiB e dão **31% de folga** sobre os 18.294 de hoje.
* Um arquivo entre 24.000 e 40.000 pontos é **válido pelo formato e recusado
  por este firmware**, com `ExcedeuCapacidade`. A distinção é correta e já
  existia na assinatura do carregador, que sempre recebeu a capacidade como
  parâmetro: o arquivo não está corrompido, está grande demais para esta placa.
* Reordenar campos do `Ponto` ou trocar um tipo por um maior agora **quebra o
  build**, não o orçamento em silêncio. Era o único jeito de tornar a
  restrição durável — um comentário pedindo cuidado não sobrevive a um
  refactor bem-intencionado que "melhora a legibilidade" do rumo.
* Se a base crescer além de ~24.000 pontos, a saída não é subir a constante sem
  pensar: é o empacotamento em 8 bytes da §3.3, que libera 71 KiB.

## Nota sobre como o erro escapou

O array só era referenciado por `sizeof`, e `sizeof` não exige que o objeto
exista — o linker eliminou `g_pontos` inteiro, e o primeiro relatório de
memória dizia **2,7 KiB de `.bss` e 517 KiB livres**, número que era ficção.
O `main.cpp` agora chama `carrega_base()` de verdade, o que referencia o array
e, de passagem, exercita o caminho de Falha de Dados do RF07.

**Medir uma reserva que o linker removeu não mede nada.**

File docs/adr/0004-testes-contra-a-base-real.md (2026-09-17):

# 0004 — Fixture sintética versionada, em vez de pular testes

*Data: 2026-09-17 · Estado: aceita*

## Contexto

O carregador do `radares.bin` merece ser exercitado contra dados realistas, não
só contra arquivos sintéticos de três registros: é o que pega divergência entre
o conversor e o firmware. E pegou — o primeiro teste contra uma base real
revelou que a implementação havia **assumido** o layout do cabeçalho em vez de
ler a especificação, trocando `versao` u16 por u8. Nenhum teste de campo
corrompido teria encontrado isso, porque todos usavam o mesmo cabeçalho errado.

Mas uma base real não pode ser versionada: é dado de terceiro, e o repositório
público não deve dizer nada sobre a origem dos dados.

A primeira versão deste ADR resolvia isso pulando os testes quando o arquivo
não existia. Funcionava, mas com um defeito sério: num clone limpo — que é o
caso normal — **a cobertura mais valiosa simplesmente não rodava**, e a suíte
ficava verde anunciando sucesso.

## Decisão

Versionar uma **fixture sintética de 100 pontos** em formato iGO8 de texto,
`firmware/test/dados/fixture_igo8.txt`, e convertê-la em tempo de build com o
próprio `converte.py` do projeto.

As combinações de `TYPE`, `SPEED`, `DirType` e `Direction` foram amostradas de
uma base real com semente fixa, então exercitam o que de fato ocorre. As
**coordenadas foram trocadas** por pontos no Atlântico Sul aberto, numa caixa
sem terra emersa e dentro da região que o conversor valida. Nenhum ponto é um
local real de fiscalização.

A base completa continua aceita, agora como **extra opcional** via
`-DCORUJA_BASE_REAL`, para exercitar a carga em escala.

## Consequências

* A suíte roda **completa** num clone limpo, sem dado de terceiro. Um pulado
  agora significa "você não configurou o extra", não "a cobertura principal
  não rodou".
* A conversão em tempo de build faz a suíte exercitar **a cadeia inteira**,
  Python e C++, e não só o lado C++. Divergência de layout entre os dois passa
  a ser erro de build, não surpresa de campo.
* Introduz dependência de `python3` para compilar os testes. Aceito: o
  conversor já é parte do projeto e o CMake falha com mensagem clara.
* A fixture é `igO8` **puro, sem comentário**. O `converte.py` rejeita
  comentário porque o formato não tem, e não se dobra um parser de formato para
  conveniência de teste — a explicação vive em `test/dados/README.md`.
* Os números da fixture estão fixados nos testes (43/20/17/20 por tipo, 14 sem
  limite, 3 câmeras com limite). Regenerar a fixture quebra esses testes de
  propósito: é a forma de notar que os dados de apoio mudaram.

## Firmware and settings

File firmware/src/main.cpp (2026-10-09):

// Ponto de entrada do **produto**.
//
// É a primeira build em que tudo que foi construído roda junto: GPS, base no
// cartão, zonamento, LED, buzzer, tela, menu de ajustes e atualização OTA.
// Até aqui cada peça tinha sua bancada; aqui elas se encontram.
//
// **Esta é a camada de composição, e ela não decide nada.** Toda a lógica
// está em classes testadas no host contra dublês — `Aplicacao`,
// `PilotoAlerta`, `MaquinaZona`, `MenuAjustes`, `AtualizadorOta` — e o que
// existe neste arquivo é a fiação: quem é construído com quem, em que ordem,
// e o que fazer quando o OTA termina. É a regra do `docs/adr/0001`.
//
// O que o usuário faz:
//
//   girar, andando   ajusta o brilho (a faixa superior mostra "BRILHO n%")
//   girar, parado    abre o menu de ajustes (RF05.1)
//   clicar, parado   atualiza a base pela rede
//   clicar, andando  recusa e avisa: "PARE PARA ATUALIZAR"
//
// **O GPS pode não estar montado**, e isso não é caso especial: sem fix o
// aparelho mostra "SEM SINAL" e suspende os alertas, que é exatamente o que
// ele deve fazer num túnel. O firmware inteiro roda assim.

#include <cstdio>
#include <initializer_list>

#include <pico/rand.h>
#include <pico/stdlib.h>

#include "app/Aplicacao.h"
#include "app/EsperaDispensa.h"
#include "VersaoBuild.h"
#include "app/OtaNaTela.h"
#include "app/EmprestimoDaBase.h"
#include "app/RemessaNaTela.h"
#include "app/PilotoAlerta.h"
#include "armazenamento/CartaoSd.h"
#include "buzzer/BuzzerGpio.h"
#include "display/Brilho.h"
#include "display/PainelSt7789.h"
#include "display/RetroiluminacaoPwm.h"
#include "display/VisorSt7789.h"
#include "encoder/EncoderKy040.h"
#include "gps/ConfiguradorGps.h"
#include "gps/LeitorGps.h"
#include "gps/UartPico.h"
#include "led/LedRgbAnodoComum.h"
#include "log/CarimboExecucao.h"
#include "log/IdExecucao.h"
#include "log/LoggerCartao.h"
#include "log/LoggerConsole.h"
#include "nucleo/BaseRadares.h"
#include "nucleo/CarimboDeLog.h"
#include "nucleo/CarregadorFluxo.h"
#include "nucleo/LeitorConfig.h"
#include "placa/PausaReal.h"
#include "rede/AtualizadorOta.h"
#include "nucleo/SincronizadorHora.h"
#include "placa/MedidorPilha.h"
#include "placa/Termometro.h"
#include "placa/RelogioAon.h"
#include "rede/ClienteSntp.h"
#include "rede/ClienteTls.h"
#include "rede/PlataformaMbedtls.h"
#include "rede/RemessaDados.h"
#include "rede/RedeWifi.h"

namespace {

/// A base inteira em `.bss`. Não há heap no caminho crítico, e o vetor é 83%
/// da RAM usada — medido, não estimado (`formato_dados.md` §1).
coruja::Ponto g_pontos[coruja::kCapacidadeFirmware];

/// Quanto do `coruja.cfg` cabe de uma vez.
///
/// **É o mesmo `kMaxTextoCfg` do gravador, e isso não é coincidência**: um
/// arquivo que o menu consegue reescrever tem de ser um arquivo que o boot
/// consegue ler. Eram dois números diferentes — 2048 aqui, 8192 lá —, e o
/// gerador foi passando dos 2048 sem que nada reclamasse: cada funcionalidade
/// nova acrescentava um bloco de comentário.
///
/// O sintoma, em 2026-10-06: `coruja.cfg: arquivo maior que o buffer`, o
/// aparelho sem nome na tela de informação e o OTA recusando com "sem
/// configuração utilizável" — com um arquivo que lia perfeitamente em
/// qualquer outra ferramenta.
///
/// Os comentários saíram do arquivo que vai ao cartão (ficaram no
/// `coruja.cfg.exemplo`), e os dois lados passaram a usar a MESMA constante.
constexpr std::size_t kTamBufferConfig = coruja::kMaxTextoCfg;
char g_texto_config[kTamBufferConfig];

/// Buffer da gravação cirúrgica do `coruja.cfg`. Vem de fora do
/// `GravadorConfig` de propósito: são 8 KiB, e em `.bss` de quem compõe eles
/// aparecem no mapa de memória; escondidos lá dentro, não.
char g_trabalho_cfg[coruja::kMaxTextoCfg];

constexpr const char* kArquivoLog = "coruja.log";
/// Para onde o log vai DURANTE a remessa. Não casa com o `nome_enviavel`, de
/// propósito: ele não sobe, não é apagado, e por isso sobrevive no cartão
/// para ser lido depois de um envio que falhou.
constexpr const char* kArquivoLogRemessa = "remessa.log";

void ao_ler_pedaco_da_base(void* contexto, const std::uint8_t* bytes,
                           std::size_t tamanho) {
    static_cast<coruja::CarregadorFluxo*>(contexto)->alimenta(bytes, tamanho);
}

/// Carrega a base do cartão, com o recuo do RF05.2 passo 6.
///
/// Tenta o `radares.bin`; se ele não validar, cai para o `radares.bak`. Sem
/// esse recuo, uma atualização que passasse na verificação e ainda assim
/// produzisse arquivo ruim deixaria o aparelho sem base **e sem caminho de
/// volta**, e o motorista descobriria dirigindo.
/// Pontos carregados e o cabeçalho de onde vieram.
///
/// O cabeçalho sai junto porque a tela de informação mostra a **data da
/// base**, e ela vem de lá — não do momento do download. O aparelho pode
/// ter baixado hoje uma base de três meses atrás, e é a idade dos dados que
/// diz se vale a pena atualizar.
struct BaseCarregada {
    std::size_t          pontos = 0;
    coruja::CabecalhoBase cabecalho{};
};

BaseCarregada carrega_base(coruja::CartaoSd& cartao, coruja::Logger& log) {
    coruja::CarregadorFluxo carregador(g_pontos, coruja::kCapacidadeFirmware);
    char msg[128];

    for (const char* nome : {coruja::kArquivoBase, coruja::kArquivoBak}) {
        carregador.reinicia();
        std::size_t lidos = 0;
        const auto leitura = cartao.le_em_fluxo(nome, ao_ler_pedaco_da_base,
                                                &carregador, &lidos, log);
        if (leitura != coruja::ErroCartao::Nenhum) {
            std::snprintf(msg, sizeof msg, "'%s': %s", nome, descreve(leitura));
            log.info("base", msg);
            continue;
        }
        if (carregador.conclui() != coruja::ErroBase::Nenhum) {
            std::snprintf(msg, sizeof msg, "'%s' RECUSADA", nome);
            log.error("base", msg);
            continue;
        }
        const auto& cab = carregador.cabecalho();
        if (cab.tem_data()) {
            std::snprintf(msg, sizeof msg, "%u pontos de '%s', base de %02u/%02u/%04u",
                          static_cast<unsigned>(carregador.pontos()), nome,
                          static_cast<unsigned>(cab.dia),
                          static_cast<unsigned>(cab.mes),
                          static_cast<unsigned>(cab.ano));
        } else {
            std::snprintf(msg, sizeof msg, "%u pontos de '%s' (formato antigo, sem data)",
                          static_cast<unsigned>(carregador.pontos()), nome);
        }
        log.info("base", msg);
        if (nome == coruja::kArquivoBak) {
            log.warning("base", "operando pela RESERVA: atualize quando puder");
        }
        return {carregador.pontos(), cab};
    }
    // RF07: sem base o aparelho opera, e precisa deixar isso evidente. Quem
    // avisa é a tela, com "BASE INDISPONIVEL".
    log.error("base", "NENHUMA base: nem a vigente nem a reserva");
    return {};
}

bool carrega_configuracao(coruja::CartaoSd& cartao,
                          coruja::Configuracao* destino,
                          coruja::Logger& log) {
    std::size_t lidos = 0;
    const auto erro = cartao.le_arquivo("coruja.cfg", g_texto_config,
                                        kTamBufferConfig, &lidos, log);
    if (erro != coruja::ErroCartao::Nenhum) {
        char msg[96];
        std::snprintf(msg, sizeof msg, "coruja.cfg: %s", descreve(erro));
        log.error("config", msg);
        return false;
    }
    *destino = coruja::le_config(g_texto_config, lidos, &log).config;
    return destino->ota_possivel();
}

/// O que a `Aplicacao` manda fazer e não sabe como (regra 2).
///
/// Vive aqui, na composição, porque as duas ações precisam de coisas que a
/// `Aplicacao` não tem e não deveria ter: rede, cartão e o orquestrador do
/// Reconstroi a base no vetor depois de ele ter sido emprestado ao TLS.
///
/// E o `carrega_base` de sempre, so que atras da interface que o
/// `EmprestimoDaBase` exige -- e e o que torna impossivel devolver o ponteiro
/// sem recarregar.
class RecarregadorDoCartao final : public coruja::RecarregadorBase {
public:
    explicit RecarregadorDoCartao(coruja::CartaoSd& cartao)
        : cartao_(cartao) {}

    std::size_t recarrega(coruja::Logger& log) override {
        ultima_ = carrega_base(cartao_, log);
        return ultima_.pontos;
    }

    const BaseCarregada& ultima() const { return ultima_; }

private:
    coruja::CartaoSd& cartao_;
    BaseCarregada     ultima_;
};

/// Acerta o relogio assim que a rede sobe, antes do primeiro pedido.
///
/// ⚠️ **Isto ja foi feito no lugar errado**, no construtor da
/// `SessaoDeRede`, antes de o orquestrador conectar. O `cyw43_arch_init()`
/// so acontece dentro do `RedeWifi::conecta()`, entao o cliente NTP
/// falava com a pilha de rede e com o radio antes de os dois existirem --
/// e o aparelho travava por completo no clique de atualizar: tela
/// congelada, encoder morto, sem uma linha de log.
class RelogioAntesDoTls final : public coruja::PreparoDeSessao {
public:
    RelogioAntesDoTls(coruja::SincronizadorHora& s, coruja::LeitorGps& gps)
        : sincronizador_(s), gps_(gps) {}

    /// De onde pedir a hora. Vem da configuracao RELIDA a cada acao, e
    /// nao da do boot: trocar o cartao passa a valer sem reiniciar
    /// (RNF03), e isso tem de valer para esta chave tambem.
    void define_servidor(const char* servidor) {
        std::snprintf(servidor_, sizeof servidor_, "%s",
                      servidor != nullptr ? servidor : "");
    }

    void apos_conectar(coruja::Logger& log) override {
        sincronizador_.sincroniza(servidor_, gps_.telemetria(), log);
        // Zero quando ninguem conseguiu: o mbedTLS enxerga 1970 e recusa
        // todo certificado por "ainda nao vale". E o lado seguro de nao
        // saber a data, e o log do sincronizador ja disse o porque.
        coruja::define_hora_utc(sincronizador_.hora_utc());
    }

private:
    coruja::SincronizadorHora& sincronizador_;
    coruja::LeitorGps&         gps_;
    char servidor_[coruja::kMaxUrl + 1] = {};
};
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
int main() {
    stdio_init_all();
    sleep_ms(1500);

    // O identificador desta execucao, sorteado ANTES do primeiro log: assim
    // nenhuma linha fica orfa. Vem do TRNG do RP2350, pelo `pico_rand` -- a
    // mesma fonte da entropia do TLS.
    //
    // Ele separa as ligacoes dentro do `coruja.log`, que acumula entre elas.
    // Sem isto, so da para inferir a fronteira pelo que aparece no boot.
    coruja::define_id_execucao(get_rand_64());

    // E a HORA de cada linha, que ate agora nao existia.
    //
    // Sem ela, qualquer ferramenta de analise carimba a linha com o instante
    // em que INGERIU o arquivo -- dias depois, no caso de um log que sobe por
    // remessa. Enquanto o NTP nao acerta o relogio sai o tempo desde o boot,
    // com `+`, que nao se confunde com uma data (ver `formata_carimbo`).
    coruja::define_fonte_de_carimbo([]() -> const char* {
        static char carimbo[coruja::kTamCarimbo];
        coruja::formata_carimbo(coruja::hora_utc(),
                                to_ms_since_boot(get_absolute_time()),
                                carimbo, sizeof carimbo);
        return carimbo;
    });

    // Pinta a pilha livre ANTES de qualquer trabalho. O handshake do mbedTLS
    // e o que mais consome aqui, e o tamanho reservado (16 KiB) foi escolhido
    // com folga porque ninguem o mediu -- isto e o que troca o palpite por
    // um numero.
    coruja::pinta_pilha();

    coruja::LoggerConsole console(nullptr, coruja::Nivel::Info);
    coruja::CartaoSd      cartao;
    coruja::LoggerCartao  log(console, cartao, kArquivoLog);

    // A tela primeiro, antes de qualquer coisa que possa falhar: é o único
    // canal capaz de contar o que deu errado. Tela preta durante o boot
    // parece aparelho morto.
    coruja::RetroiluminacaoPwm luz;
    coruja::PainelSt7789       painel;
    painel.inicia();
    coruja::VisorSt7789 visor{painel};

    coruja::LedRgbAnodoComum led;
    coruja::BuzzerGpio       buzzer;
    coruja::EncoderKy040     encoder;
    coruja::Brilho           brilho;
    coruja::PausaReal        pausa;
    coruja::UartPico         uart;
    coruja::LeitorGps        gps(uart);
    coruja::RedeWifi         rede;
    coruja::ClienteTls       http;
    coruja::ClienteSntp      ntp;
    coruja::RelogioAon       relogio;

    log.info("boot", "coruja gps");
    cartao.inicia(log);

    coruja::Configuracao config;
    carrega_configuracao(cartao, &config, log);
    log.define_nivel_minimo(config.nivel_log);
    log.grava_no_cartao(config.log_para_cartao);

    // **Qual firmware escreveu este log.** Sem esta linha, um log recolhido
    // do cartão não diz de que binário veio, e em 09/10/2026 isso impediu de
    // decidir se um registro estranho era defeito do código ou de uma versão
    // antiga ainda gravada. Vai logo depois de o destino do log ser definido,
    // para ser a primeira coisa que o cartão recebe.
    log.info("boot", coruja::kVersaoBuild);
    brilho.define_presets(config.brilho_dia, config.brilho_noite);
    luz.define_duty(brilho.duty());

    // O GPS a 4 Hz e 115200: sem isto ele fala a 1 Hz e 9600, e o RF01.4
    // exige 4 Hz.
    //
    // O comentário que estava aqui dizia que falhar "só o deixa mais lento".
    // **Não é verdade, e custou uma viagem inteira sem fix em 08/10/2026**:
    // quando o passo 1 não acha o módulo, a porta não é reconfigurada e o
    // aparelho fica lendo um fluxo ilegível — mudo, não lento. Descartar este
    // retorno era jogar fora o único aviso que existia.
    coruja::ConfiguradorGps configurador(uart, pausa);
    const coruja::ResultadoConfigGps desfecho = configurador.executa(log);
    if (desfecho != coruja::ResultadoConfigGps::Configurado) {
        char aviso[160];
        std::snprintf(aviso, sizeof aviso,
                      "configuracao incompleta (%s); a porta ficou em %lu. "
                      "Se nao houver fix, e aqui que se procura",
                      coruja::descreve(desfecho),
                      static_cast<unsigned long>(configurador.baud_final()));
        log.error("gps", aviso);
    }

    coruja::PilotoAlerta piloto(gps, led, buzzer);
    const BaseCarregada base = carrega_base(cartao, log);
    piloto.define_base(g_pontos, base.pontos);
    // A linha de `carrega_base` diz quantos pontos o ARQUIVO tinha; esta diz
    // quantos chegaram a quem alerta. Eram a mesma coisa em todo log que
    // examinei, e é justamente por isso que vale registrar as duas: quando
    // divergirem, o log aponta o elo em vez de deixar deduzir.
    {
        char msg[96];
        std::snprintf(msg, sizeof msg, "piloto recebeu %u pontos",
                      static_cast<unsigned>(base.pontos));
        if (base.pontos == 0) {
            log.error("base", "piloto recebeu ZERO pontos: nao havera alerta");
        } else {
            log.info("base", msg);
        }
    }

    // O relogio comeca ZERADO: o RP2350 nao tem bateria nele, e zero e
    // exatamente o que se quer dizer -- ninguem acertou a hora nesta ligacao.
    relogio.inicia();
    if (!http.define_token(config.token_aparelho)) {
        // Sem token o servidor recusa com 401, e o log diz por que. Seguir com
        // um token que traz `\r\n` seria mandar cabecalho que ninguem
        // escreveu de proposito.
        log.error("cfg", "token_aparelho tem caractere invalido: ignorado");
    }

    coruja::SincronizadorHora sincronizador(relogio, ntp);
    RecarregadorDoCartao      recarregador(cartao);
    // O relogio e acertado pelos ORQUESTRADORES, logo depois de a rede
    // subir -- nunca antes. Ver `PreparoDeSessao`.
    RelogioAntesDoTls         preparo(sincronizador, gps);

    coruja::OtaNaTela      ponte{visor, led, pausa};
    coruja::AtualizadorOta ota(cartao, rede, http, pausa, &ponte, &preparo);
    coruja::RemessaNaTela  ponte_remessa{visor, led, pausa};
    coruja::RemessaDados   remessa(cartao, rede, http, &ponte_remessa,
                                   &preparo);
    AcoesDoAparelho        acoes(cartao, ota, ponte, remessa, ponte_remessa,
                                 piloto, led, buzzer, pausa, encoder, log,
                                 http, sincronizador, recarregador, gps,
                                 preparo);
    acoes.define_base(base);

    coruja::Aplicacao app(gps, encoder, piloto, brilho, cartao, acoes, log,
                          config, g_trabalho_cfg, sizeof g_trabalho_cfg,
                          &visor);
    app.define_versao(coruja::kVersaoBuild);
    app.define_base_carregada(base.cabecalho, base.pontos);

    // Temperatura da pastilha, no boot e a cada cinco minutos.
    //
    // Existe por um caso de campo: em 08/10/2026 o aparelho passou ~20 min sem
    // fix depois de o carro parar e voltar a andar, e a temperatura e uma das
    // suspeitas -- o painel mediu 92 °C (R-65) e o NEO-M8N e especificado ate
    // 85. Ninguem mediu o que acontece DENTRO do gabinete, e sem serie
    // temporal nao ha como separar "esquentou" de "coincidencia".
    //
    // ⚠️ Mede a PASTILHA do RP2350, nao o ar nem o modulo GPS. Serve para a
    // tendencia, nao para o valor absoluto. Ver `Termometro.h`.
    //
    // So o numero. A origem ja diz `temp`, a unidade e sempre Celsius, e que a
    // primeira linha e do boot se ve pela posicao -- repetir isso em cada
    // linha e ruido num arquivo que sobe pela rede.
    const auto registra_temperatura = [&log]() {
        float c = 0.0F;
        if (!coruja::temperatura_do_chip(&c)) { return; }
        char msg[16];
        std::snprintf(msg, sizeof msg, "%.1f", static_cast<double>(c));
        log.info("temp", msg);
    };
    registra_temperatura();

    // **O log não dizia uma palavra durante a viagem.** Até 09/10/2026 ele
    // cobria só o boot: nenhuma das cinco viagens gravadas no cartão aparecia
    // nele, nem a abertura do arquivo. Quando uma viagem registrou zona
    // "segura" do começo ao fim passando a 43 m de um radar, não havia como
    // saber se o piloto tinha base, se tinha fix, ou o que ele via — e o
    // defeito ficou sem causa isolada.
    //
    // Uma linha a cada cinco minutos responde as três perguntas e custa doze
    // linhas por hora de viagem.
    const auto registra_vigilia = [&log, &piloto, &gps](std::uint32_t t_ms) {
        char msg[96];
        std::snprintf(msg, sizeof msg, "base %u pts | fix %s | zona %u",
                      static_cast<unsigned>(piloto.pontos_da_base()),
                      gps.tem_fix(t_ms) ? "sim" : "NAO",
                      static_cast<unsigned>(piloto.veredito().zona));
        log.info("vigia", msg);
    };

    log.info("boot", "pronto");
    log.descarrega();
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

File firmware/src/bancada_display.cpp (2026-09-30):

// Bancada do display: as TELAS DE VERDADE no painel real.
//
// Não é mais maquete. O que roda aqui é a `TelaPrincipal` e o `TelaMenu` do
// produto, através do `VisorSt7789` — as mesmas classes que a suíte de host
// exercita contra um dublê. O que esta bancada acrescenta é a única coisa
// que o host não dá: **olhar**.
//
// Não há GPS nem cartão. A telemetria é roteirizada, porque o objetivo é
// julgar tela e não integração — e porque o GPS ainda não foi montado.
//
//   girar   ajusta o brilho (e a faixa superior mostra "BRILHO n%",
//           exatamente como no produto), ou navega o menu quando ele
//           estiver aberto
//   clicar  avança o roteiro; no cenário PARADO, abre o menu
//
// As cinco etapas de diagnóstico da primeira ligação continuam aqui, atrás
// de `kDiagnosticoCompleto`. Foram elas que isolaram alimentação, fiação,
// velocidade e inversão, e serão elas de novo quando a segunda unidade for
// montada — que é uma primeira ligação inteira outra vez.

#include <cstdio>

#include <pico/stdio_usb.h>
#include <pico/stdlib.h>

#include "display/Brilho.h"
#include "display/PainelSt7789.h"
#include "display/RetroiluminacaoPwm.h"
#include "display/TelaMenu.h"
#include "display/TelaPrincipal.h"
#include "display/VisorSt7789.h"
#include "encoder/EncoderKy040.h"
#include "led/LedRgbAnodoComum.h"
#include "menu/MenuAjustes.h"
#include "placa/Pinos.h"

using namespace coruja;

namespace {

/// As cinco etapas de diagnóstico ficam desligadas por padrão: levam ~1 min,
/// e 30 s disso é pulso de pinos para multímetro. Era essencial enquanto o
/// painel não desenhava; com ele validado, é espera pura. Trocar para `true`
/// religa — ver R-63.
constexpr bool kDiagnosticoCompleto = true;

constexpr std::uint32_t kEtapaMs = 3000;

LedRgbAnodoComum* g_led = nullptr;

void pisca_etapa(const Cor& cor, int quantas) {
    if (g_led == nullptr) { return; }
    for (int i = 0; i < quantas; ++i) {
        g_led->define_cor(cor);
        sleep_ms(120);
        g_led->define_cor(cores::kApagado);
        sleep_ms(120);
    }
    g_led->define_cor(cor);
}

void anuncia(const char* texto) { std::printf("\n=== %s\n", texto); }

void mostra(PainelSt7789& painel, const char* nome, std::uint16_t cor) {
    std::printf("  %s\n", nome);
    painel.limpa(cor);
    sleep_ms(kEtapaMs);
}

void rampa(RetroiluminacaoPwm& luz) {
    anuncia("1/5 rampa do backlight (sem SPI)");
    std::printf("  se nao acender, o problema e VCC, GND ou BL\n");
    for (int pct = 0; pct <= 100; pct += 5) {
        luz.define_duty(static_cast<std::uint16_t>(pct * 655));
        sleep_ms(60);
    }
    luz.define_duty(65535);
}

/// Pulsa um pino de cada vez a 1 Hz, para medição com multímetro no pino
/// **do módulo**. Prova a fiação antes de acusar o protocolo: um `DC` ou
/// `CS` trocado dá exatamente o mesmo sintoma que um clock rápido demais.
void continuidade() {
    anuncia("2/5 continuidade dos pinos de controle");
    const struct { const char* nome; unsigned pino; } linhas[] = {
        {"CS",  pinos::kDisplayCs},  {"DC",  pinos::kDisplayDc},
        {"RST", pinos::kDisplayRst}, {"SCL", pinos::kDisplaySck},
        {"SDA", pinos::kDisplayMosi},
    };
    for (const auto& l : linhas) {
        std::printf("  %s (no pino do modulo)\n", l.nome);
        gpio_set_function(l.pino, GPIO_FUNC_SIO);
        gpio_init(l.pino);
        gpio_set_dir(l.pino, GPIO_OUT);
        for (int i = 0; i < 6; ++i) {
            gpio_put(l.pino, true);
            sleep_ms(500);
            gpio_put(l.pino, false);
            sleep_ms(500);
        }
    }
}

void varredura(PainelSt7789& painel) {
    anuncia("3/5 varredura de velocidade do SPI");
    const struct { std::uint32_t hz; const char* cor; std::uint16_t v; }
    passos[] = {
        {  500000, "AZUL      (0,5 MHz)", 0x001F},
        { 4000000, "VERMELHO  (4 MHz)",   0xF800},
        {16000000, "AMARELO   (16 MHz)",  0xFFE0},
        {32000000, "BRANCO    (32 MHz)",  0xFFFF},
    };
    for (const auto& p : passos) {
        painel.inicia(p.hz);
        std::printf("  %s -- efetivo %lu Hz\n", p.cor,
                    static_cast<unsigned long>(painel.baud_efetivo()));
        painel.limpa(p.v);
        sleep_ms(kEtapaMs);
    }
    painel.inicia();
}

void orientacao(PainelSt7789& painel) {
    anuncia("5/5 orientacao");
    std::printf("  barra branca no TOPO, quadrado vermelho no canto\n"
                "  SUPERIOR ESQUERDO, faixa azul fina embaixo\n");
    painel.limpa(0x0000);
    painel.preenche(0, 0, tela::kLargura, 12, 0xFFFF);
    painel.preenche(0, 0, 40, 40, 0xF800);
    painel.preenche(0, tela::kAltura - 6, tela::kLargura, 6, 0x001F);
    sleep_ms(kEtapaMs * 2);
}

// ------------------------------------------------------ roteiro de telas

Ponto ponto(std::uint8_t limite, TipoPonto tipo) {
    Ponto p{};
    p.limite = limite;
    p.tipo = tipo;
    p.sentido = Sentido::Omnidirecional;
    return p;
}

/// Um instante da direção, montado à mão.
///
/// As velocidades contam uma história coerente com o RF03 — limite de 60,
/// `V_infra` de 66 — e os dois últimos cenários existem para julgar o
/// layout nos extremos: `120/120` é o pior caso de largura (R-64) e o
/// PARADO é onde o menu abre.
struct Cena {
    const char* nome;
    float       velocidade;
    bool        tem_alvo;
    std::uint8_t limite;
    TipoPonto   tipo;
    Zona        zona;
    float       distancia_m;
    bool        tem_fix;
    bool        base_ok;
};

constexpr Cena kRoteiro[] = {
    {"segura, sem ponto",   58, false,  0, TipoPonto::RadarFixo,
     Zona::Segura, 0, true, true},
    {"aproximacao 62/60",   62, true,  60, TipoPonto::RadarFixo,
     Zona::AproximacaoConforme, 240, true, true},
    {"margem 67/60",        67, true,  60, TipoPonto::RadarFixo,
     Zona::AproximacaoMargem, 150, true, true},
    {"perigo 74/60",        74, true,  60, TipoPonto::RadarFixo,
     Zona::Perigo, 60, true, true},
    {"semaforo, sem limite", 48, true,  0, TipoPonto::SemaforoCamera,
     Zona::Semaforo, 180, true, true},
    {"semaforo COM radar",  63, true,  60, TipoPonto::SemaforoComRadar,
     Zona::AproximacaoMargem, 120, true, true},
    {"rodovia 120/120",    120, true, 120, TipoPonto::RadarFixo,
     Zona::Perigo, 90, true, true},
    {"sem sinal",           0, false,  0, TipoPonto::RadarFixo,
     Zona::SemSinal, 0, false, true},
    {"base indisponivel",  55, false,  0, TipoPonto::RadarFixo,
     Zona::SemSinal, 0, true, false},
    {"PARADO -- gire para abrir o menu", 0, false, 0, TipoPonto::RadarFixo,
     Zona::Segura, 0, true, true},
};
constexpr int kQuantasCenas = static_cast<int>(sizeof kRoteiro /
                                               sizeof *kRoteiro);
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

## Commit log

2026-09-17 feat: detector de radares GPS embarcado em Raspberry Pi Pico 2 W
    Projeto pessoal de estudo em sistemas embarcados: alertador de radares e
    semáforos sobre RP2350, firmware em C++17 com Pico SDK. Lê telemetria de um
    GPS NEO-M8N por UART, confronta a posição com uma base local de 18.294 pontos
    e sinaliza em quatro zonas por display, LED RGB periférico e buzzer.
    Especificação e engenharia
    --------------------------
    requirements.md requisitos funcionais e não-funcionais, matriz de interação
    homem-máquina e fluxo de telas. Limiar de infração calculado
    sobre a tolerância legal com margem de segurança própria;
    buzzer escalonado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
    [coruja_gps.fzz]
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2026-09-17 feat: esqueleto do firmware com nucleo testado e os ADRs de base
    Primeira implementação, seguindo o coding_rules.md. Cobre o que não depende
    dos módulos de display e GPS, que ainda não chegaram.
    Núcleo, lógica pura sem uma linha de hardware:
    - TipoPonto, Sentido e Ponto espelhando o formato_radares.py, com as
    propriedades derivadas afere_velocidade e e_semaforo.
    - Geo: distância equirretangular e diferença circular de rumo. A diferença
    circular é o que corrige o wraparound do R-04, e há teste varrendo 360x360
    para garantir que o resultado nunca sai de [0, 180].
    - LimiarInfracao: o V_infra do RF03.6, com teste afirmando que o limiar do
    projeto vem sempre ANTES do legal,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
    [main.cpp]
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2026-09-17 feat: LED RGB e encoder KY-040, com modo de teste de bancada
    Implementa os dois componentes que já estão em mãos, separando lógica pura de
    hardware conforme o docs/adr/0001.
    Lógica pura, testada no host com 100% de linhas e de ramos:
    - DecodificadorQuadratura: tabela de transição de 16 entradas em vez de
    comparação de bordas. A diferença importa: uma transição impossível — os
    dois canais mudando na mesma amostra — contribui zero em vez de virar meio
    passo. É o bug clássico que faz o brilho saltar, e o KY-040 é ruidoso o
    bastante para produzi-lo. Há teste alternando 200 vezes em cima de uma borda
    e exigindo zero passo líquido.
    - AntiRepique: filtro da chave c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
    [main.cpp]
2026-09-17 fix: fecha o Ponto em 12 B e separa capacidade do teto de formato
    A primeira compilação para ARM, com o toolchain oficial, revelou dois erros
    de orçamento de memória que os 92 testes de host não podiam pegar, porque
    nenhum dos dois é erro de lógica.
    sizeof(Ponto) era 16 B, não 12. Eu havia expandido o rumo para uint16_t em
    graus por conveniência, e o padding de alinhamento empurrou a struct. A base
    real passaria de 214,4 para 285,8 KiB, e o teto de 40.000 pontos daria
    625 KiB — mais que a SRAM inteira. O teto de proteção de memória não
    protegia nada. Agora o rumo fica quantizado como no arquivo, com acessor
    rumo_graus(); a quantização é irrelevante para o RF02.3, cujo filt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
    [main.cpp]
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2026-09-18 fix: tabela de pinagem do GPS e ordem corrigida no gerador
    O GPS era o único dos três módulos de pinagem não óbvia SEM tabela de
    pinagem física no bom_schematic — apesar de ser aquele onde um erro de
    VCC/GND seria destrutivo. E o gera_fritzing.py assumia VCC, GND, TX, RX,
    enquanto a foto do anúncio do módulo efetivamente comprado mostra
    VCC, RX, TX, GND: pinos 2 e 4 trocados. Registrado como R-34.
    Cria a tabela na seção 3 no mesmo formato das outras duas, corrige a ordem
    no gerador e acrescenta ao checklist de pré-energização o item de conferir a
    serigrafia antes de ligar.
    A confiança está marcada como não confirmada, porque a origem é a foto do
    anúncio e não a peça e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
    [coruja_gps.fzz]
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2026-09-19 feat: modo de calibração do LED, para fechar a metade aberta do R-05
    Os resistores foram medidos em 19/09. O que falta são as razões de PWM do
    âmbar e do rosa, e isso não se mede com multímetro: depende de razão
    percebida, e o olho não é linear.
    Girar ajusta o canal variável do item atual; clicar avança por vermelho,
    verde, azul, âmbar e rosa, circularmente. Ao dar a volta, o log imprime o
    bloco pronto para transcrever no gera_config.py.
    Nas compostas o vermelho fica fixo em 100% e o encoder move o outro canal.
    Não é simplificação arbitrária: é o formato que o ConfigCalibracao.h espera,
    com kDutyAmbarVermelho em 1,0 e kDutyAmbarVerde como a variável. E os valores
    inicia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
    [main.cpp]
2026-09-19 fix: os 100 nF de debounce matavam a quadratura; R-05 concluído
    Dois achados da bancada de 19/09, um deles fechando uma pendência antiga e o
    outro corrigindo um erro meu de especificação.
    R-36: os capacitores de 100 nF em CLK e DT impediam qualquer decodificação de
    giro. Medido na placa com amostragem a 50 us, com e sem os capacitores:
    com 100 nF sem capacitor
    fase (0,1) 0,6 - 2 ms 45 - 128 ms
    estado (0,0) NUNCA ocorreu 5,75 - 25,4 ms
    passos decodificados zero quadratura integra
    Os 100 nF com o pull-up de 10 kOhm do modulo dao tau = 1 ms. Contra fases que
    duram dezenas de milissegundos, o filtro comprimia puls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
    [diagnostico.cpp]
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2026-09-22 feat: log_to_sd e log_level -- log no cartao, com filtro de nivel
    Duas chaves novas no coruja.cfg. log_to_sd grava todas as mensagens em
    coruja.log, no cartao; log_level filtra por debug/info/warning/error, sem
    diferenciar maiusculas e aceitando 'warn' porque e o que se digita. Valor nao
    reconhecido MANTEM o padrao e conta no diagnostico -- um log_level errado nao
    deve impedir o aparelho de operar, mas tem de aparecer.
    log_to_sd vem desligado: escrita de cartao tem ciclos finitos, e isto e
    recurso para ficar ligado enquanto se caca um defeito.
    A configuracao passou a ser lida TAMBEM no boot. Sem isso o log so comecaria
    no primeiro clique e o boot inteiro ficaria de fora do arquivo -- e o b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
    [main.cpp]
2026-09-24 feat: parser NMEA da RMC e simulador de GPS sobre o Eixao
    Duas metades do bloco de GPS, ambas sem depender do modulo chegar.
    O parser cobre o RF01.1: aceita GNRMC e GPRMC, valida checksum, confere o
    status A/V, converte graus-minutos e nos para km/h, e le data e hora, que o
    relogio da tela precisa porque nao ha RTC com bateria no BOM.
    Tres decisoes que os testes travam:
    - Rumo VAZIO com o veiculo parado nao e erro. O NEO-M8N nao informa direcao
    sem deslocamento. Tratar como erro descartaria todo fix parado; tratar como
    zero apontaria o veiculo para o norte.
    - Status V devolve SemFix SEM TOCAR no destino: sentenca sem fix nao pode
    apagar a ultima posicao conhecida.
    - Aceita qualquer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
    [rota_eixao.csv]
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2026-09-25 feat: buzzer soldado direto e sem diodo (caixa Patola)
    Com a caixa em maos, os dois fios do buzzer saem da placa soldados direto ao
    SFM-27 no painel, e o 1N4148 em antiparalelo saiu do projeto. O ramo ficou
    com quatro nos: +12 V -> BZ, BZ -> coletor, emissor -> GND, base -> R4 ->
    GPIO 5.
    SOLDAR APAGA UM RISCO EM VEZ DE ADMINISTRA-LO. O R-06 trocou o Jack P2 por um
    JST e o ADR 0009 trocou o JST por header generico; cada passo administrou
    melhor a mesma falha -- plugar a coisa errada no soquete errado -- sem
    elimina-la, e o header generico ate piorou, por nao ser polarizado. Agora ha
    um unico conector externo e nao existe par para trocar. O preco e servico:
    separar a tampa exige dessoldar. Es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
    [coruja_gps.fzz]
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2026-09-27 chore: contorno de PCB e textos de serigrafia no .fzz
    Ajuste de layout do autor: um retangulo de PCB e dois textos. Sem efeito
    eletrico.
    Verificado antes de publicar, que e a regra do R-51: netlist derivada das
    tres vistas e comparada com a versao publicada -- redes identicas em
    breadboard, esquematico e PCB, 150 fios preservados. A conferencia existe
    porque rotear no Fritzing ja soltou as ligacoes do buzzer no esquematico e no
    PCB sem dar sinal alugm: a vista que se olha para montar era a que estava
    certa.
    [coruja_gps.fzz]
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2026-09-28 refactor: OTA recebe interfaces, e 310 linhas saem da placa para o host
    O AtualizadorOta recebia CartaoSd& e RedeWifi& -- classes CONCRETAS, sem
    metodo virtual, cujas bibliotecas nem sao compiladas no alvo de host. A troca
    atomica do RF05.2, as tres retentativas e todo o tratamento de falha so
    existiam na placa, e sao exatamente os caminhos que a bancada nao consegue
    provocar: o cartao enchendo no meio do download, a renomeacao falhando, a
    base chegando corrompida.
    O projeto ja tinha a regra certa e a aplicava -- LedRgb e Buzzer sao
    interfaces com porte separado. Armazenamento e rede ficaram de fora, e
    ninguem notou porque o OTA FUNCIONAVA: foi validado de ponta a ponta com base
    real, Wi-Fi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
    [main.cpp]
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2026-09-28 feat: previa do produto no terminal, e o radar movel sem icone proprio
    Com os modulos de GPS e de tela ainda nao entregues, o produto inteiro passa
    a rodar no host. LeitorGps, PilotoAlerta, MaquinaZona, TelaPrincipal,
    CadenciaBuzzer e PadraoLed sao os MESMOS objetos que o main.cpp vai
    instanciar; trocam-se tres portes de saida -- UART vira pty, painel vira
    ANSI, LED e buzzer viram texto.
    Rodado contra o simulador: 500+ fixes a 4 Hz sem erro, chegando a
    aproximacao/margem e a perigo, com o numero em 63/60 e 75/60, a barra
    enchendo conforme se aproxima e o LED acompanhando.
    O x DO TEXTO SIGNIFICAVA DUAS COISAS. Visor::texto recebia x como centro
    para Fonte::Numero e como borda esquerda para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
    [previa_produto.cpp]
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2026-09-30 fix: texto que nao cabe rola, e o que da para encurtar foi encurtado
    Tres pedidos do autor, e o terceiro expos um defeito meu.
    TRUNCAMENTO SILENCIOSO
    A fonte de texto tem 12 px por glifo e a tela 320: o teto e 26
    caracteres. SEIS das nove frases do projeto estouravam, e o painel
    descartava glifos INTEIROS nas duas pontas sem nada avisar.
    A causa era a minha justificativa no desenha_bitmap: "recorte parcial
    nao e suportado de proposito, glifo cortado e defeito de layout, e
    engoli-lo em silencio esconderia o defeito". O efeito real era pior do
    que o defeito que ela queria evitar -- ela engolia frases inteiras.
    Agora o recorte em coluna e de verdade, inclusive parcial.
    ROLAGEM POR CARACTERE,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
    [PainelSt7789.cpp]
2026-09-30 feat: data e contagem de pontos em linhas separadas na tela de informacao
    Pedido do autor, e resolve um incomodo que eu tinha acabado de criar.
    Juntas, "base: 2026-09-15 18304 pts" davam 324 px numa tela de 320 --
    era a UNICA linha do aparelho que precisava rolar, e rolar 4 px parece
    tremor, nao rolagem. Separadas, as duas cabem com folga:
    unidade: fusca 168 px
    atualizada: 2026-09-15 264 px
    18304 pontos 144 px
    gps: 4.0 Hz 132 px
    Quatro linhas de 20 px com vao de 10 dao 110 px nos 166 da area
    central, centralizadas nela.
    "atualizada:" em vez de "base:" porque e o que o numero significa: a
    data da ultima atualizacao da base, nao um identifi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
    [bancada_display.cpp]
2026-09-30 feat: OTA na tela e no LED, com bancada gravavel
    O autor montou tudo em placa perfurada e pediu uma build com a
    atualizacao funcionando, com o LED acompanhando a tela. O OTA ja
    funcionava desde antes -- o que faltava era ele DIZER o que esta
    fazendo.
    O PROBLEMA: executa() E BLOQUEANTE
    Ele leva dezenas de segundos -- conectar, consultar, baixar 214 KB,
    gravar -- e o laco principal nao roda nesse tempo. Sem alguem
    desenhando de dentro, a tela congela no ultimo quadro e o usuario nao
    sabe se o aparelho trabalha ou travou. Antes disso o unico retorno era
    o console USB: quem olhasse o aparelho via o LED apagar e nada mais.
    ObservadorOta -- regra 2 aplicada ao TEMPO
    Oito fases, que sao as que fa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
    [bancada_ota.cpp]
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2026-10-01 feat: a falha do OTA diz o motivo e espera o usuário dispensar
    Duas coisas que o relato expôs juntas: a tela dizia só "FALHOU", e sumia em
    2,5 s.
    **O motivo.** O `ResultadoOta` já distinguia as seis causas e o log já as
    escrevia; quem não as via era a tela. "FALHOU" sozinho manda abrir o log, e
    ninguém abre log com o aparelho na mão dentro do carro. Cada causa pede ação
    diferente — senha errada, servidor fora, sinal instável e cartão ruim não se
    resolvem do mesmo jeito. Entra um `descreve_curto()` separado do `descreve()`
    porque os leitores são outros: a frase do log é lida depois, com calma; a da
    tela é lida de relance e tem 26 caracteres de faixa. "chegou integra, mas o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
    [main.cpp]
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2026-10-05 feat: projeto do KiCad gerado a partir do netlist.py
    Acrescenta a biblioteca de símbolos própria (16 símbolos) e o esquemático
    (21 peças), ambos gerados — nada é desenhado à mão. A fonte continua sendo o
    bom_schematic.md, transcrito no netlist.py e traduzido pelo kicad_mapa.py.
    O Pico é uma peça só, com o footprint oficial Module:RaspberryPi_Pico_Common_THT
    — 40 pads numerados como o pino físico, nas duas colunas a 17,78 mm. A versão
    anterior usava duas barras de 20 pinos, e isso trazia dois problemas: o
    deslocamento de 20 entre o pino físico e o pad, e — pior — a distância entre as
    fileiras não ficava escrita em lugar nenhum, de modo que a placa poderia voltar
    da fa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
    [coruja.kicad_sch]
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2026-10-06 docs: montagem.md v2 — placa fabricada, caixa impressa, antena na PCB
    A v1 descrevia uma montagem artesanal dentro de uma caixa comprada: Patola
    PB-111, chassi de placa perfurada colado com VHB, e o modulo GPS numa
    prateleira de fibra presa a tampa. As tres pecas sairam do projeto em
    2026-10-05.
    A mudanca mais consequente e a antena ir para cima da propria PCB, porque
    resolve o R-67 — a restricao mais dura que havia. O rabicho tem 8 cm e o U.FL
    aguenta 30 ciclos de encaixe; na v1 modulo e antena ficavam em planos
    diferentes e os 8 cm precisavam vencer essa distancia a cada abertura da caixa.
    Vizinhos na mesma placa, sobra cabo e o conector deixa de ser tocado.
    Ganham-se ainda o plano d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
    [coruja.kicad_pcb, coruja.kicad_sch]
2026-10-06 fix: tira do repositorio o backup do KiCad e o zip de fabricacao
    Dois arquivos entraram no commit anterior por descuido: um `git add -A` sem
    conferir o `git status` antes.
    - `kicad/_restore_backup_.../` — 792 KB de copia que o KiCad cria sozinho ao
    recuperar sessao. Ja havia regra para o nome antigo; esta vem com carimbo de
    hora diferente, entao a regra agora usa curinga.
    - `kicad/coruja_gps_jlcpcb.zip` — 124 KB. O .gitignore cobria `kicad/fabricacao/`,
    mas o zip fica um nivel acima e escapou.
    Os dois sao derivados do .kicad_pcb, que e versionado.
    ⚠️ Os blobs continuam no historico: o commit anterior ja foi publicado, e
    reescrever historico publicado e decisao do autor, nao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
    [coruja.kicad_pcb, coruja.kicad_sch]
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2026-10-06 fix: a bancada de OTA ainda usava o cliente HTTP removido
    O `bancada_ota.cpp` incluia `rede/ClienteHttp.h`, que saiu quando o
    transporte foi unificado no `ClienteTls`. A compilacao do PRODUTO nao via:
    a bancada e um alvo separado, e so o `libera_fw.sh` a compila.
    E exatamente para isso que a etapa 5 do pipeline compila os tres alvos --
    "compilar so o produto deixa as bancadas quebrarem sem ninguem ver", diz o
    comentario dela desde 2026-10-05. Hoje ela cobrou.
    A bancada NAO empresta a memoria da base nem acerta o relogio: ela existe
    para olhar a tela do OTA, e carregar a base inteira so para emprestar o
    buffer sairia do proposito. A consequencia esta anotada no arquivo -- em
    `https` ela so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
    [bancada_ota.cpp]
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2026-10-07 fix: o coruja.cfg gerado nao cabia no buffer que o firmware reserva
    leitor (main.cpp) 2048 bytes
    gravador (kMaxTextoCfg) 8192 bytes
    o que o gerador produzia 5007 bytes
    O `le_arquivo` recusa com `ArquivoGrande` quando o arquivo nao cabe. Ou seja:
    QUALQUER configuracao gerada pelo script estava grande demais para ser lida.
    O sintoma nao parecia com a causa -- "sem configuracao utilizavel" no OTA e o
    aparelho sem nome na tela de informacao, com um arquivo que lia perfeitamente
    em qualquer outra ferramenta.
    COMO PASSOU DESPERCEBIDO
    ------------------------
    O gerador foi crescendo um bloco de comentario por funcionalidade: envio,
    token, NTP, HTTPS. Cada um era pequeno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
    [main.cpp]
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2026-10-07 fix: o relogio era acertado ANTES de o radio existir, e travava o aparelho
    Sintoma, na v0.2.2: clicar em atualizar a base travava o aparelho por
    completo -- tela congelada, encoder morto, nem uma linha de log.
    A CAUSA
    -------
    `cyw43_arch_init()` so acontece dentro do `RedeWifi::conecta()`, que por sua
    vez so roda DENTRO do orquestrador. Eu pus a sincronizacao de hora no
    construtor da `SessaoDeRede`, que corre antes dele:
    SessaoDeRede ctor -> SincronizadorHora -> ClienteSntp
    dns_gethostbyname() } com a pilha de rede
    cyw43_arch_poll() } e o radio INEXISTENTES
    Nao e erro tratavel: e acesso a estado nao inicializado. Por isso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
    [main.cpp]
2026-10-07 feat: pilha de 4 KiB e medicao do pico, para o handshake caber
    O `PICO_STACK_SIZE` padrao do RP2350 e 0x800 -- 2 KiB. Um handshake do
    mbedTLS usa bem mais. Transbordar nao da erro: o guarda de pilha do RP2350
    transforma isso em falta grave, e o sintoma e o aparelho TRAVADO, sem uma
    linha de log -- o mesmo sintoma do defeito de ordem corrigido no commit
    anterior, e por isso seria confundido com ele.
    4 KiB NAO E UM NUMERO ESCOLHIDO: E O TETO
    O SDK poe a pilha do nucleo 0 em `SCRATCH_Y`, que tem 4 KiB fixos (ver
    `sections_stack.incl`). Tentei 16 KiB primeiro e o ligador recusou:
    region `SCRATCH_Y' overflowed by 12288 bytes
    Passar disso exige scri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
    [main.cpp]
2026-10-07 fix: a sessao TLS nao cabia no heap do lwIP, e a pilha era medida errado
    Primeira execucao de verdade do caminho TLS numa placa, 2026-10-07. Nao
    travou -- a correcao de ordem funcionou, o NTP acertou o relogio e o
    handshake chegou a ser tentado:
    [INFO] wifi: conectado. IP 192.168.1.235
    [INFO] hora: relogio acertado por ntp: 2026-10-07 02:48:22Z
    [INFO] http: GET https://coruja.bpldev.com:443/radares.versao
    [ERRO] http: sem memoria para a sessao TLS
    [INFO] emprestimo: pico de uso: 0 B de 287984
    (1) A MEMORIA DA SESSAO NAO VEM DA ARENA
    ----------------------------------------
    O `pico de uso: 0 B` foi a pista. A arena de 280 KB emprestada da base nao
    foi tocada, porque o mb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
    [main.cpp]
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2026-10-07 fix: o lwIP sequestrava o alocador do mbedTLS; aposenta o emprestimo da base
    Segunda medida numa placa, execucao XQ32A5XB:
    [INFO] mem: pico do heap do lwip: 32664 B de 32768
    Os dois numeros juntos contam a historia: o heap do lwIP esgotado em 99,7% e
    a arena de 280 KB INTACTA. Aumentar o `MEM_SIZE` de 4000 para 32768 so moveu
    a parede -- e o erro mudou de "sem memoria para a sessao TLS" para "conexao
    interrompida", sem nunca completar o handshake.
    O `altcp_tls_mbedtls_mem.c` do lwIP faz isto na propria inicializacao:
    mbedtls_platform_set_calloc_free(&tls_malloc, &tls_free);
    E `tls_malloc` usa `mem_malloc` -- o hea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
    [bancada_ota.cpp, main.cpp]
2026-10-07 fix: sete defeitos no caminho HTTP/HTTPS, achados em revisao critica
    Revisao linha a linha de tudo que fala HTTP no firmware, conferida contra o
    codigo do lwIP e do mbedTLS do SDK antes de cada afirmacao.
    1. Uso de memoria morta depois do tempo limite do DNS (ClienteTls e
    ClienteSntp). O lwIP nao cancela um `dns_gethostbyname`: ele guarda a
    funcao e o `arg` e chama de volta sempre, inclusive ao desistir
    (`dns.c`, `dns_call_found(i, NULL)`). Os dois passavam o endereco de uma
    variavel LOCAL e voltavam por tempo esgotado, deixando o lwIP com um
    ponteiro para quadro de pilha ja reaproveitado.
    O caminho mais curto e o NTP, e nao por pouco: o prazo dele e 5 s e o lwIP
    desis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
    [main.cpp]
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2026-10-07 fix: a remessa era cega; desvia o log em vez de desliga-lo
    O envio falhou tres vezes em campo sem deixar UMA linha no cartao nem uma
    requisicao no servidor. Nao foi azar: o caminho e cego por construcao.
    O `envia_dados()` DESLIGAVA o log em cartao durante a remessa, e com razao --
    o `coruja.log` e um dos arquivos que sobem, cada linha gravada durante o envio
    o faz crescer, e arquivo que cresceu nao e apagado. Sem isso ele subiria a
    cada remessa e nunca sairia do cartao. Mas desligado o `registra()` sai na
    primeira linha: as mensagens nem chegam ao buffer. Nao ha o que descarregar
    depois, e o unico diagnostico de um envio que falha e o texto de uma tela.
    Agora o log e DESVIADO para `remessa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
    [main.cpp]
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2026-10-08 feat: a caixa vem para ca, com o furo do conector de alimentacao
    A fonte OpenSCAD estava no repositorio privado. Nada nela e privado, e ela e o
    entregavel de quem vai imprimir -- entao muda de casa. O `montagem.md`, que
    afirmava que o modelo estava fora daqui, foi corrigido.
    **Versionada a FONTE, nao os STLs.** Cada render muda o arquivo inteiro e o git
    guarda cada versao por completo: sao ~2 MB por corpo. E a mesma razao pela qual
    o .uf2 do firmware fica em release. `caixa/gera_stl.sh` os produz.
    ## O furo do GX12-2
    Traseira, ⌀12,5 mm, CENTRADO em x. Unico conector externo do aparelho, traz os
    12 V do pos-chave.
    A escolha do GX12 sai de um criterio que o `bom_schematic.md` ja havia fi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
    [coruja_caixa.scad, coruja_caixa_destro.scad]
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2026-10-09 feat: registra a temperatura da pastilha no boot e a cada 5 min
    Relato de campo em 08/10/2026: o carro parou na escola, voltou a andar, e o
    aparelho passou ~20 minutos sem nenhum fix ate o destino. Temperatura e uma das
    suspeitas -- o painel mediu 92 °C (R-65) e o NEO-M8N e especificado ate 85 --,
    mas ninguem mediu o que acontece DENTRO do gabinete. Sem serie temporal nao ha
    como separar "esquentou" de "coincidencia".
    Fecha a pendencia M-08, que ja apontava o caminho: o RP2350 tem sensor no
    proprio die, no canal 4 do ADC, e o firmware nao usava o ADC para nada -- havia
    um termometro ocioso dentro do aparelho e um `LoggerCartao` que ja grava.
    ## A linha
    2026-10-09T12:34:56Z ABCD1234 [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
    [main.cpp]
2026-10-09 fix: o configurador assumia o baud de fabrica e deixava o aparelho mudo
    Relato de 08/10/2026: a esposa parou o carro na escola para deixar as
    criancas e, ao voltar a dirigir, nao houve um unico fix ate o trabalho --
    cerca de vinte minutos. O log do cartao mostra a cadeia inteira:
    8C2LYU9D gps: CFG-CFG persistir: ACK <- guardou 115200 na BBR
    FWUTA6LU gps: CFG-RATE 250 ms: sem resposta (tentativa 1 de 2)
    FWUTA6LU gps: CFG-RATE 250 ms: sem resposta (tentativa 2 de 2)
    FWUTA6LU boot: pronto <- e segue como se nada fosse
    O passo 4 persiste a configuracao em BBR, que a bateria de backup mantem
    por horas. Numa parada curta o modulo volta falando 1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
    [ConfiguradorGps.cpp]
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2026-10-09 fix: base vazia virava "via livre"; e o boot passa a dizer o que o piloto ve
    Investigando uma viagem de 08/10/2026 que registrou zona "segura" nos 192
    pontos, achei que ela passou a 43 m de um radar de 70 -- e por tres radares
    no total, cada um com a aproximacao caindo direitinho (203 -> 138 -> 54 m;
    65 m; 234 -> 141 -> 43 m). Nao e ruido: e o perfil de quem passa por um
    radar.
    A `confere_viagem` reproduz o caminho REAL com a base real e as posicoes
    reais -- primeiro `MaquinaZona::avalia` direto, depois UART -> `LeitorGps`
    -> `PilotoAlerta`, com RMC montada e somada. As duas passadas acham os tres
    radares. **O codigo atual esta correto, e a causa daquela viagem continua
    sem isolar.** Descar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
    [confere_viagem.cpp, main.cpp]
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
